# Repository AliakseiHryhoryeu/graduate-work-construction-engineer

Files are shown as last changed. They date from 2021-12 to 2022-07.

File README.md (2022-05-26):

# Graduate work. Construction engineer.

- Model building created in Revit 2020
- The calculation of the roof slab was carried out in Robot 2020
- A1 sheets were made in Autocad 2020
- An explanatory note was made in Microsoft Word 2019

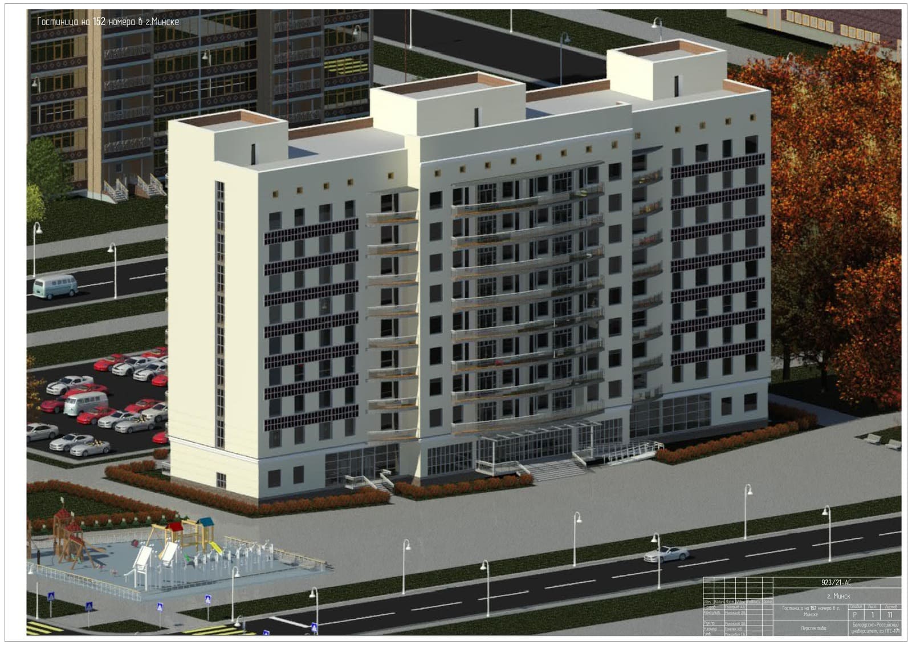
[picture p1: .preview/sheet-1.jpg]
sheet-1

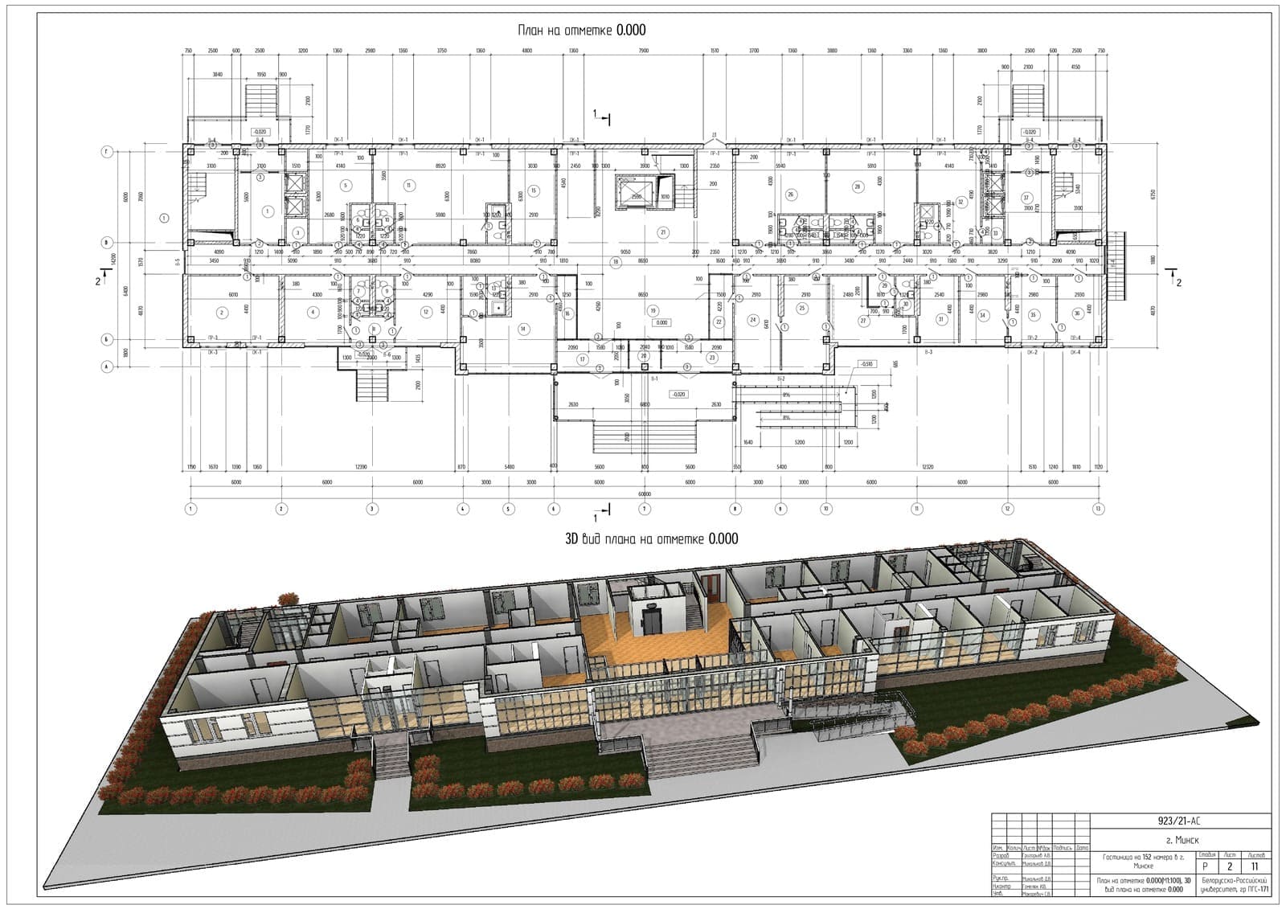
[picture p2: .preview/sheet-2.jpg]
sheet-2

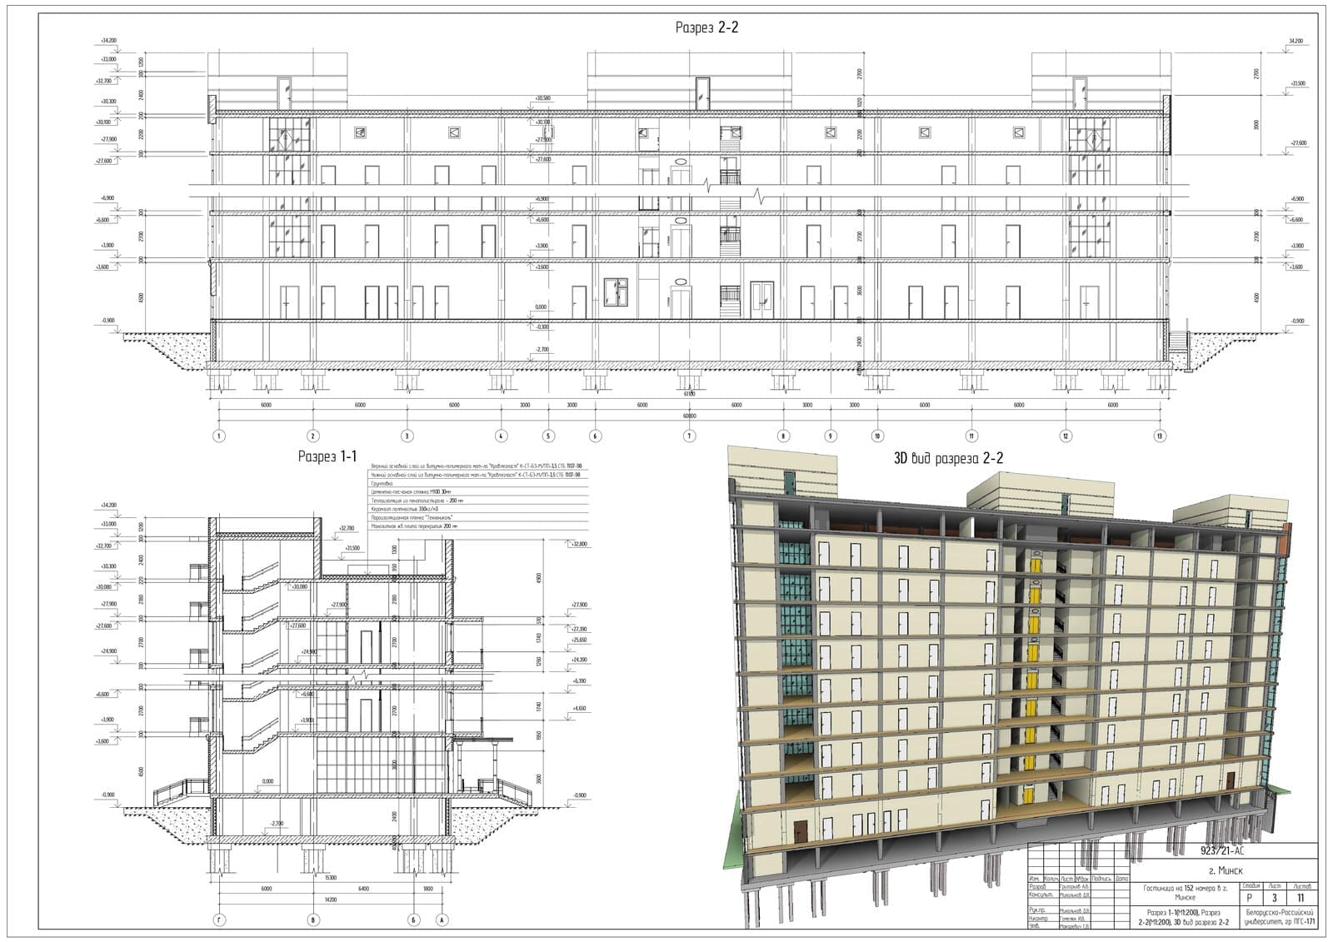
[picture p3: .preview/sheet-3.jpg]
sheet-3

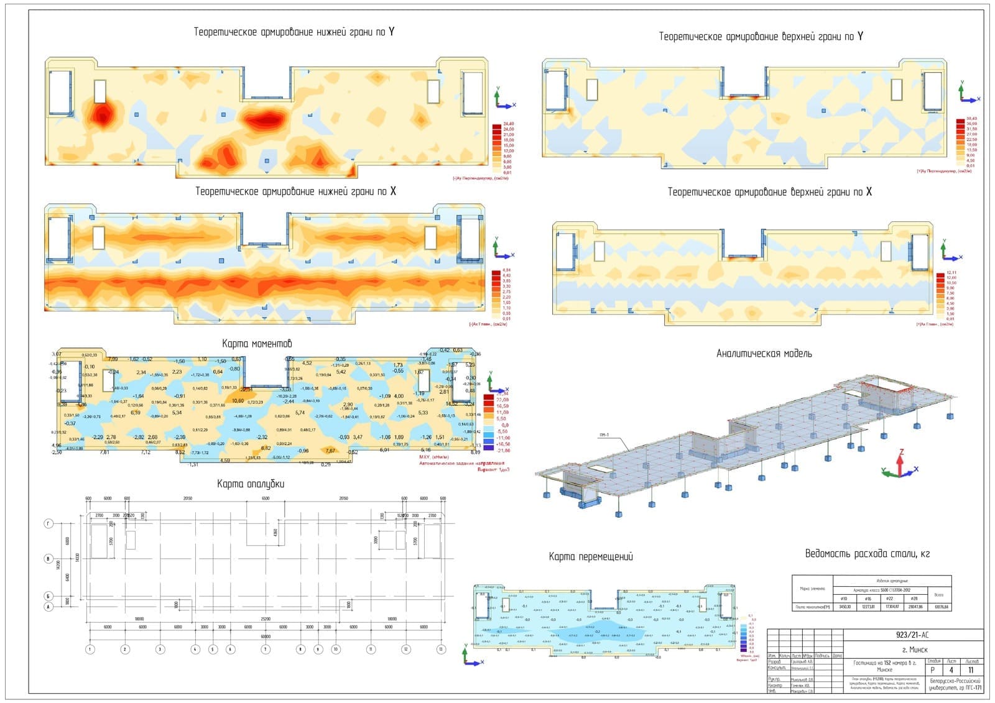
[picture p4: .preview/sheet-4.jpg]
sheet-4

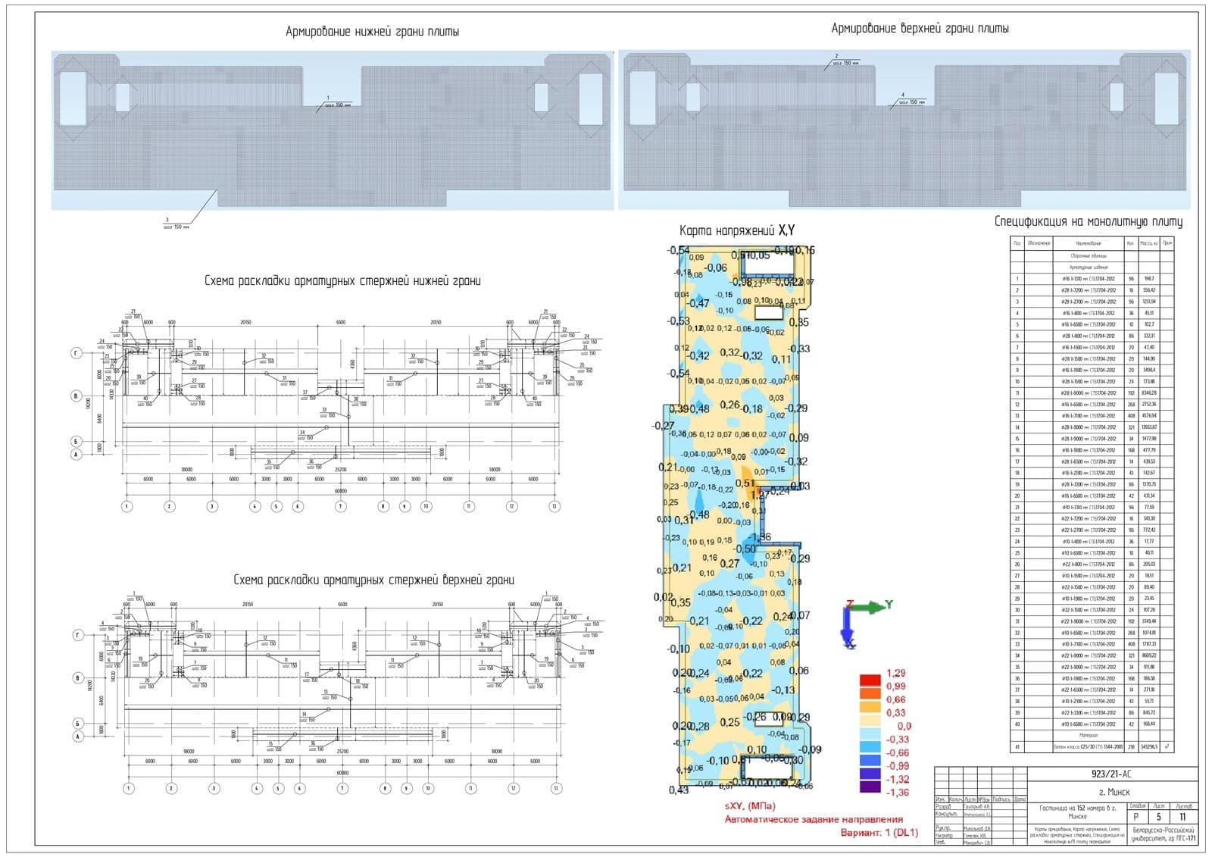
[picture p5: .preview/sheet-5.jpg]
sheet-5

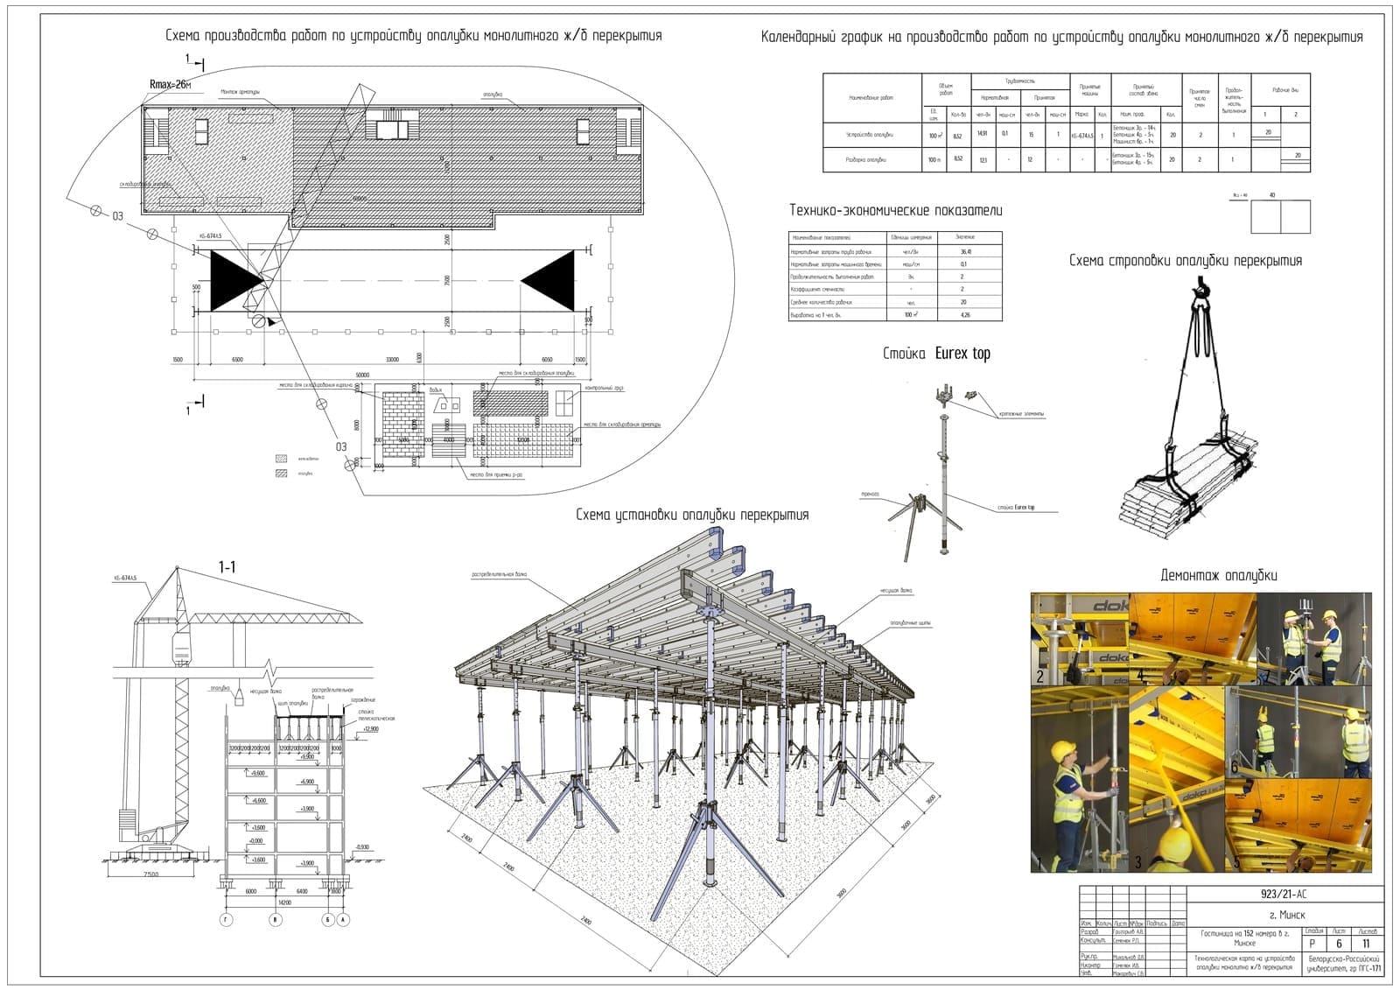
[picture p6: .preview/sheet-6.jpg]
sheet-6

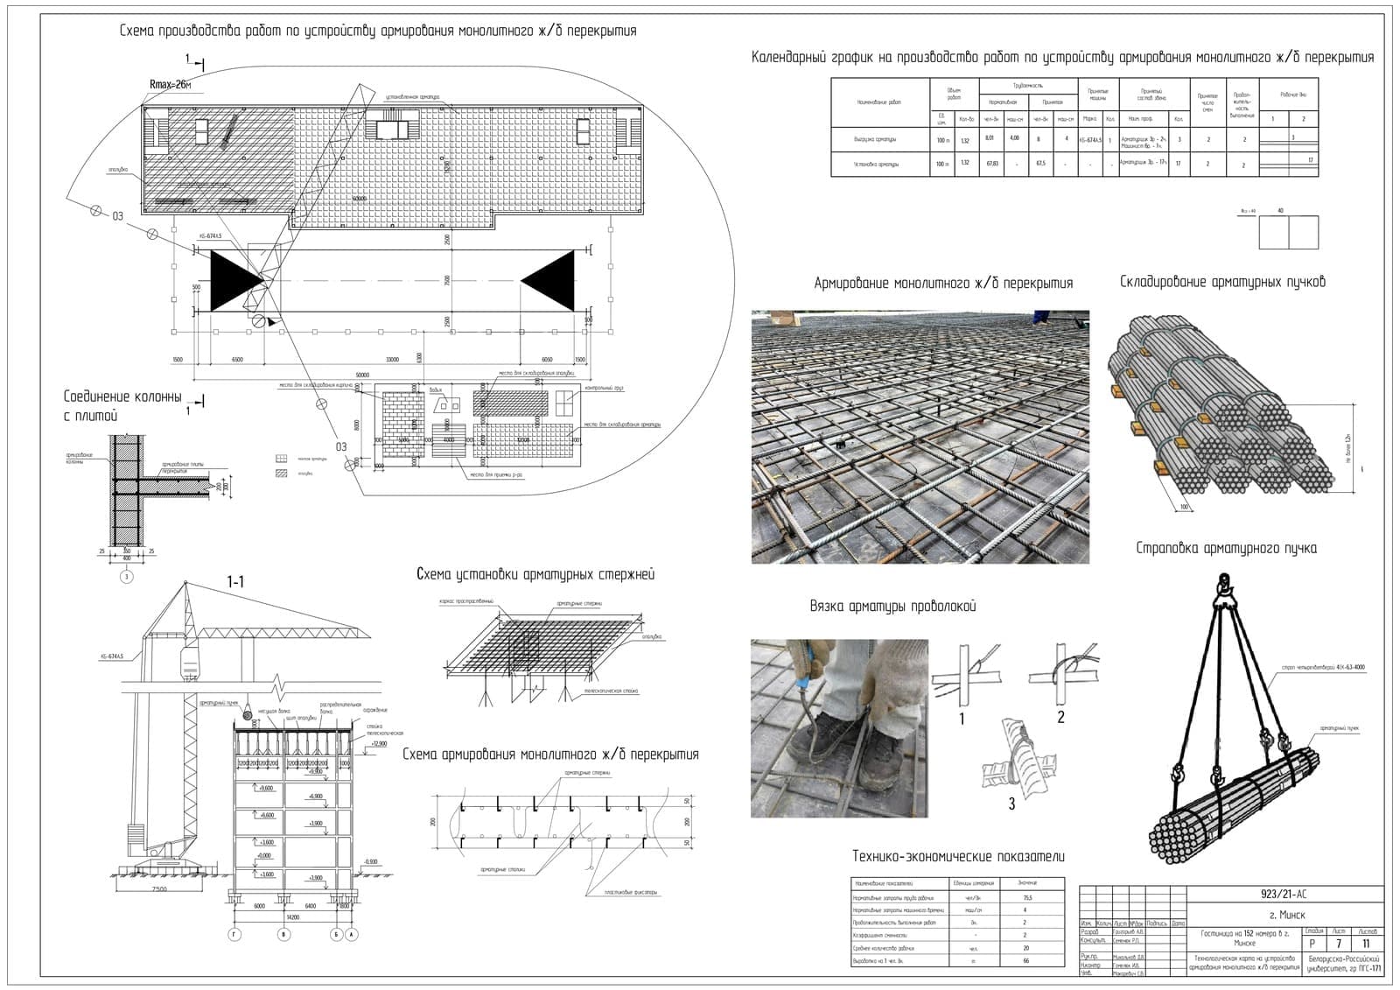
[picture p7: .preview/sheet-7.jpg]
sheet-7

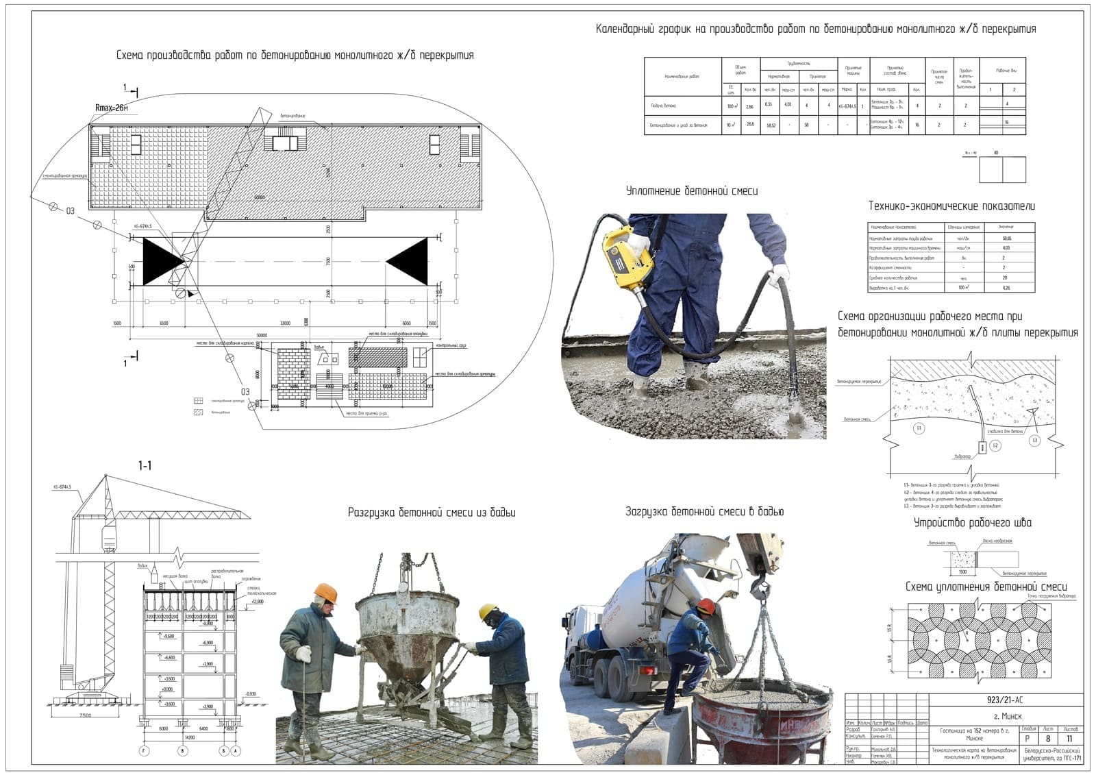
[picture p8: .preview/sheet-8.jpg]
sheet-8

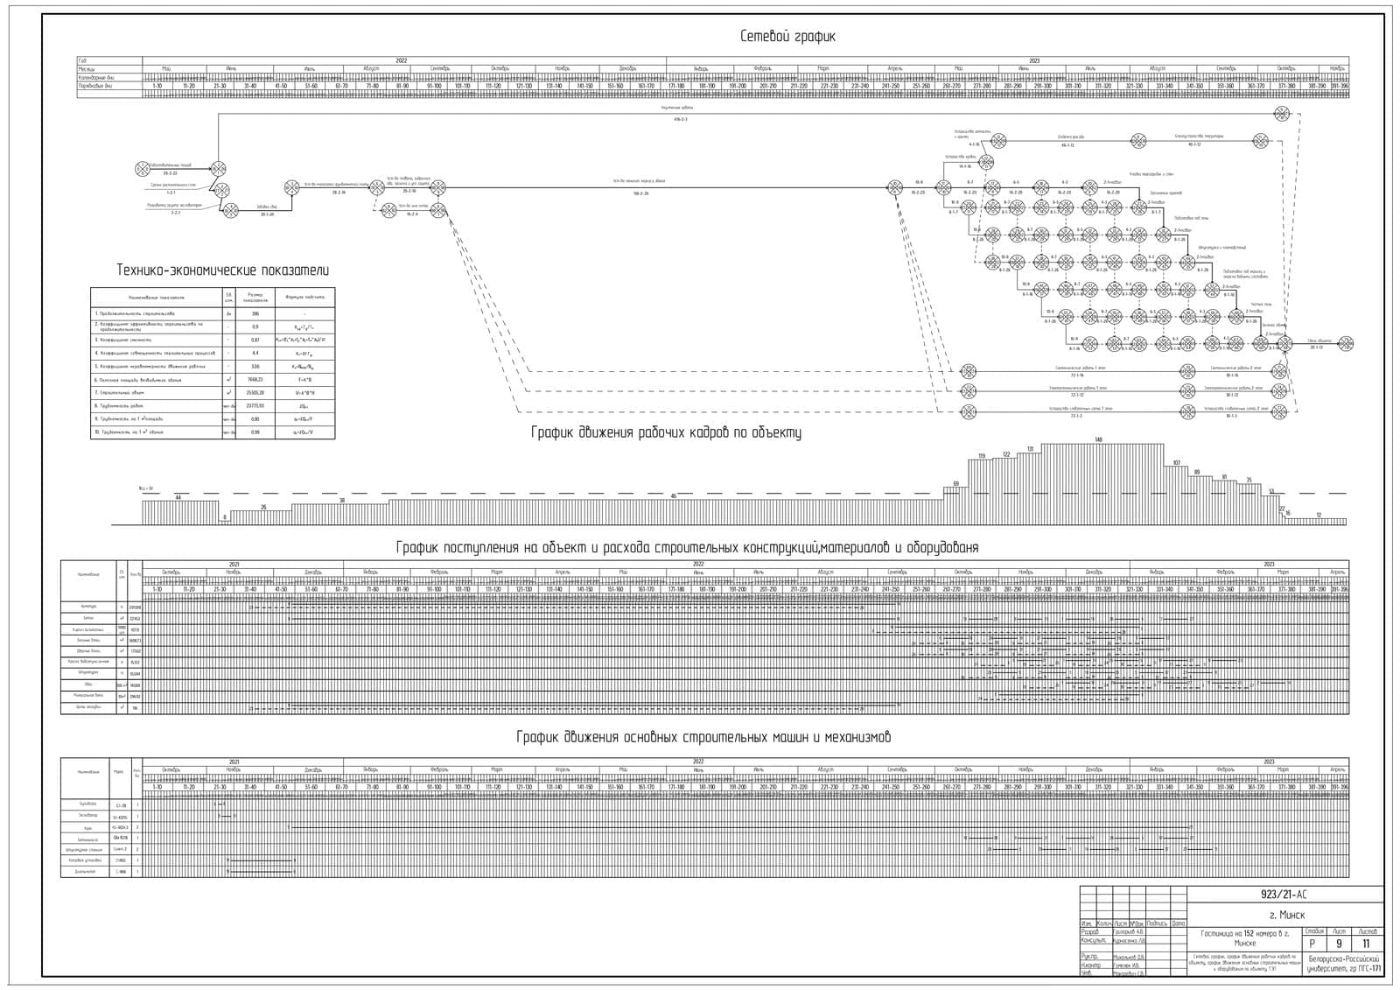
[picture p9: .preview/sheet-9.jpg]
sheet-9

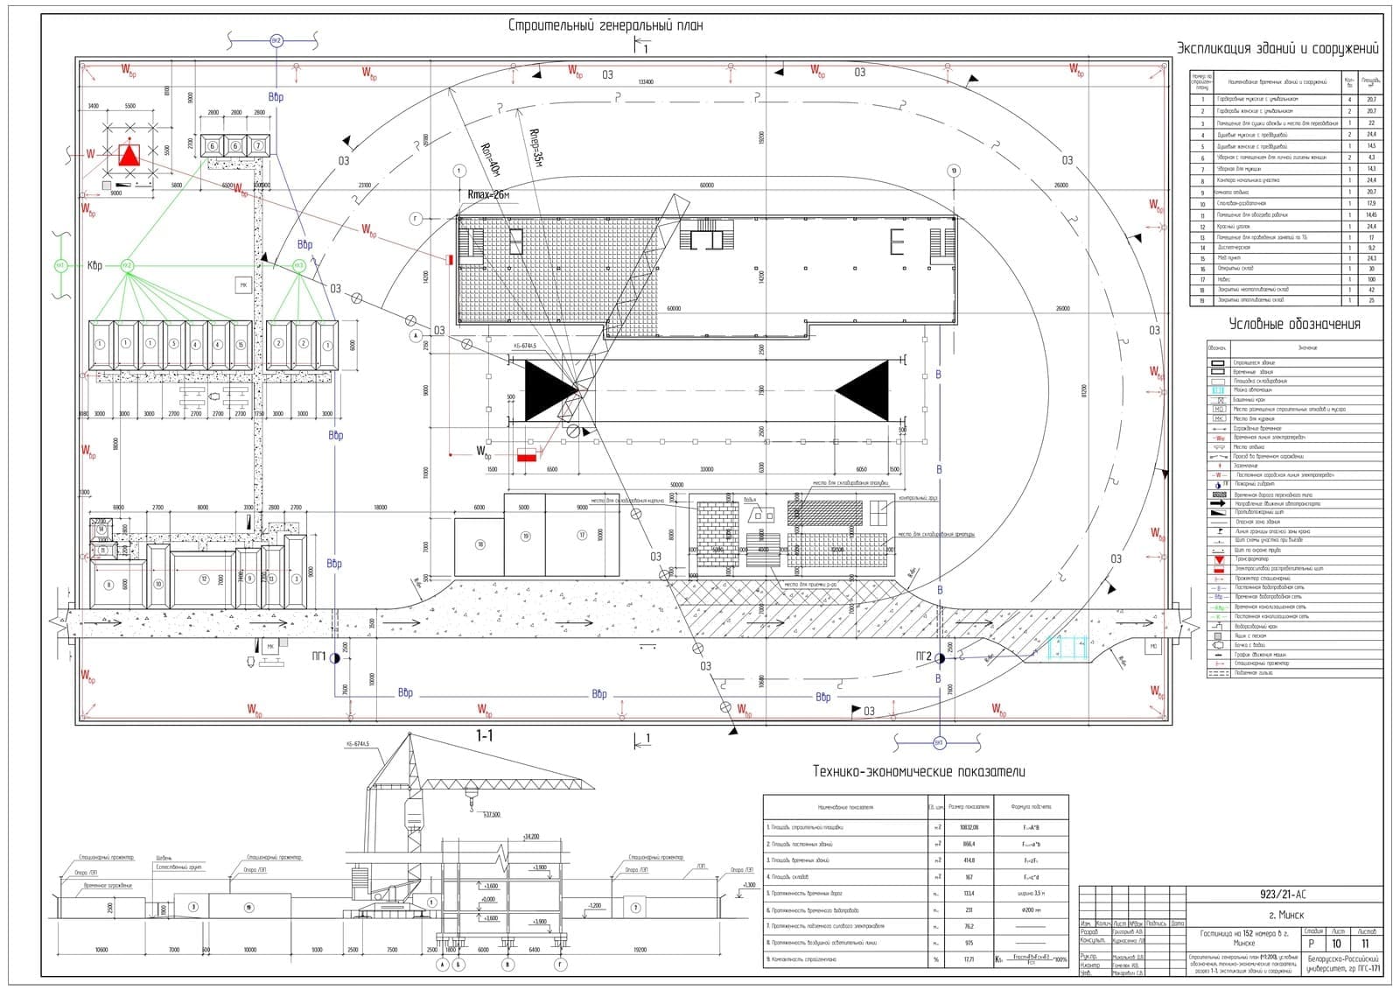
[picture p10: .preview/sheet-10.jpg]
sheet-10

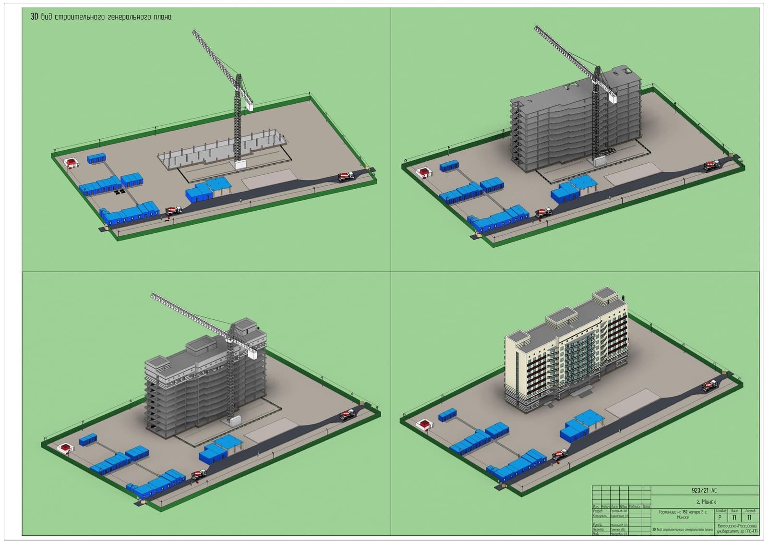
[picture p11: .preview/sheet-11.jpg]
sheet-11


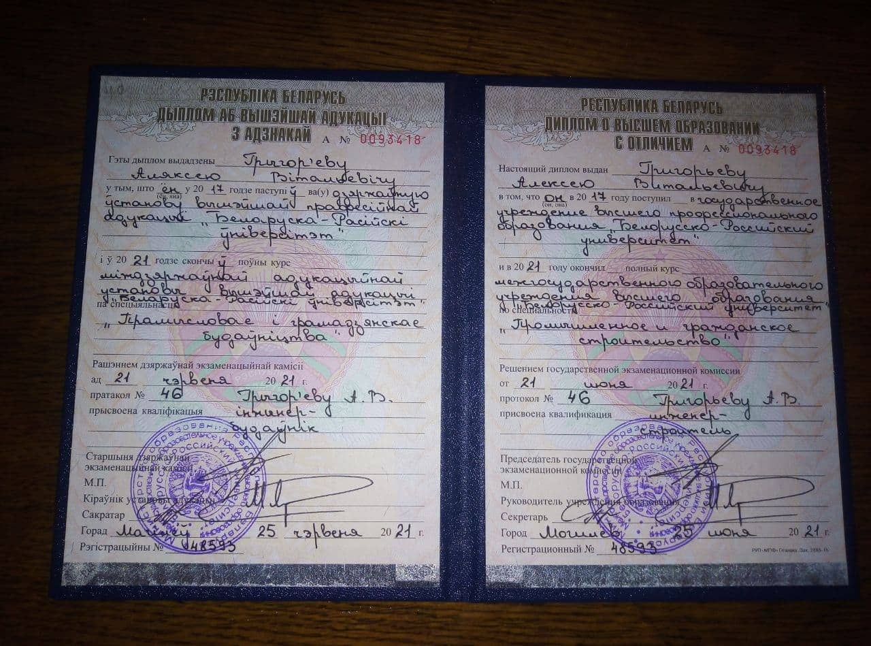
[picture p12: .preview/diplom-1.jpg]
diplom-1

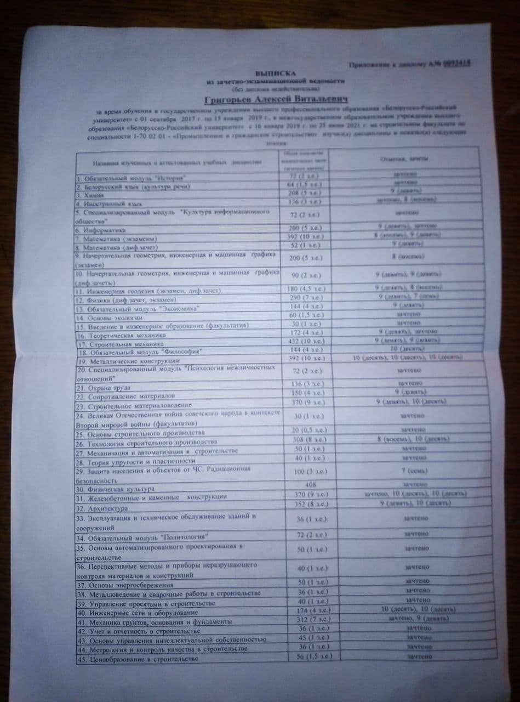
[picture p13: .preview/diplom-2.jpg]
diplom-2

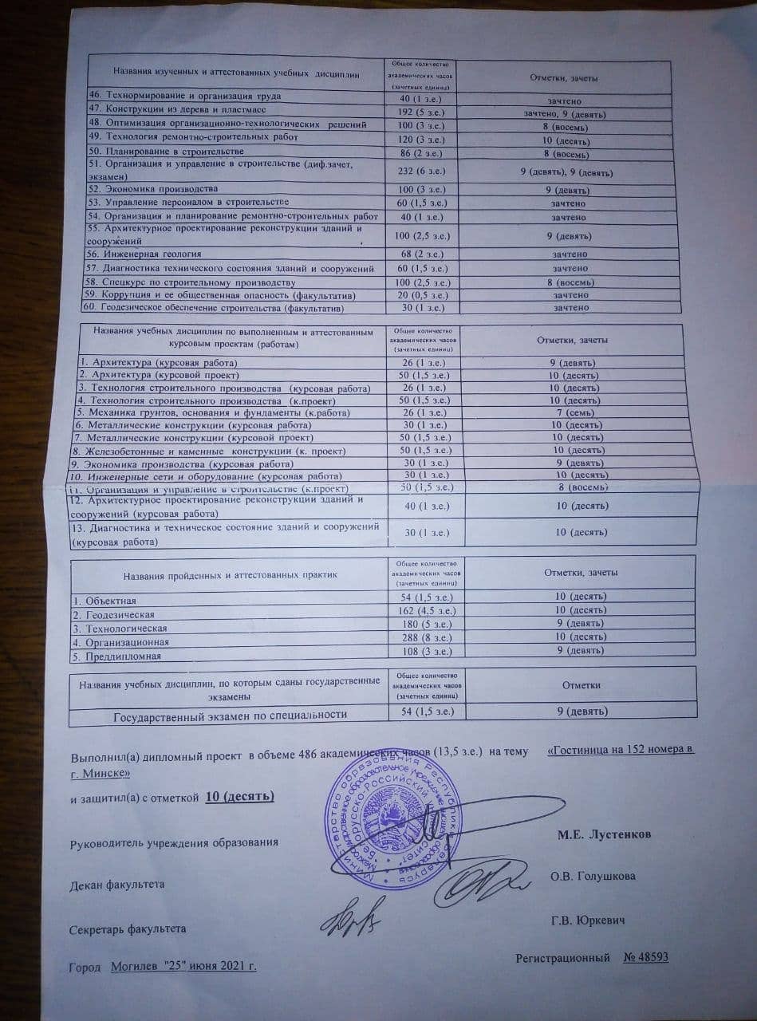
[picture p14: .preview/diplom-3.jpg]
diplom-3

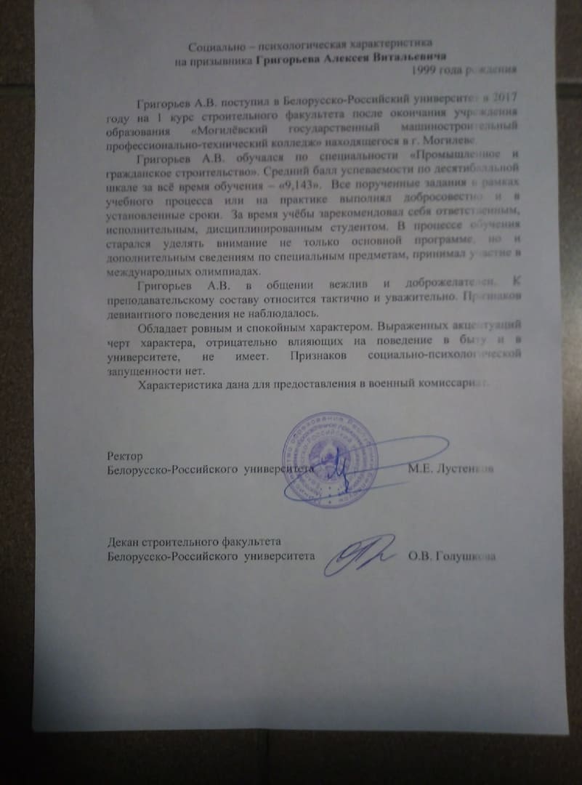
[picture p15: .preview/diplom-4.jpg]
diplom-4


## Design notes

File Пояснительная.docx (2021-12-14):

Анатацыя

Дыпломны праект распрацаваны на тэму «Гасцініца на 152 нумары ў г. Мінску».

Аўтар праекту – Грыгор’еў Аляксей Вітальевіч, студэнт будаўнічнага фукальтэту на кафедры «Прамысловае і грамадзянскае будаўніцтва» Беларуска-Расійскага універсітэта.

Кіраўнік дыпломнага праекту – Міхалькоў Дзмітрый Уладзіміравіч.

Год распрацоўкі – 2021.

Дыпломны праект складаецца з тлумачальнай запіскі на 148 старонак і 11 лістоў графічнай часткі. У запіску таксама ўключаны прыкладанні і 77 выкарыстаных крыніц літаратуры.

У архітэктурна-будаўнічнай частцы былі распрацаваныя аб'ёмна-планавальныя і канструктыўныя рашэнні, генеральны план, праведзены цеплатэхнічны разлік вонкавай сцяны і канструкцыі пакрыцця.

Пры выкананні разлікова-канструктыўнай часткі была разлічана і сканструявана маналітная жалезабетонная пліта пакрыцця.

У тэхналагічнай частцы распрацаваны тэхналагічныя карты прылада апалубкі маналітнага жалезабетоннага перакрыцця, прылада армавання маналітнага жалезабетоннага перакрыцця, бетанаванне маналітнай пліты перакрыцця.

У арганізацыйнай частцы быў распрацаваны праект арганізацыі будаўніцтва ў складзе будгенплана і сеткавага графіка.

У эканамічнай частцы былі праведзены фінансавыя разлікі ў цяперашнім узроўні коштаў: лакальны каштарыс на агульнабудаўнічыя працы, аб'ектны каштарыс, зводны каштарысны разлік.

Па ахова працы была распрацавана інструкцыя па ахове працы для бетоншчыка.

У раздзеле "Энерга- і рэсурсазберажэнне» былі распрацаваны мерапрыемствы: па эканоміі электраэнергіі і цеплавой энергіі.

Введение

Тема дипломного проекта: «Гостиница на 152 номера в г. Минске».

Проектируемое здание представляет собой десятиэтажное здание с высотой типового этажа 3 м. На плане здание в прямоугольной форме. Между этажами сообщение организовано при помощи лестниц и лифтов.
На этажах запроектированы все административные помещения.
Конструктивные особенности данного здания, а именно использование монолитных несущих конструкций способствуют созданию любой формы в плане. Данная особенность играет весомую роль при проектировании нетиповых зданий. Также использование монолитного каркаса способствует экономии железобетона вследствие индивидуально расчета конструкций под заданную нагрузку.
В технологические особенности здания стоит включить его сложную форму, которая будет оказывать существенное влияние на выбор способов монтажа конструкций и размещение строительной техники.

Строительство, являясь материалоемким, трудоемким, капиталоемким, энергоемким и наукоемким производством, содержит в себе решение многих локальных и глобальных проблем, от социальных до экологических.

У строительных организаций существует насущная потребность в крупных объемах строительно-монтажных работ с привлечением свободных трудовых ресурсов, особенно из числа безработных граждан.

В дипломном проекте решается комплекс взаимосвязанных задач по проектированию строительства административного здания и увязки технологических процессов всего периода строительства.

На этапе проектирования предусмотрено применение современных методов производства строительно-монтажных работ обеспечивающих, создания четкого ритма производства, повышения качества работ и сокращение сроков строительства.

1 Архитектурно-строительный раздел

1.1 Исходные данные

Площадка строительства располагается на ул. Грушевской в г. Минск, на свободной от застройки территории.

Климатический район строительства II-В по СНБ 2.04.02-2000[2]

В соответствии с СП 2.04.01.2020[1] расчетная температура наружного воздуха составляет минус 24°С (температура наиболее холодных суток обеспеченностью 0,92).

На основании СН 2.01.05[3] значение ветрового давления принято 21 кг/м2 (0,21 кПа), а нормативное значение веса снегового покрова составляет 145 кг/м2 (1,45 кПа) для 2а района территории страны. Преобладающие ветры западного направления со средней скоростью ветра до 4 м/сек.

Основанием фундаментов служат грунты со следующими расчетными характеристиками: глина полутвердая, среднеоднородный, средней прочности ρ= 1,89 г/см³, сn= 0,5кПа, φ=35º, Е=14,4МПа; суглинок прочный полутвердый, средней прочности ρ= 2,15 г/см³, сn= 45 кПа, φ=17º, Е=29 МПа; песок крупный, средней однородности, средней прочности, водонасыщенный, прочный ρ= 2,02 г/см³, сn= 31 кПа, φ=24º, Е=26,1МПа.

Грунтовые воды на площадке строительства не вскрыты. Во влажные периоды года возможно появление верховодки, а также вод спорадического распространения в прослоях песка в супесях пылеватых и моренных.

1.2 Генеральный план

Генплан разработан на основании ТКП 45-3.01-155-2009[24].

Компоновка генплана выполнена с учетом специфики рельефа данной местности, рационального использования отведенной территории, санитарных и противопожарных норм.

Генеральный план запроектирован в соответствии с проектом застройки.

При строительстве максимально по возможности сохраняются существующие деревья, кроме того, для снижения запыленности воздуха, защиты почвы от ветровой и водной эрозии, обеспечения нормативных санитарно-гигиенических условий на свободной от застройки и твердого покрытия территории, предусмотрено устройство газонов и цветников, посадка кустарника и деревьев лиственных и хвойных пород.

Пешеходные дорожки, площадки и тротуары выполнены из мелкоштучной бетонной плитки по СТБ 1071-2007[54].

За относительную отметку 0,000 принят уровень чистого пола первого этажа, что соответствует отм. 109,98 на генплане.

Площадка планируется уклонами 3⁰ - 5⁰ для быстрого и организованного сброса воды в водоотводные канавы и пониженные места.

Покрытие дорог устраивается из асфальтобетона толщиной 6 см на песчаном выравнивающем слое толщиной 20 см и щебеночном основании 15 см.

Проектом предусматривается снятие и временное хранение плодородного слоя почвы с учетом последующего использования для благоустройства территории проектируемого.

На земельном участке предусматривается устройство площадки для отдыха с установкой скамеек.

Для обеспечения благоприятных санитарно-гигиенических условий проектом предусмотрено устройство твердых беспыльных покрытий и озеленение территории газонами, хвойными и лист

венными деревьями.

Технико-экономические показатели генплана приводятся в таблице 1.1.

Таблица 1.1 – ТЭП генплана

Наименование показателя | Ед. изм. | Количество
1 | 2 | 3
Площадь участка | м² | 52000
Площадь застройки | м² | 2801,14
Площадь озеленения | м² | 24173,4
Площадь твердого покрытия | м² | 9463,9
К застр = S застр / S уч | | 0,05
К озел = S озел / S уч | | 0,11
К тв. покр.= S тв. покр. / S уч | | 0,18

Таблица 1.2 – Экспликация генплана

№ п/п | Наименование показателя
1 | 2
1 | Гостиница на 152 номера
2 | Магазин
3 | Жилое здание
4 | Жилое здание
5 | Офисный центр
6 | Жилое здание
7 | Жилое здание
8 | Школа
9 | Жилое здание
10 | Жилое здание
11 | Жилое здание

Расчёт чёрных отметок:

Нч. = Нмл.г.+h·(m/d) (1.1) где: Нч - черная отметка, м;

Нмл.г - отметка младшей горизонтали, м;

h - высота сечения рельефа;

m - расстояние от младшей горизонтали до необходимой точи;

d - расстояние по перпендикуляру между горизонталями.

Н1=110,00+0,5·(114,62/125,45=110,45м;

Н2=110,00+0,5· (85,9/134,9)=110,31м;

Н3=110,00+0,5· (0,45/128,6)=110,00м;

Н4=109,00+0,5· (3,59/4,14)=109,93м;

Н5=110,50+0,5·(1/50)=110,60м;

Н6=109,00+0,5·(4,4/73)=109,80м;

Н7=110,00+0,5·(0,32/95)=110,00м;

Н8=110,00+0,5·(1,62/95)=110,01м;

Расчёт красных отметок:

Hкр=Hкрmax-i·l (1.2)

где: Hкр- необходимая красная отметка, м;

Hкрmax - старшая красная отметка, м;

i - уклон спланированной поверхности, i=0.004;

l - длина стороны здания, м.

Принимаем Нчmax = Нкрасн. =110,45м, тогда:

Н1=110,45м;

Н2=110,45-0,004·50=110,25м;

Н3=110,25-0,003·90=109,98м;

Н4=109,98+(0,003·9+0,004·7)=110,03м;

Н5=110,03-0,003·27=109,95м;

Н6=109,95+0,004·30,5=110,07м;

Н7=110,03+0,004·30,5=110,15м;

Н8=110,45-0,003·90=110,18м;

1.3 Объёмно-планировочное решение

При разработке проектного решения учтены требования по организации общественных учреждений:

- создана рациональная, функционально обоснованная организация внутреннего пространства, учитывающая назначение помещений, поточность и характер технологических процессов;

- соблюдены санитарно-гигиенические требования;

- обеспечены оптимальные пространственные параметры (величина и форма помещений, размеры производственных коридоров, наличие и размеры проходов между различными видами оборудования и мебели);

- организована рациональная технологическая горизонтальная и вертикальная взаимосвязь между функциональными группами помещений;

- соблюден принцип поточности.

Объемно - планировочное решение по проектированию гостиничного комплекса определено:

- функциональным назначением блоков комплекса (состав помещений, их площадь, высота, взаимосвязь и группировка, технологические потоки, санитарно - гигиенические требования производства);

- градостроительными и природно-климатическими факторами (конфигурация и величина участка строительства, его ориентация по странам света и к господствующим ветрам, рельеф, климатический район строительства, характер окружающей застройки и природной среды, связь с транспортными магистралями, улицами, проездами);

- архитектурно - художественными задачами (художественный образ здания в соответствии с его месторасположением в условиях городской застройки, необходимость создания единой архитектурной композиции);

- экономическими требованиями (эффективное использование площади и объема зданий, сокращение площади коммуникационных, технических и прочих вспомогательных помещений).

В дипломном проекте рассматривается проектирование гостиницы.

Здание оснащено системами приточно-вытяжного вентилирования, холодного и горячего водоснабжения, центрального отопления, канализации, электроснабжения.

Таблица 1.3 – Экспликация помещений

Номер помещения | Наименование | Площадь, м²
1 | 2 | 3

На отметке 0,000
1 | Лифтовой холл | 38,06
2 | Касса по продаже авиа и жд билетов | 2628
3 | Электрощитки | 2,35
4 | Парикмахерская | 19,79
5 | Экскурсовод | 21,84
6 | Санитарный узел | 3,09
7 | Санитарный узел | 1,90
8 | Тамбур | 5,10
9 | Санитарный узел | 1,90
10 | Санитарный узел | 3,09
11 | Турагенство | 45,93
12 | Парикмахерская | 19,56
13 | Санитарный узел | 3,10
14 | Служебное помещение | 29,20
15 | Аптека | 20,13
16 | Регистратура | 5,54
17 | Тамбур | 9,46
18 | Коридор | 114,14
19 | Вестибюль | 37,80
20 | Охрана | 4,12
21 | Лифтовой зал | 63,06

Окончание таблицы 1.3

1 | | 2 | 3
22 | | Гардероб | 6,70
23 | Тамбур | | 9,46
24 | Кабинет главного инженера | | 18,27
25 | Секретарь | | 18,47
26 | Камера хранения | | 32,66
27 | Кабинет директора | | 17,59
28 | Бухгалтерия | | 28,67
29 | Прихожая | | 3,42
30 | Санитарный узел | | 3,10
31 | Химчистка | | 11,36
32 | Помещение главной горничной | | 21,40
33 | Хоз. кладовая | | 2,35
34 | Кладовая грязного белья | | 13,32
35 | Помещение кладовщика | | 13,32
36 | Кладовая грязного белья | | 12,74
37 | Лифтовой холл | | 35,79

На отметке +3.900
38 | Лифтовой холл | | 38,11
39 | Двухместный номер | | 25,76
40 | Двухместный номер | | 24,36
41 | Двухместный номер | | 24,93
42 | Двухместный номер | | 24,28
43 | Двухместный номер | | 24,17
44 | Двухместный номер | | 28,63
45 | Одноместный номер | | 17,91
46 | Одноместный номер | | 17,89
47 | Трехместный номер | | 28,49
48 | Одноместный номер | | 20,18
49 | Одноместный номер | | 20,18
50 | Коридор | | 120,41
51 | Трехместный номер | | 46,3
52 | Одноместный номер | | 14,69
53 | Одноместный номер | | 14,84
54 | Двухместный номер | | 33,91
55 | Двухместный номер | | 21,03
56 | Двухместный номер | | 21,33
57 | Двухместный номер | | 29,35
58 | Лифтовой холл | | 15,17
59 | Двухместный номер | | 22,66

1.4 Конструктивные решения

Десятиэтажное здание с каркасом из монолитного железобетона. Высота этажа первого этажа– 3,9 м, типовых этажей – 3.0 м размеры в Осях:

- по осям: 1-13 – 60 м;

- по осям: А-Г – 14.2 м.

Конструктивно представляет собой каркасное здание со штучным заполнением наружных стен из газосиликатных блоков 300 мм.

1.4.1 Фундаменты

Проектом предусмотрено устройство монолитной фундаментной плиты. Армирование фундаментов осуществляется сварными арматурными каркасами и вязаными сетками, а также отдельными стержнями без использования сварочных соединений на строительной площадке.

Низ подошвы фундамента залегает на отметке -3,200 м. После монтажа инженерных коммуникаций все отверстия в стенах тщательно заделываются бетоном С12/15. Поверхности бетонных элементов, соприкасающиеся с грунтом окрасить битумно-полимерным составом общей толщиной 4 мм. Гидроизоляция по всем наружным стенам выполняется укладкой двух слоев гидроизола, склеенных сплошным слоем нефтебитумной мастики по слою цементного раствора состава 1:2, толщиной 20 мм. Вертикальная гидроизоляция стен со стороны грунта выполняется из битумно-полимерных составов путем нанесения их на изолируемую поверхность толщиной не менее 4 мм.

1.4.2 Стены

Конструктивно здание каркасное со штучным заполнением наружных стен, с армированием этого заполнения через три ряда кладки.

Вертикальные несущие конструкции цоколя здания - стены, выполняются из монолитного железобетона. Рабочие швы бетонирования выполнять по низу перекрытий.

Конструкция наружных стены здания запроектирована из газосиликатных блоков 300мм по ГОСТ EN 14063-1-2015[69], утеплителя из плит минеральной ваты по СТБ 1995-2009[11], отделочный слой выполнен из декоративной штукатурки.

Борозды, ниши, отверстия выполняются в процессе возведения кладки. Отверстия длиной менее 600 мм перекрываются арматурой диаметром 12 S500 с перепуском за грань отверстия на 250 мм (по одному стержню на 100 мм толщины стены). Отверстия более 600 мм перекрываются перемычками. Отверстия в панелях перекрытия и стенах для пропуска сантехнических коммуникаций и стояков электропроводки должны быть герметизированы в пределах каждого этажа (заделать цементным раствором с очесами).

Витражи спроектированы по индивидуальным проектам согласно СТБ 1609-2006[8]. Двери приняты согласно СТБ 2433-2015[16].

Все металлические элементы и детали крепления защитить от коррозии путем нанесения лакокрасочного покрытия: грунт ГФ-021 (1 слой), эмаль ПФ-133 (3 слоя).

Таблица 1.4 - Спецификация перемычек

Позиция | Обозначение | Наименование | | Количество | Масса 1 ед., кг | Прим.
1 | 2 | 3 | | 4 | 5 | 6
1 | Б1.038.1-3.02 | ПБ180.30-18-3,5Я1 | | 8 | 95,2
2 | Б1.038.1-3.02 | ПБ200.30-18-3,5Я1 | | 128 | 111,9
3 | Б1.038.1-3.02 | ПБ220.30-18-3,5Я1 | | 1 | 120,2
4 | Б1.038.1-3.02 | ПБ240.30-18-3,5Я1 | 81 | | 149,3
5 | Б1.038.1-3.02 | ПБ140.10-18-3,5Я1 | 208 | | 69,3
6 | Б1.038.1-3.02 | ПБ170.10-18-3,5Я1 | 16 | | 78,1
7 | Б1.038.1-3.02 | ПБ120.10-18-3,5Я1 | 68 | | 65,4

Таблица 1.5 Ведомость перемычек

Марка позиции | Схема сечения | Марка позиции | Схема сечения
1 | 2 | 1 | 2

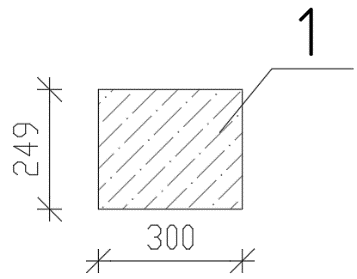
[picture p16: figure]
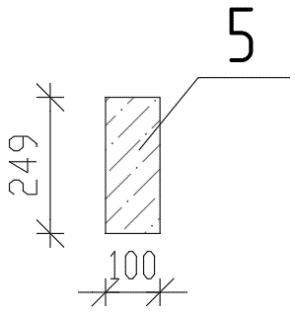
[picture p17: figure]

ПР-1 | | ПР-5

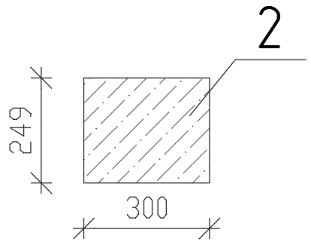
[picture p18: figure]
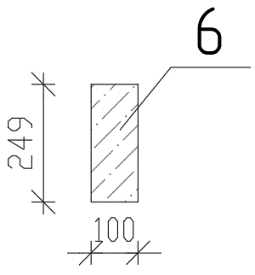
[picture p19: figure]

ПР-2 | | ПР-6

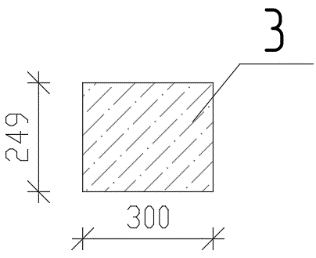
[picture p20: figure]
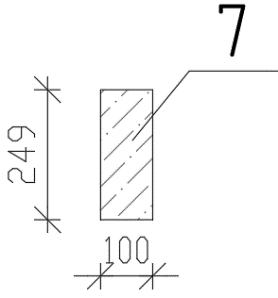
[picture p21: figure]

ПР-3 | | ПР-7

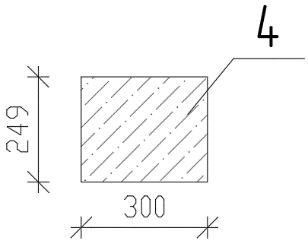
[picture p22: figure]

ПР-4

Таблица 1.6 - Спецификация заполнения проемов

Позиция | Обозначение | Наименование | Всего | Масса 1 ед., кг | Прим.
1 | 2 | 3 | 4 | 5 | 6

Витражи
В-1 | СТБ 1609-2006 | ОФ 36.116-АРСП1 | 1 | 78,1
В-2 | СТБ 1609-2006 | ОФ 36.54-АРСП1 | 3 | 62,9
В-3 | СТБ 1609-2006 | ОФ 36.120-АРСП1 | 1 | 72,6
В-4 | СТБ 1609-2006 | ОФ 36.25-АРСП1 | 4 | 58,4
В-5 | СТБ 1609-2006 | ОФ 36.16-АРСП1 | 1 | 41,5
В-6 | СТБ 1609-2006 | ОФ 36.90-АРСП1 | 1 | 68,7
В-7 | СТБ 1609-2006 | ОФ 27.19-АРСП1 | 9 | 37,4
В-8 | СТБ 1609-2006 | ОФ 27.54-АРСП1 | 9 | 64,8
В-9 | СТБ 1609-2006 | ОФ 27.60-АРСП1 | 9 | 69,1
В-10 | СТБ 1609-2006 | ОФ 27.55-АРСП1 | 9 | 65,4
В-11 | СТБ 1609-2006 | ОФ 27.16-АРСП1 | 9 | 36,5
В-12 | СТБ 1609-2006 | ОФ 27.26-АРСП1 | 18 | 45,9

Окна
ОК-1 | СТБ 939-2013 | ОДП2С1810х1360ОС2 | 8 | 23,1
ОК-2 | СТБ 939-2013 | ОДП2С1810х1510ОС2 | 128 | 36,2
ОК-3 | СТБ 939-2013 | ОДП2С1810х1670ОС2 | 1 | 26,1
ОК-4 | СТБ 939-2013 | ОДП2С1810х1810ОС2 | 72 | 31,1

Двери
Д1 | СТБ 2433-2015 | ДВ3 Д Г 21-9 | 208 | 18,5
Д2 | СТБ 2433-2015 | ДВ3 Д Г 21-12 | 16 | 19,7
Д3 | СТБ 2433-2015 | ДВ3 Д Г 21-16 | 12 | 21,5
Д4 | СТБ 2433-2015 | ДВ3 Д Г 21-7 | 68 | 16,2

1.4.3 Перекрытия

Перекрытия - сплошные монолитные, опертые на стены, перекрытия из бетона С30/37 толщиной 200 мм. Утепление торцевых участков перекрытия производится - пенополистирольными вкладышами. Армирование перекрытий осуществляется отдельными стержнями без использования сварочных соединений на строительной площадке.

Армирование в местах отверстий. Отверстия значительных размеров в железобетонных плитах окаймляются дополнительной арматурой сечением не менее сечения рабочей арматуры (того же направления), которая требуется по расчету плиты как сплошной.

Отверстия (проемы), если это требуется по расчету, обрамляют ребрами, размеры и армирование которых зависят от размеров отверстия, его формы, назначения и расположения в плане относительно балок перекрытия.

Дополнительная арматура, окаймляющая отверстия, должна быть заведена за края отверстия на длину не менее длины нахлестки.

Отпускная прочность бетона и железобетонных конструкций 70% в летнее время

Экспликация полов приведена в таблице 1.7.

Таблица 1.7 – Экспликация полов

Наименование или номер помещения | Тип пола | Схема пола или тип пола | Данные элементов пола (толщина основания и др., мм) | Площадь, м²
1 | 2 | 3 | 4 | 5

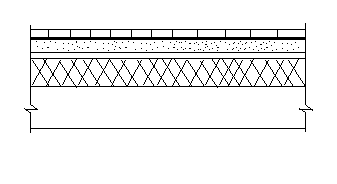
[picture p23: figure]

Пол подвала | Плиточный керамический | | 1.Плитка половая керамическая–8мм; 2.Клеющий состав 3.Цементно-песчаная стяжка-40мм 4.Гидроизоляция гидроизол-3мм 5.Пароизоляция 6.Утеплитель пенополистирол 240мм 7.Фундаментная плита 500мм
Санитарные узлы | Плиточный керамический | | 1.Плитка половая керамическая – 8 мм; 2.Прослойка из цемент. р-ра – 15 мм; 3.Стяжка из цементного р-ра – 20 мм; 4.Гидроизоляция – гидроизол – 3 мм; 5.Стяжка из цементного р-ра – 20 мм; 6.Плита перекрытия – 200 мм

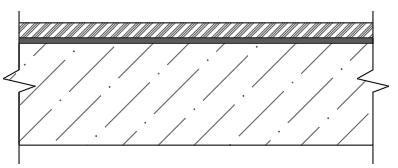
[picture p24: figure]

Все помещения кроме помещений номеров, санитарных узлов или подвала | Паркетный | | 1.Покрытие из паркетных досок – 27мм 2.Клей для паркета или мастика – 1мм 3.Плита перекрытия – 200мм

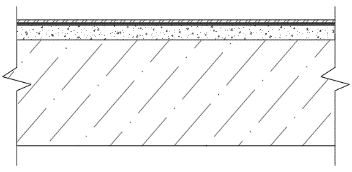
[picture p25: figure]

Номеров | Ламинатный | | 1. Ламинат – 8мм 2. Подложка – 2мм 3. Полиэтиленовая пленка – 1 слой 4. Стяжка из цементно-песчаного раствора – 20мм 5. Плита перекрытия – 200мм

1.4.4 Кровля

Кровля запроектирована плоской из рулонных материалов.

Кровля запроектирована рулонная с учетом требований строительных норм изложенных в СН 5.08.01-2019[10]

Водосток – организованный. В местах примыкания водоизоляционного ковра к парапету устраивается переходный бортик под углом 45. высотой не менее 100мм из цементно-песчаного раствора марки 50.

В местах примыкания к парапетам и в местах устройства водоприемных воронок основной водоизоляционный ковер усиливается дополнительными слоями рулонного кровельного материала.

1.4.5 Перегородки

Перегородки выполняются из газосиликатных блоков толщиной 100мм на растворе марки М50, с отделкой штукатурным составом из известкового раствора, с последующей отделкой декоративной штукатуркой или оклейкой обоями. В санузлах, моечных и других санитарных помещениях перегородки выполняются из газосиликатных блоков на растворе марки 50 толщиной 100мм, с последующей отделкой керамической глазурованной плиткой.

1.4.6 Наружная и внутренняя отделка

Фасад здания по всей высоте оштукатуривается и окрашивается акриловыми красками для наружных работ.

Оконные и дверные откосы оштукатуриваются и окрашиваются по цвету фасада.

Внутренние помещения отделываются в зависимости от видов помещений и требований санитарного контроля. Помещения с повышенными требованиями санитарного контроля отделываются плитками и окрашиваются водостойкими красками. Остальные помещения оштукатуриваются известковыми растворами и отделываются декоративными составами или оклеиваются обоями. Потолки подвесные из гипсокартона.

1.4.7 Инженерное оборудование

В проектируемом здании предусмотрено хозяйственно-питьевое водоснабжение от городской сети.

Канализация – хозяйственно-бытовая с выпуском в городскую сеть.

Отопление водное центральное, система однотрубная с чугунными нагревательными приборами типа МС-140. Теплоноситель – вода, с температурой 70-90 ⁰С.

Вентиляция осуществляется при помощи вентблоков.

Горячее водоснабжение осуществляется от внешней сети.

Слаботочные устройства – телефон, радио, интернет.

Электроосвещение – от внешней сети. Напряжение 380/220 В. Освещение лампами накаливания.

Санитарно-техническое оборудование – унитазы, умывальники, ванны, душевые кабины.

1.4.8 Теплотехнический расчет кровли

Сопротивление теплопередаче Rт, многослойных ограждений с последовательно расположенными слоями, определяем по формуле:

(1.3)

где - коэффициент теплоотдачи внутренней поверхности ограждающей конструкции по таблице 6.4 СП 2.04.01-2020;

- коэффициент теплоотдачи наружной поверхности ограждающей конструкции по таблице А.1 СП 2.04.01-2020;

- термические сопротивления отдельных слоев конструкции, определяемые по формуле:

(1.4)

где - толщина слоя;

- коэффициент теплопроводности теплоизоляционного слоя ограждающей конструкции в условиях эксплуатации.

Таблица 1.8 – Физические характеристики слоев покрытия

Поз | Наименование слоев | Толщина, ,м | Плотность кг/м3 | Коэффициент теплопроводности , Вт/м·°С | Коэффициент теплоусвоения , Вт/м2·°С
1 | 2 | 3 | 4 | 5 | 6
1 | Монолитная плита перекрытия | 0,3 | 2500 | 1,92 | 17,98
2 | Пароизоляционная плетнка ”Технониколь” | 0,001 | 600 | 0,17 | 3,53
3 | Керамзит | 0,1 | 200 | 0,11 | 1,22
4 | Теплоизоляция из пенополистирола | х | 125 | 0,050 | 0,63
5 | Цементно-песчаная стяжка М100 | 0,03 | 2400 | 1,74 | 16,77
6 | Два слоя битумно-полимерного материала ”Кровляэласт” К-СТ-БЭ-М/ПП-3,5 СТБ 1107-98 | 0,003 | 1200 | 0,22 | 5,96

Определяем термические сопротивления для каждого слоя конструкции по формуле (1.2):

R_1 =(0,2)/(1,92)=0,104 ((м^2 ∙°C)/(Вт))

R_2 =(0,001)/(0,17)=0,006 ((м^2 ∙°C)/(Вт))

R_3 =(0,01)/(0,11)=0,091 ((м^2 ∙°C)/(Вт))

R_5 =(0,03)/(1,74)=0,017 ((м^2 ∙°C)/(Вт))

R_6 =(0,003)/(0,22)=0,013 ((м^2 ∙°C)/(Вт))

Определим необходимое термическое сопротивление R.3тр принятого утеплителя. Нормативное сопротивление теплопередаче для совмещенных покрытий Rт.норм= 6,0 .

R_(1тр) =6,0-1/(8,7)-1/23-0,104-0,006-0,091-0,017-0,013==5,61 ((м^2 ∙°C)/(Вт))

Определяем толщину утеплителя по найденному значению :

x=R_(1тр) ∙λ=5,61∙0,050=0,28 м

Принимаем толщину утеплителя х=300мм.

Определяем требуемое сопротивление теплопередаче по формуле:

(1.5)

где – коэффициент учитывающий положение наружной поверхности ограждающей конструкции по отношению к наружному воздуху;

– расчетная температура, оС, внутреннего воздуха;

– расчетная температура, оС, наружного воздуха;

- нормативный перепад между температурой внутреннего воздуха и температурой внутренней поверхности.

Определяем требуемое сопротивление теплопередаче по формуле (1.5):

Находим сопротивление теплопередаче ограждающей конструкции, подставляя необходимые данные в формулу:

R_(1тр) =1/(8,7)+0,104+0,006+(0,3)/(0,05)+0,091+0,017+0,013+1/23=6,39=((м^2 ∙°C)/(Вт))

Сопротивление теплопередаче ограждающей конструкции Rт следует принимать не менее требуемого сопротивления теплопередаче Rт.тр, и не менее нормативного сопротивления теплопередаче Rт.норм.

Итак, Rт.тр = 0,80 < Rт = 6,39 > Rт.норм= 6,0 - условие выполняется.

Следовательно, толщина утеплителя покрытия проектируемого здания принята верно и составляет х=300мм.

1.4.9 Теплотехнический расчет наружной стены

Таблица 1.9 – Физические характеристики слоев наружной стены

Поз | Наименование слоев | Толщина, ,м | Плотность кг/м3 | Коэффициент теплопроводности , Вт/м·°С | Коэффициент теплоусвоения , Вт/м2·°С
1 | 2 | 3 | 4 | 5 | 6
1 | Газосиликатные блоки | 0,30 | 600 | 0,23 | 4,22
2 | Плита теплоизоляционная минераловатная ТЕХНОВЕНТ ЭКСТРА | х | 100 | 0,045 | 0,53
3 | Защитный слой декоративной штукатурки | 0,015 | 1600 | 0,52 | 7,0

Определяем термические сопротивления для конструкции:

R_1 =(0,3)/(0,23)=1,3 ((м^2 ∙°C)/(Вт))

R_3 =(0,015)/(0,52)=0,02((м^2 ∙°C)/(Вт))

Определим необходимое термическое сопротивление R.2тр принятого утеплителя. Нормативное сопротивление теплопередаче для совмещенных покрытий Rт.норм= 2,2 .

R_(1тр) =2,2-1/(8,7)-1/23-1,3-0,02=0,72 ((м^2 ∙°C)/(Вт))

Определяем толщину утеплителя по найденному значению :

x=R_(1тр) ∙λ=0,72∙0,045=0,0324 м=32,4мм

Принимаем толщину утеплителя в 35мм.

Определяем требуемое сопротивление теплопередаче по формуле:

(1.6)

где – коэффициент учитывающий положение наружной поверхности ограждающей конструкции по отношению к наружному воздуху;

– расчетная температура, оС, внутреннего воздуха;

– расчетная температура, оС, наружного воздуха;

- нормативный перепад между температурой внутреннего воздуха и температурой внутренней поверхности.

Определяем требуемое сопротивление теплопередаче по формуле (1.6):

Находим сопротивление теплопередаче ограждающей конструкции, подставляя необходимые данные в формулу:

R_m =1/(8,7)+1,3+0,02+(0,035)/(0,045)+1/23=2,256((м^2 ∙°C)/(Вт))

Сопротивление теплопередаче ограждающей конструкции Rт следует принимать не менее требуемого сопротивления теплопередаче Rт.тр, и не менее нормативного сопротивления теплопередаче Rт.норм.

Итак, Rт.тр = 0,80 < Rт = 2,256 > Rт.норм= 2,2 - условие выполняется.

Следовательно, толщина утеплителя покрытия проектируемого здания принята верно и составляет х=35мм.

2 Расчетно – конструктивный раздел

2.1 Расчет и конструирование перекрытия кровли в монолитном

железобетоне

Дипломный проект выполнен в монолитном железобетонном исполнении и включает в себя расчет и конструирование программным методом монолитного перекрытия. Расчет выполняется с применением программ Autodesk Robot Structural Analysis Professional 2021 путем интеграции 3D модели проекта из Autodesk Revit 2021. Результаты расчета и армирования экспортируются в изначальную модель для формирования необходимых чертежей.

Таблица 2.1 – Исходные данные

Тип здания | Гражданское
1 | 2
Размер здания в плане А х Б | 14,2х60,0 м
Количество этажей n1 | 10
Высота этажа Н1 | 3 м
Район строительства | г.Минск
Снеговая нагрузка S0 | 1,87 кПа

Таблица 2.2 – Характеристики материалов монолитного варианта

Конструкция | Класс бетона | Класс рабочей арматуры
Плита | С25/30 | S500

2.2 Подсчет нагрузок на плиту

Таблица 2.3 Нагрузки на плиту покрытия

Вид нагрузки | Нормативная нагрузка, кПа | | Расчетная нагрузка, кПа
1 | 2 | 3 | 4
Постоянная g:
ж/б плита (t=0,3м, ρ=25кН/м³) 0,3∙25=7,5 кПа | 7,5 | 1,35 | 10,125
Пароизоляционная пленка „Технониколь” (t=0,003 м, ρ=12 кН/м3) 0,003∙12=0,036 кПа | 0,036 | 1,35 | 0,0486
Керамзит(t=0,1 м, ρ=2 кН/м3) 0,1∙2=0,2 кПа | 0,2 | 1,35 | 0.27
Теплоизоляция из пенополистирола (t=0,2м, ρ=1,25 кН/м³) 0,20∙0,5=0,125 кПа | 0,1 | 1,35 | 0,135
Цементно-песчаная стряжка М100(t=0,03 м, ρ=24 кН/м³) 0,03∙24=0,72 кПа | 0,72 | 1,35 | 0,972

Окончание таблицы 2.3

1 | 2 | 3 | 4
Два слоя битумно-полимерного материала ”Кровляэласт” К-СТ-БЭ-М/ПП-3,5 СТБ 1107-98 (t=0,003 м, ρ=12,0 кН/м³) 0,003∙12=0,36 кПа | 0,036 | 1,35 | 0,049
Итого постоянная: | gk=8.617 | | gd=11.632
Переменная q: снег | 1,872 | 1,5 | 2,823

Расчет программным комплексом Autodesk Robot Structural Analysis 2021 представлен в приложении А.

3 Технологический раздел

3.1 Патентный поиск

3.1.1 Рулетка измерительная

Патент № 198374

Россия(RU)

G01B 3/10

Дата начала срока действия патента: 03.04.2020

Полезная модель относится к области измерительного инструмента и предназначена для линейных измерений объектов, а также расстояний между объектами.

Измерительная рулетка содержит корпус, измерительную ленту, фиксатор измерительной ленты, держатель с пишущим устройством, держатель вытяжного конца выпускаемой измерительной ленты, при этом держатель вытяжного конца выпускаемой измерительной ленты представляет собой соединительную ось, скрепляющую круглую по форме кромку, с креплением на вытяжном конце выпускаемой измерительной ленты, допускающая вращение на триста шестьдесят градусов по отношению друг к другу. Технический результат - повышение удобства пользования.

3.1.2 Подмости передвижные

Патент № 198374

Россия(RU)

E04G 1/24

Дата начала срока действия патента: 04.05.2019

Изобретение относится к передвижным подмостям и предназначено для проведения строительных и монтажных работ на небольшой высоте.

Техническим результатом является снижение времени на перемещение подмостей при проведении работ, обеспечение возможности передвижения подмостей без необходимости рабочему спускаться с рабочей площадки. Технический результат достигается тем, что подмости передвижные содержат закрепленную на раме рабочую площадку, при этом рама снабжена стойками, на которых закреплены опорные колеса, по крайней мере одно из которых снабжено тормозом, при этом тормоз содержит подпружиненный металлический стержень, размещенный вдоль стойки с возможностью упирания в поверхность колеса, при этом средство управления тормозом размещено выше рабочей площадки.

3.2 Выбор монтажных механизмов для возведения здания

Подбор монтажного крана осуществляем по основным техническим параметрам, исходя из следующих характеристик:

1. Грузоподъемность – Q.

2. Вылет стрелы – Lстр.

3. Высота подъема – Нк.

1. Грузоподъемность крана определяется по формуле (3.1):

(3.1)

где, Qэ – наибольшая масса монтируемого элемента, т;

Qс – масса строповочных устройств, т, Qс = 0,0292 т.

Применяем строп четырехветвевой 4СК-6,3 длиной 4 м, грузоподъемностью 6,3 т, весом 22 кг.

Для бункера с бетонной смесью грузоподъемность определяется по формуле (3.2):

(3.2)

где Vбет. – номинальная вместимость бункера, м³;

– объемная масса бетона, равная 2420 кг/м³;

Qб – собственная масса бункера, кг.

Рисунок 3.3 – Выбор монтажного крана

Вертикальная неповоротная бадья для бетона серии БН, также известна как "рюмка" или "колокольчик". Бадья изготавливается из углеродистой стали, имеет воронку для более удобной загрузки раствора и специальный металлический лоток для его выгрузки. В верхней части бадьи имеются два пояса жесткости, выполненные из швеллера. В нижней части бадьи для бетона установлен двухчелюстной затвор, выполненный в виде рычага, предназначенный для выгрузки бетона, в т. ч. порционно. При открытии специального клапана, бетон, под действием собственной массы, поступает в лоток.

Таблица 3.1 – Технические характеристики бадьи БН-2.0

№ п/п | Наименование | Значение
1 | 2 | 3
1 | Емкость бункера, м³ | 2,0
2 | Грузоподьемность, кг | 5000
3 | Масса, кг | 340

Габаритные размеры, мм
5 | Диаметр, D | 1420
6 | Высота, H | 2300

Определяем массу бункера с бетонной смесью по формуле (3.2):

Qэ = 2,0∙2,42+0,34 = 5,18 т.

Грузоподъемность крана определяется по формуле (3.1):

Q = 5,18+0,0292 = 5,21 т.

2. Максимальная высота подъема грузового крюка башенного крана определяется по формуле:

, (3.3)

где Hмг – расстояние от уровня стоянки крана до монтажного горизонта, Hмг = 34,200 м;

a – расстояние между нижней плоскостью монтируемого элемента и уровнем опоры перед установкой его в проектное положение, a = 0,5 м;

hэ – высота элемента в монтируемом положении, м, hэ = 2,3 м;

hгу – высота грузозахватного устройства, м, hгу = 4,0 м.

Определяем максимальную высоту по формуле (3.3):

Hк = 34,20+0,5+2,3+4,0 = 41,0 м.

3. Вылет стрелы определяется по формуле (3.4):

Lcтр = С+, (3.4)

где С – расстояние от оси крана до крайнего монтируемого элемента, м, С=26м;

∆Lстр – запас вылета стрелы, ∆Lстр = 2 м,

Lстр = 26 + 2 = 28 м.

Необходимые параметры крана:

– грузоподъемность Q = 5,21 т;

– высота подъема грузового крюка Нк = 41,0 м;

– вылет стрелы Lстр = 28 м.

На основании произведенных расчетов принимаем башенный кран КБ-674А.5

Таблица 3.2 – Технические характеристики крана КБ-674А.5

Параметры | КБ-674А.5
1 | 2
Максим.грузовой момент, тс. м | 400
Максим.грузоподъёмность, т. | 12,5
Грузоподъёмность при максим.вылете, т | 7,3
Вылет при горизонтальной стреле, м
Максимальный | 32
Минимальный | 3,5
При максимальной грузоподъёмности | 26
Максимальная высота подъёма c гор стрелой, м | 37,5
Мощность потребления электроэнергии, КВт | 147

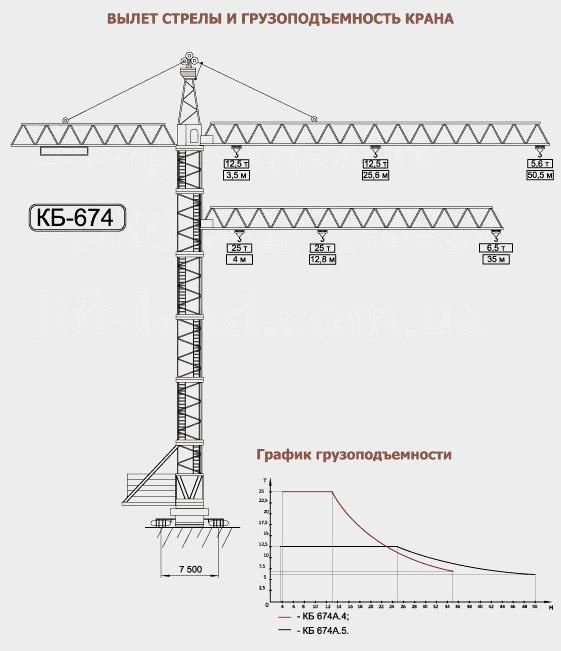
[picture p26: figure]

Рисунок 3.5 – Грузовая характеристика башенного крана

4. Определение привязок крана

Поперечная привязка башенного крана определяется по формуле (3.5):

С = Rпов + lбез, (3.5)

где Rпов = 5,5 м – радиус поворота задней части крана;

lбез = 2 м – безопасное расстояние от наиболее выступающей части здания до задней части крана.

С = 5,5+2=7,5м.

Длина подкрановых путей рассчитывается по формуле (3.6):

(3.6)

где Lп.п. - длина подкрановых путей, м;

lкр – расстояние между крайними стоянками крана, определяемое по чертежу, м;

Hкр – база крана, м;

lторм – величина тормозного пути крана, принимаемая не менее 1,5 м;

lтуп – расстояние от конца рельса до тупиков, равное 0,5 м.

Lп.л=31+8+2∙0,5+2*1,5=48м

Определяемая длина подкрановых путей корректируется в сторону увеличения с учетом кратности длине полузвена, т. е. 6,25 м. Минимально допустимая длина подкрановых путей составляет два звена (25 м). Таким образом, принятая длина путей должна удовлетворять следующему условию (3.7):

(3.7)

где 6,25 - длина одного полузвена подкрановых путей, м;

nзв - количество полузвеньев.

Lп.л.=6,25∙8=50 ≥ 25м

Расстояние от ограждения подкранового пути до оси ближнего к нему рельса определяют по формуле (1.7):

(3.8)

Где bk – ширина колеи крана, м;

Lбез – безопасное расстояние, принимается , м.

lп.л.=(5,5-0,5∙7,5)+0,7=2,45м

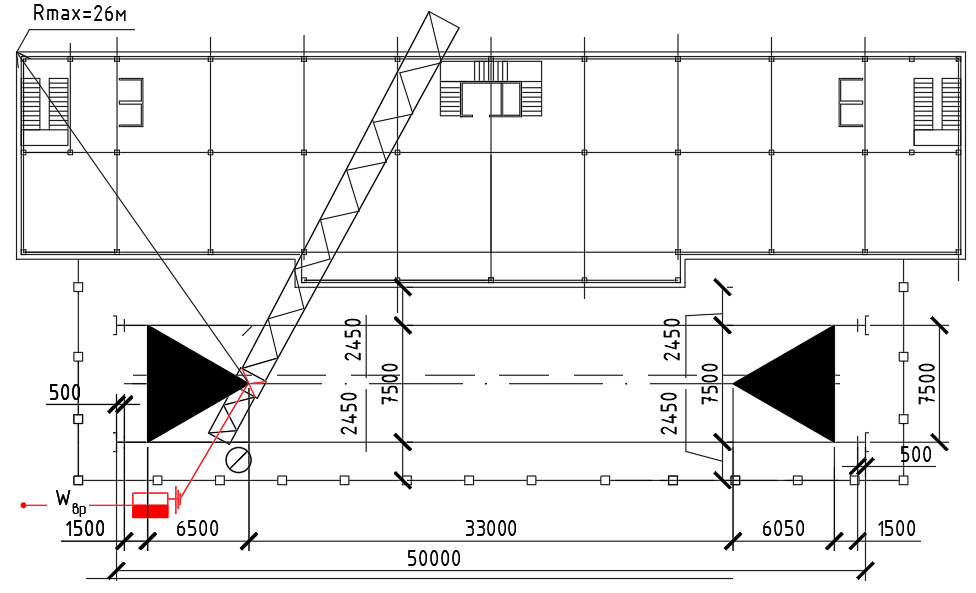
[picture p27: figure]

Определение зон влияния башенного крана.

При работе крана на строительстве здания можно выделить следующие опасные зоны:

Опасная зона вблизи строящегося здания (монтажная зона) – 6 м.

Рабочая зона крана – Rmax = 26 м – максимальный рабочий вылет стрелы крана.

Зона перемещения груза – Rпер = Rmax + 0,5Lmax = 26+9,75/2 = 40 м.

Опасная зона крана – Rоп = Rпер + lбез = 40+10=40 м.

Опасные зоны дорог, участки подъездов и подходов в пределах указанных зон, где могут находиться люди, не участвующие в совместной с краном работе, осуществляется движение транспортных средств или работа других механизмов, эти зоны на стройгенплане заштриховываются.

3.3 Технико-экономическое сравнение вариантов средств механизации (монтажных кранов)

При сравнении вариантов использования кранов разного типа необходимо обеспечить их сопоставимость, равную степень готовности к использованию в одних и тех же условиях, и режимах эксплуатации. Сравним два крана для производства строительно-монтажных работ: башенные краны КБ-674А.5 и КБ-503А.3.

Сравниваемые краны приведены в таблице 3.3.

Определим технико-экономические показатели использования сравниваемых кранов на примере монтажа стен из газосиликатных блоков и сведём их в таблицу 3.4.

Таблица 3.3 – Сравниваемые краны

Марка крана | Грузоподъемность Qк, т | Вылет стрелы max – min, м | Высота подъема крюка Нк, м, при максимальной грузоподъемности | Время работы крана в году Тгод, ч | Инвентарная расчетная стоимость Си. р., руб | Себестоимость машино-смены Смаш-смен, руб.
1 | 2 | 3 | 4 | 5 | 6 | 7
КБ-674 | 2,5…12,5 | 26…4,5 | 32,2 | 3075 | 150000 | 760
КБ-503А.3 | 5..15 | 65…3.2 | 36,3 | 3075 | 140000 | 1080

Таблица 3.4 – Сравнение вариантов кранов

Наименование показателя | Расчетная формула, обоснование пок-ля | Применяемый кран
| | КБ-674А.5 | КБ-503А.3
1 | 2 | 4
Заработная плата рабочих, р. | – | 1767 | 1767
Затраты на эксплуатацию строительных машин и механизмов, р. | – | 1308 | 1509
в т. ч. заработная плата рабочих, р. | – | 399 | 405
Материалы, р. | – | 2556 | 2556
Транспортные затраты, р. | – | 270 | 270
ОХР и ОПР, р. | – | 1236 | 1241
Итого себестоимость СМР, р. | – | 5901 | 6102
Плановая прибыль, р. | – | 1376 | 1387
Итого сметная стоимость СМР | – | 8513 | 8730
Трудоемкость, чел.-час. | – | 113,2 | 113,2
Выработка на 1 человеко-день. р. | | 601,63 | 620,31
Материалоотдача, р./р. | | 3,33 | 3,42
Материалоемкость, р./р. | | 0,30 | 0,29
Капитальные вложения в производственную базу, р. | | 45,45 | 52,53
Фондоотдача, р./р. | | 187,30 | 150,1
Фондоемкость, р./р. | | 0,005 | 0,006
Сметный уровень рентабельности, % | | 16,16 | 16,01

В результате применения первого варианта (КБ-674А.5) можно будет прогнозировать следующее: сметный уровень рентабельности выше и фондоотдача выше, общая сметная стоимость и фондоемкость меньше.

В результате экономического сравнения двух вариантов принимаем первый вариант (КБ-674А.5) как менее затратный и более рентабельный.

3.4 Технологическая карта на устройство опалубки монолитного ж/б перекрытия

3.4.1 Область применения.

Технологическая карта разработана на устройство опалубки монолитного ж/б перекрытия.

В состав карты входят следующие работы:

1. - опалубочные работы;

2. - распалубка конструкции плиты.

Работы производятся в весенне-летний период года в две смены.

3.4.2 Нормативные ссылки

При разработке данной технологической карты были использованы следующие нормативно-технические документы:

1. СН 1.03.01 «Возведение строительных конструкций зданий и сооружений» [41];

2. СТБ 1035-96 «Смеси бетонные. Технические условия» [42];

3. СТБ 1110-98 «Опалубка для возведения монолитных бетонных и железобетонных конструкций. Общие технические условия» [43];

4. СТБ 1544-2005 «Бетоны конструкционные тяжёлые. Технические условия» [44];

5. СП 5.03.01 «Бетонные и железобетонные конструкции» [45];

6. ТКП 45-2.04-153-2009 «Естественное и искусственное освещение. Строительные нормы проектирования» [46];

7. Правила по охране труда при выполнении строительных работ [27];

8. ГОСТ 5781-82 «Сталь горячекатаная для армирования железобетонных конструкций. Технические условия» [47];

9. ГОСТ 12.1.046-2014 «Система стандартов безопасности труда. Строительство. Нормы освещения строительных площадок» [48];

10. ГОСТ 12.4.059-89 «Система стандартов безопасности труда. Строительство. Ограждения предохранительные инвентарные. Общие технические условия» [49];

11. ГОСТ 12.4.089-86 «Система стандартов безопасности труда. Строительство. Пояса предохранительные. Общие технические условия» [50];

12. СТБ 1307-2012 «Смеси растворные и растворы строительные. Технические условия» [51];

13. СТБ 1704-2012 «Арматура ненапрягаемая для железобетонных конструкций. Технические условия» [12].

3.4.3 Характеристика применяемых материалов и изделий

Доставленные на строительную площадку материальные элементы складируют на приобъектных складах. Материалы и изделия, подлежащие обязательной сертификации, должны иметь сертификат соответствия.

Применяемые материалы и изделия при устройстве монолитной плиты:

1.Телескопические стойки «МОДОСТР».

2. Опалубка для плит «МОДОСТР».

Технические показатели опалубки представлены в таблице 3.5.

Таблица 3.5 – Технические показатели опалубки «МОДОСТР» по СТБ 1110-98

Наименование показателя | Значение показателя
1 | 2
Толщина монолитной плиты | max 400
Шаг варьирования толщины, мм | 50
Ширина щитов, мм | 750
Допустимое давление бетонной смеси на собранную опалубку, кПа | 80
Допустимая нагрузка на рабочую площадку, кПа | 1,5
Относительный прогиб опалубки при максимально допустимом давлении бетонной смеси | 1/400 пролёта

3.4.4 Организация и технология производства работ

Работы по монтажу опалубки начинаются с разметки основания под щиты опалубки. Для этого при помощи теодолита производится выноска геодезических осей. При помощи рулетки и краски, согласно опалубочному чертежу, наносятся риски краев опалубочных.

Далее осуществляется транспортировка элементов опалубки с помощью крана.

На заключительном этапе опалубочных работ с монтажной площадки выполняется установка подмостей для нахождения людей на верху опалубки. Затем производится выверка опалубки с помощью геодезического оборудования и вынос и закрепление высотных отметок, для фиксации высоты верхней грани бетонируемой стены при укладке бетона. Для этого производится нивелировка опалубки на поверхности с помощью мела или маркера выполняются метки и далее рекомендуется производить закрепление отметок с помощью не до конца забитых в палубу гвоздей.

Решение о распалубке конструкции принимается производителем работ на основании заключения строительной лаборатории о прочности бетона конструкции. В летнее время распалубку производят при прочности не менее 1,5 МПа, в зимнее при прочности не менее 40% от проектной. Заключение дается по результатам испытания контрольных образцов кубов, хранящихся в естественных и нормальных условиях, а также результатам испытания прочности бетона методами неразрушающего контроля, например, прибором ИПС-Мг-4, или молотком Кошкарова.

В случае прогрева бетона плиты до начала демонтажных работ в обязательном порядке производится отключение трансформатора, демонтаж питающих кабелей. Эти работы осуществляются силами электротехнического персонала, имеющего соответствующую квалификационную группу по электробезопасности. До демонтажа несущих элементов опалубки производится снятие пологов и их очистки, после чего их сворачивают и складируют на поддоны для дальнейшего транспортирования на новую захватку.

На следующем этапе производят демонтаж подмостей для нахождения людей на верху опалубки. Они складируются и транспортируются к месту следующего бетонирования плит.

На следующем этапе необходимо демонтировать анкера для крепления укрупнённых элементов и сами элементы.

Таблица 3.6 – Операционная карта на устройство монолитной колонны

Наименование операции | Средства технического обеспечения (технологическая оснастка, инструмент, инвентарь, приспособления) машины, механизмы, оборудование. | Исполнители | Описание операции
1 | 2 | 3 | 4
3.Выгрузка опалубки | Строп, кран | машинист 6 разряда бетонщик 3 разряда | Машинист 6 разряда поднимает груз краном, перемещает и устанавливает на место с помощью рабочих, которые отцепляют груз и корректируют его положение
4.Установка опалубки | Молоток, гаечный ключ, отвес | бетонщик 4 разряда 3 разряда | Бетонщики 4 и 3 разрядов производят разметку мест установки опалубки с нанесением рисок. Опалубку устанавливают сверху после установки арматурного каркаса
7.Разборка опалубки | Гаечный ключ, молоток | бетонщик 4 разряда 3 разряда | Сначала бетонщики 4 и 3 разрядов снимают крепления опалубки, затем отделяют щиты от бетонных поверхностей, снимают опорные балки, очищают щиты от бетона, смазывают

3.4.5 Потребность в материально-технических ресурсах

Ведомость потребности в материалах и изделиях представлена в таблице 3.7.

Таблица 3.7 – Ведомость потребности в материалах и изделиях

Наименование материала, изделия | Наименование и обозначение ТНПА | Единица измерения | Количество
1 | 2 | 3 | 4
Опалубка | СТБ 1110-98 | шт. | 48

Перечень машин, механизмов, оборудования, технологической оснастки, инструмента, инвентаря и приспособлений представлен в таблице 3.8.

Таблица 3.8 – Перечень машин, механизмов, оборудования, технологической оснастки, инструмента, инвентаря и приспособлений

Наименование | Тип, марка, завод-изготовитель | Назначение | Основные технические характеристики | Количество на звено (бригаду), шт.
1 | 2 | 3 | 4 | 5
Кран башенный | КБ-674А.5 | Монтаж конструкций и перемещение груза | Г/п – 7,3-12 т | 1
Строп четырёхветвевой | 4СК-6,3-4000 ГОСТ 25573 | Строповка материалов | Г/п – 6,3 т; Длина – 4 м | 2
Строп двухветвевой | 2СК-2,5-4000 ГОСТ 25573 | Строповка материалов | Г/п – 2,5 т; Длина – 4 м | 1
Строп универсальный | УСК-2,0-4000 ГОСТ 25573 | Строповка материалов | Г/п – 2,0 т; Длина – 4 м | 1
Гибкий строп | СТП-2,0-4000 | Строповка материалов и грузов | Г/п – 2,0 т; Длина – 4 м | 1
Ключ гаечный | ГОСТ 2839 | Для производства опалубочных работ | Масса – 0,1 кг | 2
Молоток | ГОСТ 2310 | Для производства | Масса – 0,4 кг | 2
Уровень УС5-2-11 | ГОСТ 9416 | Для контроля качества работ | Длина – 300 мм | 2
Рулетка РЖ-2 | ГОСТ 7502 | Для контроля качества работ | Масса – 0,35 кг | 2
Каска пластмассовая | ГОСТ 12.4.087 | Техника безопасности | Первой категории качества | 20
Штангенциркуль | ГОСТ 166 | Для контроля качества работ | – | 2
Линейка измерительная металлическая | ГОСТ 427 | Для контроля качества работ | – | 2
Теодолит | ГОСТ 10529 | Для контроля качества работ | – | 2
Отвес строительный ОТ-100 | СТБ 1111-98 | Для контроля качества работ | – | 2

3.4.6 Контроль качества и приемка работ

Карта контроля технологических процессов представлена в таблице 3.9.

Таблица 3.9 – Карта контроля технологических процессов

Объект контроля (тех. процесс) | Контролируемый параметр | | | | | | Место контроля | | Периоди-чность контроля | | Исполни-тель | | Метод контроля, обозначение ТНПА | | Тип, марка, средства измерений и испытаний | | Оформление результатов контроля
| Наименование | | Номинальное значение | | Предельное отклонение
1 | 2 | | 3 | | 4 | | 5 | | 6 | | 7 | | 8 | | 9 | | 10

Входной контроль
Приемка изделий и материалов | Наличие документа о качестве | | По ТНПА на изготовление | | Не допускается | | Приобъектный склад Каждая партия | | Сплошной | | Прораб | | Визуальный | | - | | Журнал входного контроля
| Наличие маркировки на упаковочных единицах или изделиях | | По ТНПА на изготовление | | Не допускается | | Приобъектный склад Каждая партия | | Сплошной | | Прораб | | Визуальный | | - | | Журнал входного контроля
| Целостность упаковок изделий и материалов | | Целая упаковка без повреждений | | Не допускается | | То же | | То же | | То же | | То же | | - | | То же

Операционный контроль
Устройство опалубки монолитной ж/б плиты | | Отклонение толщины защитного слоя бетона | | 30 мм | | +15; –5 мм | | Строительная площадка | Выборочный | Мастер | | Измерительный, СТБ1958 | | линейка по ГОСТ 427 | | Журнал работ
| | Перепады лицевых поверхностей палубы, в том числе стыковых | | | | 2 мм | | Строительная площадка | Сплошной | Мастер | | измерительный, СТБ1958 | | штангенциркуль по ГОСТ 166 | | Журнал работ
| | Зазор в стыковых соединениях | | | | 2 мм | | Строительная площадка | Сплошной | Мастер | | измерительный, СТБ1958 | | набор щупов № 1 и № 2. | | Журнал работ

Окончание таблицы 3.9

1 | 2 | | 3 | | | 4 | 5 | 6 | | 7 | | 8 | | 9 | | 10
| Отклонение внутреннего размера поперечного сечения блока, секции опалубки | | | | | +5 мм; –3мм | Строительная площадка | Сплошной | | Мастер | | Измерительный, СТБ1958 | | линейка по ГОСТ 427 рулетки по ГОСТ 7502 | | Журнал работ
Разборка опалубки | | Минимальная прочность бетона незагруженных монолитных конструкций при распалубке | | | 0,2–0,3 МПа | | Строительная площадка | Сплошной | Мастер | | Измерительный, СТБ1958 | | испытанием образцов-кубов на сжатие по ГОСТ 10180 | | Журнал работ
| | Минимальная прочность бетона при распалубке загруженных конструкций, в том числе от вышележащего бетона | | | | | Строительная площадка | Сплошной | Мастер | | Измерительный, СТБ1958 | | испытанием образцов-кубов на сжатие по ГОСТ 10180 | | Журнал работ

Приемочный контроль
Устройство опалубки монолитной ж/б плиты | Перепады лицевых поверхностей палубы, в том числе стыковых | | | | | 2 мм | Строительная площадка | Сплошной | | | | измерительный, СТБ1958 | | штангенциркуль по ГОСТ 166 | | Журнал работ
| Зазор в стыковых соединениях | | | | | 2 мм | Строительная площадка | Сплошной | | Мастер | | измерительный, СТБ1958 | | набор щупов № 1 и № 2. | | Журнал работ
| Отклонение внутреннего размера поперечного сечения блока, секции опалубки | | | | | +5 мм; –3мм | Строительная площадка | Сплошной | | Мастер | | Измерительный, СТБ1958 | | линейка по ГОСТ 427 рулетки по ГОСТ 7502 | | Журнал работ

3.4.7 Техника безопасности, охрана труда и окружающей среды

К строительно-монтажным работам допускаются лица не моложе 18 лет, имеющие соответствующую квалификацию, прошедшие медицинский осмотр, прошедшие первичный инструктаж на рабочем месте по технике безопасности, стажировку и допущенные к выполнению работ в качестве сварщика, плотника, арматурщика и бетонщика.

Все рабочие должны быть обучены безопасным методам производства работ, а стропальщики и сварщики должны иметь удостоверение.

Размещение на опалубке оборудования и материалов, не предусмотренных технологической картой, а также пребывание людей, непосредственно не участвующих в производстве работ на настиле опалубки, не допускается.

Разборка опалубки должна производиться (после достижения бетоном заданной прочности) с разрешения производителя работ, на основании заключения о прочности бетона выданного специалистами строительной лаборатории.

При разборке опалубки необходимо принимать меры против случайного падения элементов опалубки, обрушения поддерживающих лесов и подкосов.

При температуре воздуха на рабочих местах ниже 10 °С работающие на открытом воздухе или в неотапливаемых помещениях должны быть обеспечены помещениями для обогрева.

При работе с огнем рабочее место должно быть очищено от горючих и легковоспламеняющихся материалов, обеспечено огнетушителем, ящиком с песком и баком с водой.

После окончания работ необходимо проверить рабочее место, а также нижележащие площадки и этажи с целью ликвидации скрытых очагов возгорания, могущих привести к возникновению пожара.

Не разрешается накапливать на площадках горючие вещества (жирные масляные тряпки, опилки или стружки и отходы пластмасс), их следует хранить в закрытых металлических контейнерах в безопасном месте.

Противопожарное оборудование должно содержаться в исправном, работоспособном состоянии. Проходы к противопожарному оборудованию должны быть всегда свободны и обозначены соответствующими знаками.

Рабочие места, опасные во взрыво или пожарном отношении, должны быть укомплектованы первичными средствами пожаротушения.

3.4.8 Калькуляция и нормирование затрат труда

Калькуляция затрат труда представлена в таблице 3.10

Таблица 3.10 – Калькуляция затрат труда.

Обоснование | Наименование работ | Единица измерения | Объем | Норма времени на единицу, чел- час (маш-час) | Состав звена | | | Затраты труда на объем, чел-час (маш-час)
| | | | | Профессия | Разряд | Кол-во
1 | 2 | 3 | 4 | 5 | 6 | 7 | 8 | 9
НЗТ 1-174 табл. 12 №1 | Выгрузка опалубки | 100 т | 0,122 | 12,8 | бетонщик | 3 | 2 | 1.56
| | | | 6,4 | машинист | 6 | 1 | 0.78

Окончание таблицы 3.10

1 | 2 | 3 | 4 | 5 | 6 | 7 | 8 | | 9
НЗТ 4-422 табл. 79 №4.1 | Установка опалубки | 100 м² | 8,52 | 14 | бетонщик | 4 3 | 12 5 | | 102.24
НЗТ 4-424 табл. 79 №4.1 | Разборка опалубки | 100 м² | 8.52 | 11.4 | бетонщик | 4 3 | 15 5 | 76.68
Итого

3.4.9 Технико-экономические показатели

Технико-экономические показатели устройства монолитных колонн представлены в таблице 3.11.

Таблица 3.11 – Технико-экономические показатели устройства монолитных колонн

Наименование показателей | Единицы измерения | Значение
1 | 2 | 3
Нормативные затраты рабочего времени | чел./дн. | 12
Нормативные затраты машинного времени | маш./см. | 3
Продолжительность выполнения работ | дн. | 2
Коэффициент сменности | - | 2
Среднее количество рабочих | чел. | 20
Выработка на 1 чел. дн. | т | 66

3.5 Технологическая карта на устройство армирования монолитной ж/б плиты перекрытия

3.5.1 Область применения.

Технологическая карта разработана на устройство армирования монолитной ж/б плиты перекрытия 4-го этажа.

В состав карты входят следующие работы:

1. – подача арматуры;

2. – установка арматуры;

Работы производятся в весенне-летний период года в две смены.

3.5.2 Нормативные ссылки

При разработке данной технологической карты были использованы следующие нормативно-технические документы:

1. СН 1.03.01 «Возведение строительных конструкций зданий и сооружений» [41];

2. СТБ 1035-96 «Смеси бетонные. Технические условия» [42];

3. СТБ 1110-98 «Опалубка для возведения монолитных бетонных и железобетонных конструкций. Общие технические условия» [43];

4. СТБ 1544-2005 «Бетоны конструкционные тяжёлые. Технические условия» [44];

5. СП 5.03.01 «Бетонные и железобетонные конструкции» [45];

6. ТКП 45-2.04-153-2009 «Естественное и искусственное освещение. Строительные нормы проектирования» [46];

7. Правила по охране труда при выполнении строительных работ [27];

8. ГОСТ 5781-82 «Сталь горячекатаная для армирования железобетонных конструкций. Технические условия» [47];

9. ГОСТ 12.1.046-2014 «Система стандартов безопасности труда. Строительство. Нормы освещения строительных площадок» [48];

10. ГОСТ 12.4.059-89 «Система стандартов безопасности труда. Строительство. Ограждения предохранительные инвентарные. Общие технические условия» [49];

11. ГОСТ 12.4.089-86 «Система стандартов безопасности труда. Строительство. Пояса предохранительные. Общие технические условия» [50];

12. СТБ 1307-2012 «Смеси растворные и растворы строительные. Технические условия» [51];

13. СТБ 1704-2012 «Арматура ненапрягаемая для железобетонных конструкций. Технические условия» [12].

14. ГОСТ 3282-74 «Проволока стальная низкоуглеродистая общего назначения. Технические условия»

15. ГОСТ 7566-2018 «Металлопродукция. Правила приемки, маркировка, упаковка, транспортирование и хранение» [67].

3.5.3 Характеристика применяемых материалов и изделий

Доставленные на строительную площадку материальные элементы складируют на приобъектных складах. Материалы и изделия, подлежащие обязательной сертификации, должны иметь сертификат соответствия.

Применяемые материалы и изделия при армировании ж/б монолитной плиты:

1. Арматура;

2. Проволока для вязки арматуры по ГОСТ 3282-74

Технические показатели арматуры представлены в таблице 3.12.

Таблица 3.12 – Технические показатели арматуры по СТБ 1704-2012

Наименование показателя | Значение показателя для арматуры класса
| S240 | S500
Профиль | Гладкий | Периодический
Отношение временного сопротивления к физическому или условному пределу текучести, не менее | 1,3 | 1,08
Полное относительное удлинение при максимальной нагрузке, %, не менее | – | 5,0
Относительное удлинение, %, не менее | 25 | 14
Физический или условный предел текучести, МПа, не менее | 240 | 500

3.5.4 Организация и технология производства работ

Транспортирование и хранение арматурной стали следует осуществлять в соответствии с требованиями ГОСТ 7566-94.Поступающие на строительную площадку арматурная сталь, закладные детали и анкера при приемке должны подвергаться внешнему осмотру и замерам, а также контрольным испытаниям в случаях, оговоренных в проекте или специальных указаниях по применению отдельных видов арматурной стали, а также в случаях сомнений и правильности характеристик арматурной сетки, закладных деталей и анкеров, отсутствия необходимых данных в сертификатах или паспортах заводов-изготовителей, применения арматуры в качестве напрягаемой.

Доставка арматуры до места укладки осуществляется с помощью башенного крана КБ-674А.5

Процесс укладки арматуры состоит из рабочих операций, связанных с подачей ее до места укладки, ее укладкой и связывание арматуры между собой с помощью проволоки.

Перед началом работ необходимо:

- подготовить к работе оснастку и инструмент;

- очистить арматуру от ржавчины на строительной площадке;

- убедиться в наборе достаточной прочности перекрытия нижележащего этажа;

- закрыть все проемы в перекрытии щитами и закрепить их от смещения.

Перед каждой операцией по подъему и перемещению каркасов стропальщик должен убедится, что:

- на подаваемой арматуре нет незакрепленных стержней, инструментов;

- нет людей возле поднимаемых грузов в опасной зоне перемещения груза.

Подъем и перемещение арматурных стержней осуществляется в следующей технологической последовательности:

- по команде ст. стропальщика машинист крана подает стропа к месту складирования арматуры;

- стропальщики подходят, проводят строповку арматуры и отходят на безопасное расстояние;

- по команде ст. стропальщика машинист крана поднимает арматуру на 20-30 для проверки надежности строповки;

- убедившись в правильности и надежности строповки, ст.стропальщик дает команду крановщику на дальнейший подъем (на высоту не менее 0,5м выше встречающихся на пути предметов) и перемещение арматуры к месту установки , визуально следя за его передвижением, находясь за пределами опасной зоны;

- после перемещения арматуры к месту складирования на технологической площадке, ст.стропальщик дает команду крановщику опустить груз на место складирования арматурных стержней на технологической площадке.

- стропальщики проводят отстроповку арматуры и машинист крана убирает стропа.

Защитный слой арматуры обеспечивается с помощью упругих пластмассовых фиксаторов.

Таблица 3.13 – Операционная карта на устройство монолитной колонны

Наименование операции | Средства технического обеспечения (технологическая оснастка, инструмент, инвентарь, приспособления) машины, механизмы, оборудование. | Исполнители | Описание операции
1 | 2 | 3 | 4
1.Выгрузка арматуры | Строп, кран | машинист 6 разряда арматурщик 3 разряда | Машинист 6 разряда поднимает груз краном, перемещает и устанавливает на место с помощью рабочих, которые отцепляют груз и корректируют его положение
2.Установка арматуры | Устройство для резки и гибки арматуры, крюк для вязки арматуры | арматурщик 3 разряда | Арматурщики 3 разрядов подносят и укладывают пластмассовые фиксаторы, вяжут стержни

3.5.5 Потребность в материально-технических ресурсах

Ведомость потребности в материалах и изделиях представлена в таблице 3.14.

Таблица 3.14 – Ведомость потребности в материалах и изделиях

Наименование материала, изделия | Наименование и обозначение ТНПА | Единица измерения | Количество
1 | 2 | 3 | 4
Арматура | СТБ 1704-2012 | т | 132

Перечень машин, механизмов, оборудования, технологической оснастки, инструмента, инвентаря и приспособлений представлен в таблице 3.15.

Таблица 3.15 – Перечень машин, механизмов, оборудования, технологической оснастки, инструмента, инвентаря и приспособлений

Наименование | Тип, марка, завод-изготовитель | Назначение | Основные технические характеристики | Количество на звено (бригаду), шт.
1 | 2 | 3 | 4 | 5
Кран башенный | КБ-674А.5 | Монтаж конструкций и перемещение груза | Г/п – 7,3-12,0 т | 1

Окончание таблицы 3.15

1 | 2 | 3 | 4 | 5
Строп четырёхветвевой | 4СК-6,3-4000 ГОСТ 25573 | Строповка материалов | Г/п – 6,3 т; Длина – 4 м | 2
Строп двухветвевой | 2СК-2,5-4000 ГОСТ 25573 | Строповка материалов | Г/п – 2,5 т; Длина – 4 м | 1
Строп универсальный | УСК-2,0-4000 ГОСТ 25573 | Строповка материалов | Г/п – 2,0 т; Длина – 4 м | 1
Гибкий строп | СТП-2,0-4000 | Строповка материалов и грузов | Г/п – 2,0 т; Длина – 4 м | 1
Ключ гаечный | ГОСТ 2839 | Для производства опалубочных работ | Масса – 0,1 кг | 2
Молоток | ГОСТ 2310 | Для производства | Масса – 0,4 кг | 2
Уровень УС5-2-11 | ГОСТ 9416 | Для контроля качества работ | Длина – 300 мм | 2
Рулетка РЖ-2 | ГОСТ 7502 | Для контроля качества работ | Масса – 0,35 кг | 2
Каска пластмассовая | ГОСТ 12.4.087 | Техника безопасности | Первой категории качества | 6
Крюк для вязки арматуры | ТУ 67-399-82 | Для производства арматурных работ | – | 1
Устройство для резки и гибки арматуры | АРГ-1 | Для резки и гибки арматуры | Масса – 8 кг | 1
Штангенциркуль | ГОСТ 166 | Для контроля качества работ | – | 2
Линейка измерительная металлическая | ГОСТ 427 | Для контроля качества работ | – | 2

3.5.6 Контроль качества и приемка работ

Карта контроля технологических процессов представлена в таблице 3.16.

Таблица 3.16 – Карта контроля технологических процессов

Объект контроля (тех. процесс) | Контролируемый параметр | | | Место контроля | Периоди-чность контроля | Исполни-тель | Метод контроля, обозначение ТНПА | Тип, марка, средства измерений и испытаний | Оформление результатов контроля
| Наименование | Номинальное значение | Предельное отклонение
1 | 2 | 3 | 4 | 5 | 6 | 7 | 8 | 9 | 10

Входной контроль
Приемка изделий и материалов | Наличие документа о качестве | По ТНПА на изготовление | Не допускается | Приобъектный склад Каждая партия | Сплошной | Прораб | Визуальный | - | Журнал входного контроля

Окончание таблицы 3.16

1 | 2 | 3 | | | 4 | | 5 | | | | | 6 | | | 7 | | | 8 | | | 9 | | | 10
Приемка изделий и материалов | Наличие маркировки на упаковочных единицах или изделиях | По ТНПА на изготовление | | | Не допускается | | Приобъектный склад Каждая партия | | | | | Сплошной | | | Прораб | | | Визуальный | | | - | | | Журнал входного контроля
| Целостность упаковок изделий и материалов | Целая упаковка без повреждений | | | Не допускается | | То же | | | | | То же | | | То же | | | То же | | | - | | | То же

Операционный контроль
Установка арматурных стержней | Отклонение расстояний между отдельно установленными стержнями | | По расчету | | | ±10 мм | | Строительная площадка | | | Выборочный | | | Мастер | | | Измерительный, СТБ1958 | | | линейка по ГОСТ 427 рулетки по ГОСТ 7502 | | | Журнал работ

Приемочный контроль
Соответствие укладки арматурных стержней проекту | Предел отклонения арматурных стержней от проекта | | | | | ±10 мм | | | Строительная площадка | Сплошной | | | Мастер | | | Измерительный, СТБ 1958 | | | линейка по ГОСТ 427 рулетки по ГОСТ 7502 | | | Журнал работ

3.5.7 Техника безопасности, охрана труда и окружающей среды

К строительно-монтажным работам допускаются лица не моложе 18 лет, имеющие соответствующую квалификацию, прошедшие медицинский осмотр, прошедшие первичный инструктаж на рабочем месте по технике безопасности, стажировку и допущенные к выполнению работ в качестве сварщика, плотника, арматурщика и бетонщика.

Все рабочие должны быть обучены безопасным методам производства работ, а стропальщики должны иметь удостоверение.

Размещение на опалубке оборудования и материалов, не предусмотренных технологической картой, а также пребывание людей, непосредственно не участвующих в производстве работ на настиле опалубки, не допускается.

Заготовка и обработка арматуры должны выполняться в специально предназначенных для этого и соответственно оборудованных местах.

При выполнении работ по заготовке арматуры необходимо:

– ограждать места, предназначенные для разматывания бухт (мотков) и выправления арматуры;

– при резке станками стержней арматуры на отрезки длиной менее 0,3 м применять приспособления, предупреждающие их разлет;

– ограждать рабочее место при обработке стержней арматуры, выступающих за габариты верстака, а у двусторонних верстаков, кроме этого, разделять верстак посередине продольной металлической предохранительной сеткой высотой не менее 1 м;

– складывать заготовленную арматуру в специально отведенные для этого места;

– закрывать щитами торцевые части стержней арматуры в местах общих проходов, имеющих ширину менее 1 м.

Элементы каркасов арматуры необходимо пакетировать с учетом условий их подъема, складирования и транспортирования к месту монтажа.

При температуре воздуха на рабочих местах ниже 10 °С работающие на открытом воздухе или в неотапливаемых помещениях должны быть обеспечены помещениями для обогрева.

В зоне прогрева необходимо применять изолированные гибкие кабели или провода в защитном шланге. Не допускается прокладывать провода непосредственно по грунту или по слою опилок, а также провода с нарушениями.

Зона прогрева бетона должна находиться под круглосуточным наблюдением электромонтеров, выполняющих монтаж электросети.

После каждого перемещения электрооборудования, применяемого при прогреве бетона, на новое место следует визуально проверять состояние изоляции проводов, средств защиты ограждений и заземления.

Устройство и техническое обслуживание временных и постоянных электрических сетей на производственной территории следует осуществлять силами электротехнического персонала, имеющего соответствующую квалификационную группу по электробезопасности.

Токоведущие части электроустановок должны быть изолированы, ограждены или размещены в местах, недоступных для случайного прикосновения к ним.

Не допускается использовать не принятые в эксплуатацию в установленном порядке электрические сети, распределительные устройства, щиты, панели и их отдельные ответвления и присоединять их в качестве временных электрических сетей и установок, а также производить электромонтажные работы на смонтированной и переданной под наладку электроустановке без разрешения наладочной организации.

При работе с огнем рабочее место должно быть очищено от горючих и легковоспламеняющихся материалов, обеспечено огнетушителем, ящиком с песком и баком с водой.

После окончания работ необходимо проверить рабочее место, а также нижележащие площадки и этажи с целью ликвидации скрытых очагов возгорания, могущих привести к возникновению пожара.

Не разрешается накапливать на площадках горючие вещества (жирные масляные тряпки, опилки или стружки и отходы пластмасс), их следует хранить в закрытых металлических контейнерах в безопасном месте.

Противопожарное оборудование должно содержаться в исправном, работоспособном состоянии. Проходы к противопожарному оборудованию должны быть всегда свободны и обозначены соответствующими знаками.

Рабочие места, опасные во взрыво- или пожарном отношении, должны быть укомплектованы первичными средствами пожаротушения.

3.5.8 Калькуляция и нормирование затрат труда

Калькуляция затрат труда представлена в таблице 3.17

Таблица 3.17 – Калькуляция затрат труда.

Обоснование | Наименование работ | Единица измерения | Объем | Норма времени на единицу, чел- час (маш-час) | Состав звена | | | Затраты труда на объем, чел-час (маш-час)
| | | | | Профессия | Разряд | Кол-во
1 | 2 | 3 | 4 | 5 | 6 | 7 | 8 | 9
НЗТ 1-162 табл. 12 №1 | Выгрузка арматуры | 100 т | 1,32 | 48,5 | арматурщик | 3 | 2 | 64,08
| | | | 24,8 | машинист | 6 | 1 | 32,74
НЗТ №4.1 4-514 табл. 110 | Установка арматуры | 100 т | 1,32 | 411,1 | арматуршик | 3 | 17 | 542,65
Итого

3.5.9 Технико-экономические показатели

Технико-экономические показатели устройства монолитных колонн представлены в таблице 3.18.

Таблица 3.18 – Технико-экономические показатели устройства монолитных колонн

Наименование показателей | Единицы измерения | Значение
1 | 2 | 3
Нормативные затраты рабочего времени | чел./дн. | 75,5
Нормативные затраты машинного времени | маш./см. | 4

Окончание таблицы 3.18

1 | 2 | 3
Продолжительность выполнения работ | дн. | 2
Коэффициент сменности | - | 2
Среднее количество рабочих | чел. | 20
Выработка на 1 чел. дн. | т | 66

3.6 Технологическая карта на бетонирование монолитной плиты покрытия

3.6.1 Область применения

Технологическая карта разработана на бетонирование монолитной ж/б плиты покрытия 4-го этажа.

В состав карты входят следующие работы:

1. – подача бетона;

2. – бетонирование и уход за бетоном;

Работы производятся в весенне-летний период года в две смены.

3.6.2 Нормативные ссылки

При разработке данной технологической карты были использованы следующие нормативно-технические документы:

1. СН 1.03.01 «Возведение строительных конструкций зданий и сооружений» [41];

2. СТБ 1035-96 «Смеси бетонные. Технические условия» [42];

3. СТБ 1110-98 «Опалубка для возведения монолитных бетонных и железобетонных конструкций. Общие технические условия» [43];

4. СТБ 1544-2005 «Бетоны конструкционные тяжёлые. Технические условия» [44];

5. СП 5.03.01 «Бетонные и железобетонные конструкции» [45];

6. ТКП 45-2.04-153-2009 «Естественное и искусственное освещение. Строительные нормы проектирования» [46];

7. Правила по охране труда при выполнении строительных работ [27];

8. ГОСТ 5781-82 «Сталь горячекатаная для армирования железобетонных конструкций. Технические условия» [47];

9. ГОСТ 12.1.046-2014 «Система стандартов безопасности труда. Строительство. Нормы освещения строительных площадок» [48];

10. ГОСТ 12.4.059-89 «Система стандартов безопасности труда. Строительство. Ограждения предохранительные инвентарные. Общие технические условия» [49];

11. ГОСТ 12.4.089-86 «Система стандартов безопасности труда. Строительство. Пояса предохранительные. Общие технические условия» [50];

12. СТБ 1307-2012 «Смеси растворные и растворы строительные. Технические условия» [51];

13. СТБ 1704-2012 «Арматура ненапрягаемая для железобетонных конструкций. Технические условия» [12].

3.6.3 Характеристика применяемых материалов и изделий

Доставленные на строительную площадку материальные элементы складируют на приобъектных складах. Материалы и изделия, подлежащие обязательной сертификации, должны иметь сертификат соответствия.

Применяемые материалы и изделия при устройстве монолитной плиты:

1. Бетонная смесь;

Бетонная смесь доставляется на объект автобетоносмесителем. Она выгружается в бункеры и подаётся на рабочее место краном.

Технические показатели бетонной смеси представлены в таблице 3.19.

Таблица 3.19 – Технические показатели бетонной смеси

Наименование показателя | Значение показателя
1 | 2
Класс бетона | С20/25
Расчётное сопротивление осевому сжатию для предельных состояний первой группы, МПА | 17
Марка по морозостойкости (число циклов) | F150
Марка по водонепроницаемости (давление в атмосферах) | W4
Марка по средней плотности (объёмная масса бетона в кг/м³) | D2420
Марка по удобоукладываемости | П3

3.6.4 Организация и технология производства работ

Укладка бетонной смеси в перекрытия выполняется из бункера, который подается башенным краном и ведется по захваткам в определенном порядке. Захватки определяются из условия сменной эксплуатационной производительности крана.

Процесс укладки бетонной смеси состоит из рабочих операций, связанных с подачей ее в опалубку и уплотнения. До начала укладки бетонной смеси в опалубку необходимо проверить:

- элементы крепления опалубки;

- качество очистки опалубки от мусора и грязи;

- качество очистки арматуры от налета ржавчины;

- тщательность очистки бетонной поверхности стен от цементной пленки;

- смазку внутренних поверхностей опалубки;

- выноску проектной отместки верха бетонирования плиты перекрытия на арматурный каркас.

При укладке бетонной смеси системой «кран – бадья» прием бетонной смеси осуществляется в вертикальный неповоротный бункер непосредственно из автобетоносмесителя.

Бетонная смесь в бункере подается башенным краном к месту укладки, где осуществляется ее укладка в опалубку плиты и послойное уплотнение с помощью глубинных вибраторов. Укладку последующего слоя производить на несхватившийся бетон. Далее осуществляется выравнивание бетонной смеси по отметкам-маякам.

В начальный период твердения бетон необходимо защищать от попадания атмосферных осадков или потерь влаги (укрывать влагоёмким материалом), в последующем поддерживать температурно-влажностный режим с созданием условий, обеспечивающих нарастание его прочности (увлажнение или полив). Потребность в поливе определяется визуально, при осмотре состояния бетона.

Уход за свежеуложенным бетоном следует начинать сразу после окончания укладки бетонной смеси и осуществлять до достижения, как правило, 70 % проектной прочности, а при соответствующем обосновании – 50%.

При достижении бетоном прочности 0,5 МПа последующий уход за ним должен заключаться в обеспечении влажного состояния поверхности путем устройства влагоемкого покрытия и его увлажнения, выдерживания открытых поверхностей бетона под слоем воды, непрерывного распыления влаги над поверхностью конструкций. При этом периодический полив водой открытых поверхностей бетонных и железобетонных конструкций не допускается.

В случае прогрева бетона плиты до начала демонтажных работ в обязательном порядке производится отключение трансформатора, демонтаж питающих кабелей. Эти работы осуществляются силами электротехнического персонала, имеющего соответствующую квалификационную группу по электробезопасности. До демонтажа несущих элементов опалубки производится снятие пологов и их очистки, после чего их сворачивают и складируют на поддоны для дальнейшего транспортирования на новую захватку.

Таблица 3.20 – Операционная карта на устройство монолитной колонны

Наименование операции | Средства технического обеспечения (технологическая оснастка, инструмент, инвентарь, приспособления) машины, механизмы, оборудование. | Исполнители | Описание операции
1 | 2 | 3 | 4
1.Подача бетона | Строп, кран, бункер | машинист 6 разряда бетонщик 3 разряда | Машинист 6 разряда поднимает груз краном, перемещает и устанавливает на место с помощью рабочих
2.Бетонирование и уход за бетоном | Гладилка, вибратор, термометр, ведро, конус | бетонщик 4 разряда 3 разряда | Бетонщики 3 и 4 разрядов принимают бетонную смесь, укладывают, разравнивают с частичной её перекидкой, уплотняют вибраторами, а затем заглаживают

3.6.5 Потребность в материально-технических ресурсах

Ведомость потребности в материалах и изделиях представлена в таблице 3.21

Таблица 3.21 – Ведомость потребности в материалах и изделиях

Наименование материала, изделия | Наименование и обозначение ТНПА | Единица измерения | Количество
1 | 2 | 3 | 4
Бетон | СТБ 1544-2005 | м³ | 195,96

Перечень машин, механизмов, оборудования, технологической оснастки, инструмента, инвентаря и приспособлений представлен в таблице 3.22.

Таблица 3.22 – Перечень машин, механизмов, оборудования, технологической оснастки, инструмента, инвентаря и приспособлений

Наименование | Тип, марка, завод-изготовитель | Назначение | Основные технические характеристики | Количество на звено (бригаду), шт.
1 | 2 | 3 | 4 | 5
Кран башенный | КБ-674А.5 | Монтаж конструкций и перемещение груза | Г/п – 7,3-12,0 т | 1
Строп четырёхветвевой | 4СК-6,3-4000 ГОСТ 25573 | Строповка материалов | Г/п – 6,3 т; Длина – 4 м | 2
Уровень УС5-2-11 | ГОСТ 9416 | Для контроля качества работ | Длина – 300 мм | 2
Рулетка РЖ-2 | ГОСТ 7502 | Для контроля качества работ | Масса – 0,35 кг | 2
Ведро | ГОСТ 20558 | Для производства бетонных работ | Объём – 10 л | 2
Каска пластмассовая | ГОСТ 12.4.087 | Техника безопасности | Первой категории качества | 20
Вибратор ИВ-116 | ГОСТ 12.2.013 | Для уплотнения бетона | Мощность – 1,6 кВт | 2
Термометр | ГОСТ 2823 | Для ухода за бетоном | – | 2
Бадья БН-2,0 | ГОСТ 21807 | Транспортировка и разгрузка бетонной смеси | Объём – 2,0 м3; Масса – 340 кг | 3
Гладилка | ГОСТ 10403 | Разравнивание бетонной смеси | Масса – 0,55 кг | 2
Конус КА | ГОСТ 10181.1 | Для определения подвижности бетонной смеси | – | 2
Штангенциркуль | ГОСТ 166 | Для контроля качества работ | – | 2
Линейка измерительная металлическая | ГОСТ 427 | Для контроля качества работ | – | 2

Окончание таблицы 3.22

1 | 2 | 3 | 4 | 5
Теодолит | ГОСТ 10529 | Для контроля качества работ | – | 2
Отвес строительный ОТ-100 | СТБ 1111-98 | Для контроля качества работ | – | 2

3.6.6 Контроль качества и приемка работ

Карта контроля технологических процессов представлена в таблице 3.23.

Таблица 3.23 – Карта контроля технологических процессов

Объект контроля (тех. процесс) | Контролируемый параметр | | | Место контроля | | Периоди-чность контроля | Исполни-тель | | Метод контроля, обозначение ТНПА | | Тип, марка, средства измерений и испытаний | | Оформление результатов контроля
| Наименование | Номинальное значение | Предельное отклонение
1 | 2 | 3 | 4 | 5 | | 6 | 7 | | 8 | | 9 | | 10

Входной контроль
Приемка изделий и материалов | Наличие документа о качестве | По ТНПА на изготовление | Не допускается | Приобъектный склад Каждая партия | | Сплошной | Прораб | | Визуальный | | - | | Журнал входного контроля
Приемка изделий и материалов | Наличие маркировки на упаковочных единицах или изделиях | По ТНПА на изготовление | Не допускается | Приобъектный склад Каждая партия | | Сплошной | Прораб | | Визуальный | | - | | Журнал входного контроля

Операционный контроль
Подача бетонной смеси | Прочность поверхностей бетонных оснований при очистке, не менее | | 0,3 МПа | | | | | | | | | испытанием образцов-кубов на сжатие по ГОСТ 10180 | | Журнал работ
| Высота свободного сбрасывания бетонной смеси в опалубку конструкций, не более | | 5 м | | Строительная площадка | Выборочный | | Мастер | | Измерительный, визуальный СТБ1958 | | линейка измерительная металлическая по ГОСТ 427 | | Журнал работ

Окончание таблицы 3.23

1 | 2 | | 3 | 4 | | 5 | | 6 | | 7 | | 8 | | 9 | | 10
Укладка бетонной смеси | Толщина укладываемых слоев бетонной смеси при уплотнении глубинными вибраторами | | | Не более 1,25 длины раб. части вибратора | | Строительная площадка | | Сплошной | | Мастер | | Измерительный, визуальный СТБ1958 | | линейка измерительная металлическая по ГОСТ 427 | | Журнал работ

Приемочный контроль
Соответствие законченных бетонных конструкций | | Отклонение линий пересечения плоскостей от вертикали или проектного наклона на всю высоту конструкций | | 15 мм | Строительная площадка | | Сплошной | | Мастер | | Измерительный, СТБ 1958 | | отвес строительный ОТ100 по СТБ 1111 линейка по ГОСТ 427 рулетки по ГОСТ 7502 | | Журнал работ
| | Отклонение размера поперечного сечения элементов | Плита 200 мм | +10 мм; –3 мм | Строительная площадка | | Выборочный | | Мастер | | Измерительный, СТБ1958 | | линейка измерительная по ГОСТ 427 рулетки измерительные по ГОСТ 7502 | | Журнал работ
Соответствие законченных ж/б конструкций | | Перепад в стыке двух смежных поверхностей | | 5 мм | Строительная площадка | | Выборочный | | Мастер | | Измерительный, СТБ1958 | | линейка по ГОСТ 427 уровень УС5-2-11 по ГОСТ 9416 клин (0,5–16) мм | | Журнал работ

3.6.7 Техника безопасности, охрана труда и окружающей среды

К строительно-монтажным работам допускаются лица не моложе 18 лет, имеющие соответствующую квалификацию, прошедшие медицинский осмотр, прошедшие первичный инструктаж на рабочем месте по технике безопасности, стажировку и допущенные к выполнению работ в качестве сварщика, плотника, арматурщика и бетонщика.

Все рабочие должны быть обучены безопасным методам производства работ, а стропальщики и сварщики должны иметь удостоверение.

Размещение на опалубке оборудования и материалов, не предусмотренных технологической картой, а также пребывание людей, непосредственно не участвующих в производстве работ на настиле опалубки, не допускается.

Ежедневно перед началом укладки бетона в опалубку необходимо проверять состояние тары, опалубки и средств подмащивания. Обнаруженные неисправности следует незамедлительно устранять.

При укладке бетона из бадей или бункера расстояние между нижней кромкой бадьи или бункера и ранее уложенным бетоном или поверхностью, на которую укладывается бетон, должно быть не более 1 м.

Бункеры (бадьи) для бетонной смеси должны соответствовать требованиям государственных стандартов. Перемещение загруженного или порожнего бункера разрешается только при закрытом затворе.

При применении бетонных смесей с химическими добавками следует использовать защитные перчатки и очки.

При уплотнении бетонной смеси электровибраторами перемещать вибратор за токоведущие шланга не допускается, а при перерывах в работе и при переходе с одного места на другое электровибраторы необходимо выключать.

Разборка опалубки должна производиться (после достижения бетоном заданной прочности) с разрешения производителя работ, на основании заключения о прочности бетона выданного специалистами строительной лаборатории.

При разборке опалубки необходимо принимать меры против случайного падения элементов опалубки, обрушения поддерживающих лесов и подкосов.

При температуре воздуха на рабочих местах ниже 10 °С работающие на открытом воздухе или в неотапливаемых помещениях должны быть обеспечены помещениями для обогрева.

В зоне прогрева необходимо применять изолированные гибкие кабели или провода в защитном шланге. Не допускается прокладывать провода непосредственно по грунту или по слою опилок, а также провода с нарушениями.

Зона прогрева бетона должна находиться под круглосуточным наблюдением электромонтеров, выполняющих монтаж электросети.

После каждого перемещения электрооборудования, применяемого при прогреве бетона, на новое место следует визуально проверять состояние изоляции проводов, средств защиты ограждений и заземления.

Устройство и техническое обслуживание временных и постоянных электрических сетей на производственной территории следует осуществлять силами электротехнического персонала, имеющего соответствующую квалификационную группу по электробезопасности.

Токоведущие части электроустановок должны быть изолированы, ограждены или размещены в местах, недоступных для случайного прикосновения к ним.

Не допускается использовать не принятые в эксплуатацию в установленном порядке электрические сети, распределительные устройства, щиты, панели и их отдельные ответвления и присоединять их в качестве временных электрических сетей и установок, а также производить электромонтажные работы на смонтированной и переданной под наладку электроустановке без разрешения наладочной организации.

При работе с огнем рабочее место должно быть очищено от горючих и легковоспламеняющихся материалов, обеспечено огнетушителем, ящиком с песком и баком с водой.

После окончания работ необходимо проверить рабочее место, а также нижележащие площадки и этажи с целью ликвидации скрытых очагов возгорания, могущих привести к возникновению пожара.

Не разрешается накапливать на площадках горючие вещества (жирные масляные тряпки, опилки или стружки и отходы пластмасс), их следует хранить в закрытых металлических контейнерах в безопасном месте.

Противопожарное оборудование должно содержаться в исправном, работоспособном состоянии. Проходы к противопожарному оборудованию должны быть всегда свободны и обозначены соответствующими знаками.

Рабочие места, опасные во взрыво- или пожарном отношении, должны быть укомплектованы первичными средствами пожаротушения.

3.6.8 Калькуляция и нормирование затрат труда

Калькуляция затрат труда представлена в таблице 3.24

Таблица 3.24 – Калькуляция затрат труда.

Обоснование | Наименование работ | Единица измерения | Объем | Норма времени на единицу, чел- час (маш-час) | Состав звена | | | | Затраты труда на объем, чел-час (маш-час)
| | | | | Профессия | Разряд | Кол-во
1 | 2 | 3 | 4 | 5 | 6 | 7 | 8 | | 9
НЗТ 1-159 табл. 12 №1 | Подача бетона | 100 м³ | 2.66 | 1 | бетонщик | 3 | 3 | | 2.66
| | | | 12,1 | машинист | 6 | 1 | | 32,2
НЗТ 4-662 табл. 125 №4.1 | Бетонирование и уход за бетоном | 10 м³ | 26.6 | 17.6 | бетонщик | 4 3 | | 12 4 | 468.16
Итого

3.6.9 Технико-экономические показатели

Технико-экономические показатели устройства монолитных колонн представлены в таблице 3.25.

Таблица 3.25 – Технико-экономические показатели устройства монолитных колонн

Наименование показателей | Единицы измерения | Значение
1 | 2 | 3
Нормативные затраты рабочего времени | чел./дн. | 58,85
Нормативные затраты машинного времени | маш./см. | 4,03
Продолжительность выполнения работ | дн. | 2
Коэффициент сменности | - | 2
Среднее количество рабочих | чел. | 20
Выработка на 1 чел. дн. | 100м² | 4,26

4 Организационно-строительный раздел

4.1 Определение нормативной продолжительности строительства

Для определения срока строительства гостиницы был использован ТКП 45-1.03-211-2010[38]

Таблица 4.1 – Нормы продолжительности строительства объектов металлических конструкций

Объект | Строительный объем | Норма продолжительности строительства, мес.
| | общая | в том числе
| | | подготовительный период | монтаж оборудования
1 | 2 | 3 | 4 | 5
Гостиница | 35 | 20 | 3 | -
| 40 | 22 | 3 | -
| 55 | 25 | 3 | -

Нормативная продолжительность строительства определяется методом экстраполяции:

(35000-31395)/35000∙100=10,3%

10,3∙0,3=3,09%

(20∙(100-3,09))/100=19,4 мес.

Принимаем нормативный срок строительства 19,5 месяцев

Начало производства работ октябрь 2021 г.

4.2 Выбор основных методов производства работ и решений по организации поточного возведения объекта

Работы по возведению объекта начинаются с освоения площадки, уборки кустарников, корчевания пней, пересадки деревьев, разбивки геодезических осей.

Срезка растительного слоя и планировка площадки осуществляется бульдозером ДЗ-28. Разработка котлованов производится экскаватором ЭО-4321Б.

Доработка грунта до проектной отметки осуществляется вручную. Обратная засыпка грунта в пазухи котлована производится бульдозером ДЗ-28 слоями, с обязательным послойным трамбованием слоев.

Работы по возведению фундаментов и возведению монолитного каркаса

здания осуществляются с помощью башенного крана КБ-503А.3.

Работы по устройству нулевого цикла и возведению каркаса здания ведутся в две смены.

Работы по устройству кровли и отделочные работы ведут в одну смену.

Все работы специального цикла выполняются в три этапа:

Ввод инженерных коммуникаций (I этап): устройство вводов в здание выполняются до обратной засыпки; II этап: черновые работы выполняются до начала штукатурных работ; III этап: навеска санитарно-технических приборов производится после отделочных работ.

Заключительным этапом являются работы по благоустройству территории, подготовке объекта к сдаче и непосредственно сдача объекта. Благоустройство территории заключается в разбивке газонов, посадке деревьев и кустарников, устройстве пешеходных дорожек, устройство малых форм

Таблица 4.2 – Ведомость объемов строительных, монтажных и специальных работ

№ | Наименование работ | Ед. изм. | Объем работ
1 | 3 | 4 | 6
1 | Разработка грунта бульдозером мощностью 79 (108) кВт (л.с.) при перемещении грунта до 10 м, грунт 1 группы | 1000 м3 | 0,24
2 | Разработка грунта бульдозерами мощностью 79 (108) кВт (л.с.) добавлять на каждые последующие 10 м, грунт 1 группы | 1000 м3 | 0,5808
3 | Планировка площадей бульдозерами мощностью 79 (108) кВт (л.с.) | 1000 м3 | 0,820
4 | Разработка грунта в отвал экскаватором "ОБРАТНАЯ ЛОПАТА" с ковшом вместимостью 0,5 м3, грунт 1 группы | 1000 м3 | 0,4983
5 | Разработка грунта с погрузкой на автомобили-самосвалы экскаваторами с ковшом вместимостью 0,5 м3, грунт 1 группы | 1000 м3 | 2,434
6 | Разработка грунта вручную в траншеях шириной более 2 м и котлованах площадью сечения до 5 м2 с креплениями, глубиной траншей и котлованов до 3 м, грунт 1 группы | 100 м3 | 0,17
7 | Погружение дизель-молотом копровой установки на базе трактора железобетонных свай длиной до 10 м, в грунты 1 группы | м3 | 243,2
8 | Установка арматуры | Т | 267,4
9 | Устройство фундаментных плит бетонных плоских из бетона класса В7,5 | 100 м3 | 2,7
10 | Устройство монолитных железобетонных наружных стен высотой до 4 м, толщиной 400 мм в опалубке импортного производства типа "модостр" | 100м3 | 1,75
11 | Гидроизоляция стен, фундаментов горизонтальная оклеечная в 2 слоя из рубероида | 100 м2 | 4,03
12 | Установка арматуры | Т | 16,6
13 | Устройство колонн в деревянной опалубке со стальными сердечниками (жесткой арматурой) из бетона класса с12/15, периметром до 4 м, при отношении объема сердечника или жесткой арматуры к об ему колонн до 25 процентов | 100м3 | 0,14
14 | Установка арматуры | Т | 159,64
15 | Устройство перекрытий безбалочных из бетона класса С12/15, толщиной более 200 мм на высоте от опорной площади до 6 м | 100 м3 | 1.369
16 | Засыпка траншей и котлованов бульдозерами мощностью 79 (108) кВт (л.с.) при перемещении грунта до 5 м, грунт 1 группы | 1000 м3 | 0,4983

Продолжение таблицы 4.2

1 | 2 | 3 | 4
17 | Засыпка вручную траншей, пазух котлованов и ям, грунт 1 группы | 100 м3 | 0,171
18 | Уплотнение грунта пневматическими трамбовками, грунт 1 группы | 100 м3 | 5,3
19 | Установка арматуры | Т | 165,1
20 | Устройство колонн в деревянной опалубке со стальными сердечниками (жесткой арматурой) из бетона класса с12/15, периметром до 4 м, при отношении об ема сердечника или жесткой арматуры к об ему колонн до 25 процентов | 100м3 | 1,72
21 | Установка арматуры | Т | 1325,6
22 | Устройство перекрытий безбалочных из бетона класса С12/15, толщиной более 200 мм на высоте от опорной площади до 6 м | 100 м3 | 13,70
23 | Установка арматуры | Т | 40,34
24 | Устройство монолитных железобетонных лестничных площадок и маршей в опалубке импортного производства типа "модостр" | 100м3 | 0,36
25 | Возведение трехслойных стен из газосиликатных блоков на клею толщиной 300 мм | м3 | 998,13
26 | Изоляция поверхностей плоских изделиями минераловатными с гофрированной структурой | 10м2 | 296,92
27 | Декоративная штукатурка типа "байрамикс" наружных поверхностей стен мелкой фракции 0,5 мм с люлек | 100м2 | 29,69
28 | Кладка перегородок неармированных толщиной в 1 2 кирпича при высоте этажа до 4 м из кирпича силикатного утолщенного | 100м2 | 28,033
29 | Устройство перемычек железобетонных из бетона класса с12/15 | 100м3 | 0,75
30 | Устройство монолитного железобетонного лифтового блока в опалубке импортного производства типа "модостр" | 100м3 | 0,716
31 | Устройство выравнивающих стяжек под кровлю без армирования толщиной 30 мм | 100м² | 8,55
32 | Утепление покрытий плитами из минеральной ваты или перлита на битумной мастике | 100м² | 8,55
33 | Огрунтовка оснований кровли механизированным способом | 100 м² | 8,55
34 | Устройство пароизоляции оклеечной в один слой | 100м³ | 8,55
35 | Устройство двухслойных кровель из наплавляемых рулонных материалов при механическом закреплении нижнего слоя водоизоляционного ковра | 100 м² | 8,55
36 | Установка воронок водосточных | Шт | 10
37 | Устройство примыканий кровли из наплавляемых рулонных материалов к воронке внутреннего водостока | 100шт | 0,1
38 | Устройство желобов настенных | 100мжел. | 8,55
39 | Устройство примыканий к парапетам и другим выступающим частям здания при устройстве покрытия кровли из рулонных материалов | 100м | 0,764

Продолжение таблицы 4.2

1 | 2 | 3 | 4
40 | Облицовка парапета фасадными панелями | 100м пара | 0,764
41 | Установка окон из ПВХ со стеклопакетами в проемы кирпичных стен с креплением поворотными анкерами при площади изделия до 2 м2 | 100 м2 | 0,0965
42 | Установка окон из ПВХ со стеклопакетами в проемы кирпичных стен с креплением поворотными анкерами при площади изделия до 3 м2 | 100 м2 | 1,94
43 | Установка окон из пвх со стеклопакетами в проемы кирпичных стен с креплением поворотными анкерами при площади изделия свыше 3 м2 | 100 м2 | 4,9608
44 | Установка блоков окно-балконная дверь из ПВХ со стеклопакетами в проемы кирпичных стен при площади изделия свыше 3 м2 | 100 м2 | 11,09
45 | Соединение окна и балконной рамы при помощи подставочного профиля | 100 м | 0,75
46 | Установка подоконных досок из ДСП | 100 м | 0,75
47 | Герметизация мест примыкания оконных и балконных блоков из пвх к стенам толщиной зазора 0,03 м | 100 м2 | 2,33
48 | Установка блоков в наружных и внутренних дверных проемах в каменных стенах, площадь проема до 3 м2 | 100 м2 | 0,06
49 | Установка блоков в наружных и внутренних дверных проемах в перегородках и деревянных нерубленых стенах, площадь проема до 3 м2 | 100 м2 | 1,66
50 | Установка блоков для люков в перекрытиях | 100 м2 | 0,0162
51 | Отделка поверхностей стен и перегородок из блоков и плит под окраску или оклейку обоями | 100М2 | 122,51
52 | Улучшенная окраска потолков акриловыми составами по сборным конструкциям, подготовленным под окраску | 100 м2 | 86.59
53 | Декоративная штукатурка типа "байрамикс" внутренних поверхностей стен средней фракции 1,0 мм | 100м2 пов | 32,40
54 | Штукатурка плоских поверхностей оконных и дверных откосов по камню | 100 м2 | 2,34
55 | Облицовка белыми керамическими глазурованными плитками поверхностей стен в жилых зданиях по кирпичу | 100 м2 | 26,95
56 | Высококачественная окраска стен внутри помещений акриловыми составами с полной подготовкой поверхности по штукатурке | 100 м2 | 2,34
57 | Оклейка стен и перегородок обоями со сплошным шпатлеванием простыми и средней плотности с подбором рисунка | 100 м2 | 122,51
58 | Утепление покрытий из плит пенополистирольных на битумной мастике в один слой толщиной 10 см | 100 м2 | 1,448
59 | Утепление покрытий из плит пенополистирольных на битумной мастике на каждый последующий слой добавлять к норме 12-13-1 | 100 м2 | 1,8
60 | Устройство пароизоляции прокладочной в один слой | 100 м2 | 1,448

Окончание таблицы 4.2

1 | 2 | 3 | 4
61 | Устройство гидроизоляции обмазочной в один слой толщиной 2 мм | 100 м2 | 1,448
62 | Устройство гидроизоляции обмазочной на каждый последующий слой толщиной 1 мм добавлять по норме 5 | 100 м2 | 1,448
63 | Устройство стяжек цементных толщиной 20 мм | 100 м2 | 1,448
64 | Устройство стяжек бетонных на каждые 5 мм изменения толщины стяжки | 100 м2 | 5,792
65 | Устройство покрытий пола плиткой "грес" на клею по цементной стяжке | 100 м2 | 1,448
66 | Утепление покрытий плитами из легких (ячеистых) бетонов, фибролита или пеностекла насухо | 100 м2 | 5,314
67 | Устройство стяжек бетонных толщиной 20 мм | 100 м2 | 5,314
68 | Устройство гидроизоляции обмазочной в один слой толщиной 2 мм | 100 м2 | 5,314
69 | Устройство гидроизоляции обмазочной на каждый последующий слой толщиной 1 мм добавлять по норме 5 | 100 м2 | 5,314
70 | Устройство стяжек легкобетонных толщиной 20 мм | 100 м2 | 5,314
71 | Устройство стяжек легкобетонных на каждые 5 мм изменения толщины стяжки | 100 м2 | 15,942
72 | Устройство покрытий пола плиткой "грес" на клею по цементной стяжке | 100 м2 | 5,314
73 | Укладка плинтуса из плитки "грес" на клею | 100 м | 3,2
74 | Устройство стяжек бетонных толщиной 20 мм | 100 м2 | 51,66
75 | Устройство тепло- и звукоизоляции сплошной из плит древесноволокнистых | 100 м2 | 51,66
76 | Устройство покрытий из досок паркетных | 100 м2 | 51,66
77 | Устройство плинтусов деревянных | 100 м | 51,66
78 | Устройство стяжек бетонных толщиной 20 мм | 100 м2 | 364,22
79 | Устройство покрытий из линолеума поливинилхлоридного на теплоизолирующей подоснове на клее бустилат | 100 м2 | 364,22
80 | Устройство плинтусов поливинилхлоридных с креплением шурупами | 100 м | 78,1
81 | Разработка грунта вручную в траншеях глубиной до 2 м без креплений с откосами, грунт 1 группы | 100 м3 | 1,12
82 | Устройство уплотняемых трамбовками подстилающих слоев гравийных | м3 | 26,5
83 | Устройство уплотняемых трамбовками подстилающих слоев щебеночных | м3 | 23,2
84 | Устройство покрытий асфальтобетонных жестких толщиной 25 мм | 100 м2 | 0,16
85 | Устройство крылец с входной площадкой | м2 | 66,33
86 | Устройство пароизоляции оклеечной в один слой рубероида | 100 м2 | 0,16
87 | Устройство примыканий из рубероида к стенам высотой до 600 мм без фартуков | 100 м | 0,30

4.3 Календарный план производства работ по объекту

4.3.1 Определение нормативной трудоемкости и затрат машинного времени на производство работ по объекту

По каждому строительному процессу на основании действующих нормативных источников рассчитывают его трудоемкость и требуемое количество машиносмен. Данные трудоемкости и количество машиносмен приводятся в таблице 4.3

Доработка грунта до проектной отметки осуществляется вручную. Обратная засыпка грунта в пазухи котлована производится бульдозером ДЗ-28 слоями, с обязательным послойным трамбованием слоев.

Работы по возведению фундаментов и возведению монолитного каркаса

здания осуществляются с помощью башенного крана КБ-503А.3.

Работы по устройству нулевого цикла и возведению каркаса здания ведутся в две смены.

Работы по устройству кровли и отделочные работы ведут в одну смену.

Все работы специального цикла выполняются в три этапа:

Ввод инженерных коммуникаций (I этап): устройство вводов в здание выполняются до обратной засыпки; II этап: черновые работы выполняются до начала штукатурных работ; III этап: навеска санитарно-технических приборов производится после отделочных работ.

Кровельные работы и заполнение оконных и наружных дверных проемов выполняются до начала отделочных работ.

Заключительным этапом являются работы по благоустройству территории, подготовке объекта к сдаче и непосредственно сдача объекта. Благоустройство территории заключается в разбивке газонов, посадке деревьев и кустарников, устройстве пешеходных дорожек, устройство малых форм.

Объемы работ определяются на основании принятых в проекте объемно-планировочных решений и конструктивных особенностей здания.

Таблица 4.3 – Ведомость трудоемкости

№ | Обоснование | Наименование видов работ | Ед.изм. | Количество | Затраты труда, чел-ч / маш-ч | | Состав звена
| | | | | на ед. | на весь объем
1 | 2 | 3 | 4 | 5 | 6 | 7 | 8

Подземная часть
1 | Е1-24-5 | Разработка грунта бульдозером мощностью 79 (108) кВт (л.с.) при перемещении грунта до 10 м, грунт 1 группы | 1000 м3 | 0,24 | 0 10,23 | 0 2,46 | Машинист
2 | Е1-24-13 | Разработка грунта бульдозерами мощностью 79 (108) кВт (л.с.) добавлять на каждые последующие 10 м, грунт 1 группы | 1000 м3 | 0,58 | 0 8,61 | 0 5,0 | Машинист
3 | Е1-30-2 | Планировка площадей бульдозерами мощностью 79 (108) кВт (л.с.) | 1000 м3 | 0,82 | 0 0,27 | 0 0,22 | Машинист

Продолжение таблицы 4.3

1 | 2 | 3 | 4 | 5 | 6 | 7 | 8
4 | Е1-12-13 | Разработка грунта в отвал экскаватором "ОБРАТНАЯ ЛОПАТА" с ковшом вместимостью 0,5 м3, грунт 1 группы | 1000 м3 | 0,498 | 10,75 23,36 | 5.36 11.64 | Машинист
5 | Е1-17-13 | Разработка грунта с погрузкой на автомобили-самосвалы экскаваторами с ковшом вместимостью 0,5 м3, грунт 1 группы | 1000 м3 | 2,434 | 12,3 35,73 | 29.94 86.97 | Машинист
6 | Е1-163-7 | Разработка грунта вручную в траншеях шириной более 2 м и котлованах площадью сечения до 5 м2 с креплениями, глубиной траншей и котлованов до 3 м, грунт 1 группы | 100 м3 | 0,171 | 259,3 0 | 44,35 0 | Землекоп – 2ч

Фундаменты
7 | Е5-1-4 | Погружение дизель-молотом копровой установки на базе трактора железобетонных свай длиной до 10 м, в грунты 1 группы | м3 | 243,2 | 4,35 2,95 | 1057,92 717,44 | Машинист -2ч Монтажник – 4ч
8 | Е6-57-1 | Установка арматуры | Т | 267,4 | 29,78 0,5 | 8565,03 143,81 | Арматурщик – 19ч Машинист – 1ч
9 | Е6-1-15 | Устройство фундаментных плит бетонных плоских из бетона класса В7,5 | 100 м3 | 2,7 | 116,82 15,258 | 399.52 52.18 | Бетонщик – 19ч Машинист – 1ч
10 | Е6-100-1 | Устройство монолитных железобетонных наружных стен высотой до 4 м, толщиной 400 мм в опалубке импортного производства типа "модостр" | 100м3 | 1,75 | 388,8 83,94 | 680,42 146,90 | Бетонщик – 19ч Машинист – 1ч
11 | Е8-4-3 | Гидроизоляция стен, фундаментов горизонтальная оклеечная в 2 слоя из рубероида | 100 м2 | 4,03 | 21,91 2,17 | 88,30 8,75 | Изолировщик – 6ч.
12 | Е6-57-1 | Установка арматуры | Т | 16,6 | 29,78 0,5 | 494.348 8,3 | Арматурщик – 19ч Машинист – 1ч

Продолжение таблицы 4.3

1 | 2 | 3 | 4 | 5 | 6 | 7 | 8
13 | Е6-14-16 | Устройство колонн в деревянной опалубке со стальными сердечниками (жесткой арматурой) из бетона класса с12/15, периметром до 4 м, при отношении объема сердечника или жесткой арматуры к об ему колонн до 25 процентов | 100м3 | 0,143 | 1899,8 47,55 | 271.29 6.79 | Бетонщик – 19ч Машинист – 1ч
14 | Е6-57-1 | Установка арматуры | Т | 110,8 | 29,78 0,5 | 4754.08 79.82 | Арматурщик – 19ч Машинист – 1ч
15 | Е6-22-3 | Устройство перекрытий безбалочных из бетона класса С12/15, толщиной более 200 мм на высоте от опорной площади до 6 м | 100 м3 | 1.37 | 678,5 31,93 | 928.86 43.71 | Бетонщик – 19ч Машинист – 1ч
16 | Е1-27-4 | Засыпка траншей и котлованов бульдозерами мощностью 79 (108) кВт (л.с.) при перемещении грунта до 5 м, грунт 1 группы | 1000 м3 | 0,498 | 0 5,91 | 0 2,94 | Машинист – 1ч
17 | Е1-166-1 | Засыпка вручную траншей, пазух котлованов и ям, грунт 1 группы | 100 м3 | 0,171 | 102,91 0 | 17.60 0 | Землекоп – 2ч
18 | Е1-134-1 | Уплотнение грунта пневматическими трамбовками, грунт 1 группы | 100 м3 | 5,3 | 12,53 12,18 | 66.41 64.55 | Землекоп – 2ч

Надземная часть

Несущие конструкции
19 | Е6-57-1 | Установка арматуры | Т | 165,1 | 29,78 0,5 | 5980.89 100.25 | Арматурщик – 19ч Машинист – 1ч

Продолжение таблицы 4.3

1 | 2 | 3 | 4 | 5 | 6 | 7 | 8
20 | Е6-14-16 | Устройство колонн в деревянной опалубке со стальными сердечниками (жесткой арматурой) из бетона класса с12/15, периметром до 4 м, при отношении об ема сердечника или жесткой арматуры к об ему колонн до 25 процентов | 100м3 | 1,719 | 1899,8 47,55 | 3265.75 81.74 | Бетонщик – 19ч Машинист – 1ч
21 | Е6-57-1 | Установка арматуры | Т | 1325,6 | 29,78 0,5 | 47525.9 797.95 | Арматурщик – 19ч Машинист – 1ч
22 | Е6-22-3 | Устройство перекрытий безбалочных из бетона класса С12/15, толщиной более 200 мм на высоте от опорной площади до 6 м | 100 м3 | 13,70 | 208,25 49,47 | 2852.4 677.59 | Бетонщик – 19ч Машинист – 1ч
23 | Е6-57-1 | Установка арматуры | Т | 40,34 | 29,78 0,5 | 1231.1 20.67 | Арматурщик – 19ч Машинист – 1ч
24 | Е6-105-1 | Устройство монолитных железобетонных лестничных площадок и маршей в опалубке импортного производства типа "модостр" | 100м3 | 0,355 | 637,21 133,72 | 226.209 47,47 | Бетонщик – 19ч Машинист – 1ч

Наружная отделка фасадов
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

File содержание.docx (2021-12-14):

923/21 - ПЗ Лист 10 Изм. Кол. Подп. №док.кк. Дата Лист

923/21 - ПЗ Подп. №док. Кол. Лист Разраб. Григорьев 15 Стадия Листов Лист Р Михальков Пояснительная записка Гомелюк Н.контр Макаревич Утв. БРУ ПГС-171 153 Пров. Дата Лист Изм.

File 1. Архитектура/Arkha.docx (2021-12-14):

1 Архитектурно-строительный раздел

## 1.1 Исходные данные

Площадка строительства располагается на ул. Грушевской в г. Минск, на свободной от застройки территории.

Климатический район строительства II-В по СНБ 2.04.02-2000[1]

В соответствии с ТКП 45-2.04-43-2000[2] расчетная температура наружного воздуха составляет минус 24°С (температура наиболее холодных суток обеспеченностью 0,92).
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

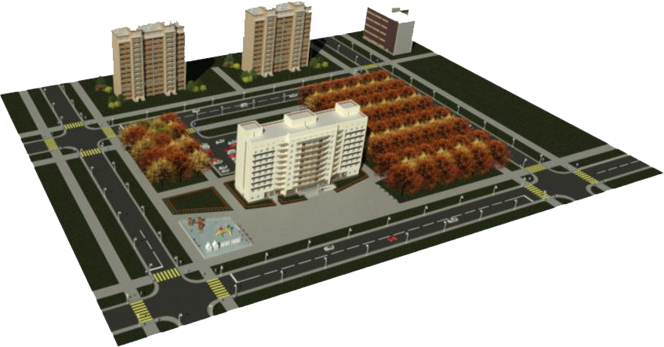
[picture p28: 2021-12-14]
Защита диплома/немного картинок/ген план.png

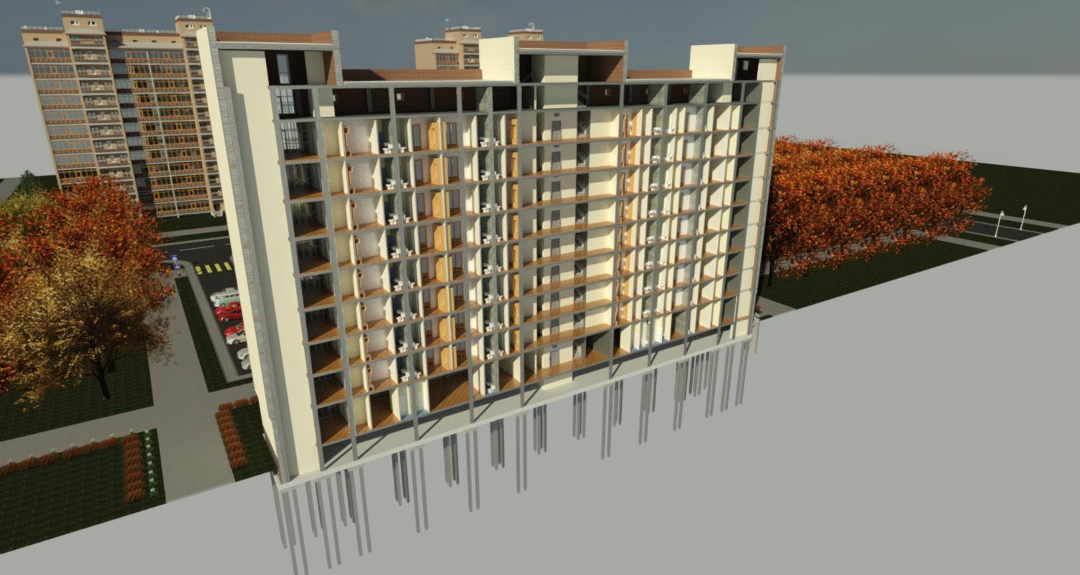
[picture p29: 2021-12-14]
Защита диплома/немного картинок/3d разрез Copy 1.jpg

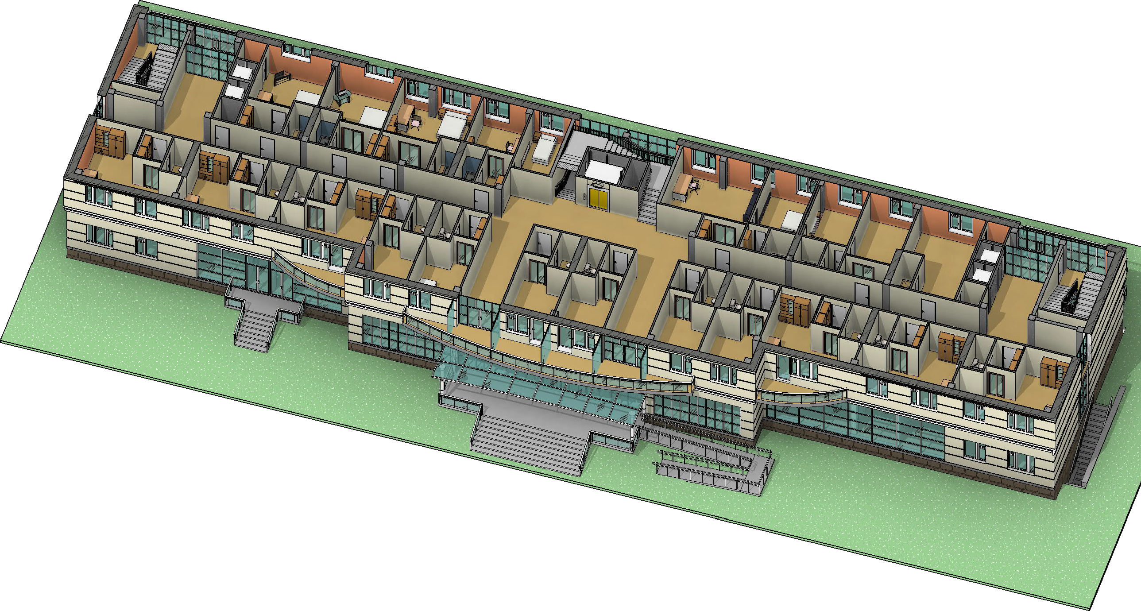
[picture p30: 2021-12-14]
Листы А1/3D разрезыпфыппфыфпыпф.png

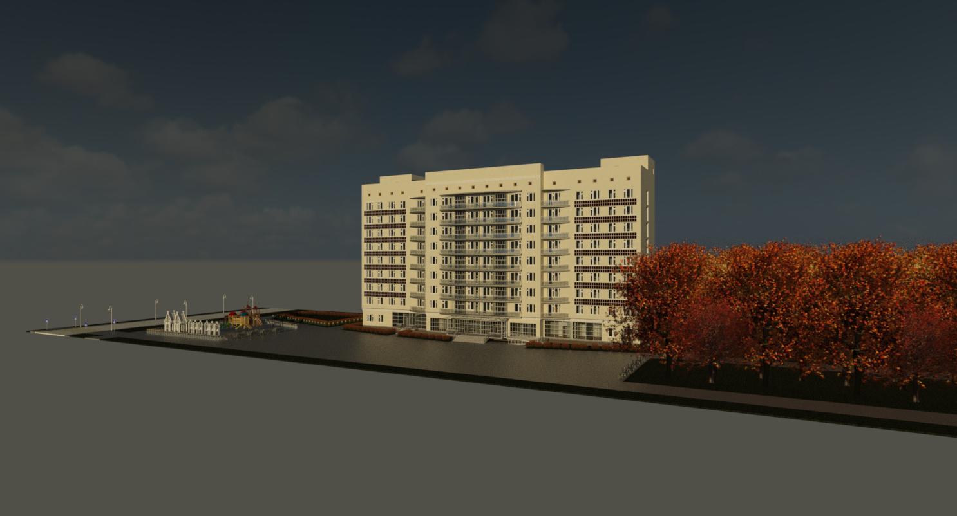
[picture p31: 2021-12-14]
Защита диплома/немного картинок/фвпфыппы.jpg

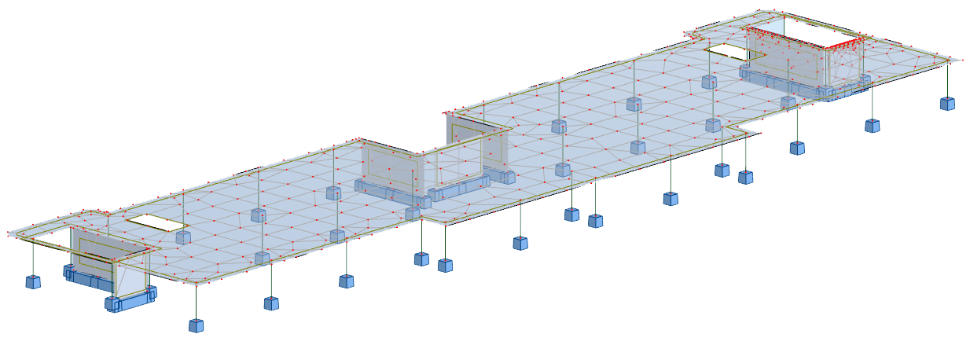
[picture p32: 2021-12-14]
Листы А1/Аналитическая модель.png

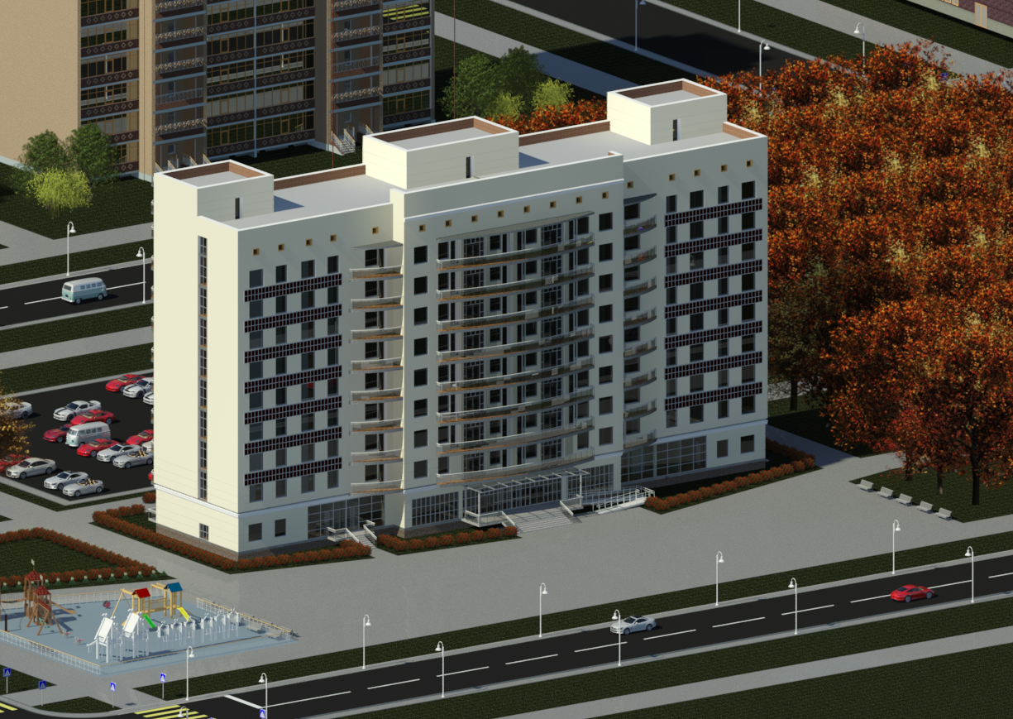
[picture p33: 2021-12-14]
Листы А1/A1_1.png

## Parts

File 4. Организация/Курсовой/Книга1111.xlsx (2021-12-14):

№ | Обоснование | Наименование видов работ | Ед.изм. | Количество | Затраты труда. чел-ч / маш-ч |  | Состав звена
 |  |  |  |  | на ед. | на весь объем |  |  |  | всего
1 | 2 | 3 | 4.00 | 5.00 | 6.00 | 7.00 | 8.00 |  |  | чел часы | 283043.10
Подземная часть |  |  |  |  |  |  |  |  |  | маш часы | 38196.62
1 | Е1-24-5 | Разработка грунта бульдозером мощностью 79 (108) кВт (л.с.) при перемещении грунта до 10 м. грунт 1 группы | 1000 м3 | 0.24 | 0.00 | 0.00 | Машинист |  |  | сантехника (10%)
 |  |  |  |  | 10.23 | 2.46 |  |  |  | электромонтаж (8%)
2 | Е1-24-13 | Разработка грунта бульдозерами мощностью 79 (108) кВт (л.с.) добавлять на каждые последующие 10 м. грунт 1 группы | 1000 м3 | 0.58 | 0.00 | 0.00 | Машинист |  |  | слаботочечные (2%)
 |  |  |  |  | 8.61 | 5.00 |  |  |  | итого
3 | Е1-30-2 | Планировка площадей бульдозерами мощностью 79 (108) кВт (л.с.) | 1000 м3 | 0.82 | 0.00 | 0.00 | Машинист |  |  | монтаж оборуд (20%)
 |  |  |  |  | 0.27 | 0.22 |  |  |  | пусконалад (5%)
4 | Е1-12-13 | Разработка грунта в отвал экскаватором "ОБРАТНАЯ ЛОПАТА" с ковшом вместимостью 0.5 м3. грунт 1 группы | 1000 м3 | 0.50 | 10.75 | 5.36 | Машинист |  |  | благоустройство (3%)
 |  |  |  |  | 23.36 | 11.64 |  |  |  | итого
5 | Е1-17-13 | Разработка грунта с погрузкой на автомобили-самосвалы экскаваторами с ковшом вместимостью 0.5 м3. грунт 1 группы | 1000 м3 | 2.43 | 12.30 | 29.94 | Машинист |  |  | Неучтенные работы (12%)
 |  |  |  |  | 35.73 | 86.97 |  |  |  | итого
6 | Е1-163-7 | Разработка грунта вручную в траншеях шириной более 2 м и котлованах площадью сечения до 5 м2 с креплениями. глубиной траншей и котлованов до 3 м. грунт 1 группы | 100 м3 | 0.17 | 259.33 | 44.35 | Землекоп – 2ч |  |  | подготовительный период (6%)
 |  |  |  |  | 0.00 | 0.00 |  |  |  | Сдача объекта (1%)
Фундаменты |  |  |  |  |  |  |  |  |  | итого
7 | Е5-1-4 | Погружение дизель-молотом копровой установки на базе трактора железобетонных свай длиной до 10 м. в грунты 1 группы | м3 | 243.20 | 4.35 | 1057.92 | Машинист -2ч
 |  |  |  |  | 2.95 | 717.44 | Монтажник – 4ч
8 | Е6-57-1 | Установка арматуры | Т | 398.50 | 29.78 | 11867.33 | Арматурщик – 6ч
 |  |  |  |  | 0.50 | 199.25
9 | Е6-1-15 | Устройство фундаментных плит бетонных плоских из бетона класса В7.5 | 100 м3 | 3.42 | 116.82 | 399.52 | Бетонщик – 4ч
 |  |  |  |  | 15.26 | 52.18
10 | Е6-100-1 | Устройство монолитных железобетонных наружных стен высотой до 4 м. толщиной 400 мм в опалубке импортного производства типа "модостр" | 100м3 | 1.75 | 388.81 | 680.42 | Каменщик – 4ч
 |  |  |  |  | 83.94 | 146.89
11 | Е8-4-3 | Гидроизоляция стен. фундаментов горизонтальная оклеечная в 2 слоя из рубероида | 100 м2 | 4.03 | 21.91 | 88.30 | Каменщик – 4ч
 |  |  |  |  | 2.17 | 8.75
12 | Е6-57-1 | Установка арматуры | Т | 16.60 | 29.78 | 494.35 | Арматурщик – 6ч
 |  |  |  |  | 0.50 | 8.30
13 | Е6-14-16 | Устройство колонн в деревянной опалубке со стальными сердечниками (жесткой арматурой) из бетона класса с12/15. периметром до 4 м. при отношении объема сердечника или жесткой арматуры к об ему колонн до 25 процентов | 100м3 | 0.14 | 1899.80 | 271.29 | Бетонщик – 6ч
 |  |  |  |  | 47.55 | 6.79
14 | Е6-57-1 | Установка арматуры | Т | 159.64 | 29.78 | 4754.08 | Арматурщик – 6ч
 |  |  |  |  | 0.50 | 79.82
15 | Е6-22-3 | Устройство перекрытий безбалочных из бетона класса С12/15. толщиной более 200 мм на высоте от опорной площади до 6 м | 100 м3 | 1.37 | 678.50 | 928.87 | Бетонщик – 6ч
 |  |  |  |  | 31.93 | 43.71
16 | Е1-27-4 | Засыпка траншей и котлованов бульдозерами мощностью 79 (108) кВт (л.с.) при перемещении грунта до 5 м. грунт 1 группы | 1000 м3 | 0.50 | 0.00 | 0.00 | Машинист – 1ч
 |  |  |  |  | 5.91 | 2.94
17 | Е1-166-1 | Засыпка вручную траншей. пазух котлованов и ям. грунт 1 группы | 100 м3 | 0.17 | 102.91 | 17.60 | Землекоп – 2ч
 |  |  |  |  | 0.00 | 0.00
18 | Е1-134-1 | Уплотнение грунта пневматическими трамбовками. грунт 1 группы | 100 м3 | 5.30 | 12.53 | 66.41 | Землекоп – 2ч
 |  |  |  |  | 12.18 | 64.55
Надземная часть
Несущие конструкции
19 | Е6-57-1 | Установка арматуры | Т | 200.50 | 29.78 | 5970.89 | Арматурщик – 6ч
 |  |  |  |  | 0.50 | 100.25
20 | Е6-14-16 | Устройство колонн в деревянной опалубке со стальными сердечниками (жесткой арматурой) из бетона класса с12/15. периметром до 4 м. при отношении об ема сердечника или жесткой арматуры к об ему колонн до 25 процентов | 100м3 | 1.72 | 1899.80 | 3265.76 | Бетонщик 6ч
 |  |  |  |  | 47.55 | 81.74
21 | Е6-57-1 | Установка арматуры | Т | 1595.90 | 29.78 | 47525.90 | Арматурщик – 6ч
 |  |  |  |  | 0.50 | 797.95
22 | Е6-22-3 | Устройство перекрытий безбалочных из бетона класса С12/15. толщиной более 200 мм на высоте от опорной площади до 6 м | 100 м3 | 13.70 | 208.25 | 2852.40 | Бетонщик 6ч
 |  |  |  |  | 49.47 | 677.59
23 | Е6-57-1 | Установка арматуры | Т | 41.34 | 29.78 | 1231.11 | Арматурщик – 6ч
 |  |  |  |  | 0.50 | 20.67
24 | Е6-105-1 | Устройство монолитных железобетонных лестничных площадок и маршей в опалубке импортного производства типа "модостр" | 100м3 | 0.35 | 637.21 | 226.21 | Бетонщик 6ч
 |  |  |  |  | 133.72 | 47.47
Наружная отделка фасадов
25 | Е8-52-1 | Возведение трехслойных стен из газосиликатных блоков на клею толщиной 500 мм | м3 | 998.13 | 5.47 | 5459.77 | Каменщик – 8ч
 |  |  |  |  | 0.16 | 159.70
26 | Е26-12-3 | Изоляция поверхностей плоских изделиями минераловатными с гофрированной структурой | 10м2 | 296.92 | 7.41 | 2200.18 | Монтажник - 4ч
 |  |  |  |  | 0.98 | 290.98
27 | Е15-380-1 | Устройство навесных вентилируемых фасадов из алюминиевого профиля с облицовкой керамогранитными плитами размером 600х1200 мм со скрытым креплением на аграфах на междуэтажную систему | 100м2 | 29.69 | 385.68 | 11450.84 | Монтажник - 4ч
 |  |  |  |  | 35.99 | 1068.54
Стены и перегородки
28 | Е8-7-502 | Кладка перегородок неармированных толщиной в 1 2 кирпича при высоте этажа до 4 м из кирпича силикатного утолщенного | 100м2 | 28.03 | 143.99 | 4036.47 | Каменщик – 8ч
 |  |  |  |  | 5.72 | 160.35
29 | Е6-18-9 | Устройство перемычек железобетонных из бетона класса с12/15 | 100м3 | 0.75 | 1593.00 | 1194.75 | Бетонщик - 2ч
 |  |  |  |  | 55.70 | 41.78 | Арматурщик - 2ч
30 | Е6-103-1 | Устройство монолитного железобетонного лифтового блока в опалубке импортного производства типа "модостр" | 100м3 | 0.72 | 456.44 | 326.81 | Бетонщик 4ч
 |  |  |  |  | 151.81 | 108.70 | Арматурщик – 2ч
Кровля
31 | Е 12-91-1 | Устройство выравнивающих стяжек под кровлю без армирования толщиной 30 мм | 100м2 | 8.55 | 49.27 | 421.26 | Бетонщик - 4ч
 |  |  |  |  | 1.92 | 16.42
32 | Е12-13-3 | Утепление покрытий плитами из минеральной ваты или перлита на битумной мастике | 100м2 | 8.55 | 45.54 | 389.37 | Кровельщик – 4ч
 |  |  |  |  | 1.68 | 14.36
33 | Е12-115-1 | Огрунтовка оснований кровли механизированным способом |  | 8.55 | 1.17 | 10.00 | Кровельщик – 4ч
 |  |  | 100 м2 |  | 0.52 | 4.45
34 | Е12-15-1 | Устройство пароизоляции оклеечной в один слой | 100м3 | 8.55 | 17.51 | 149.71 | Кровельщик – 4ч
 |  |  |  |  | 1.30 | 11.12
35 | Е12-104-1 | Устройство двухслойных кровель из наплавляемых рулонных материалов при механическом закреплении нижнего слоя водоизоляционного ковра |  | 8.55 | 31.96 | 273.26 | Кровельщик – 4ч
 |  |  | 100 м2 |  | 0.30 | 2.56
36 | Е16-21-1 | Установка воронок водосточных | Шт | 4.00 | 2.94 | 11.76 | Кровельщик – 4ч
 |  |  |  |  | 0.02 | 0.08
37 | Е12-112-1 | Устройство примыканий кровли из наплавляемых рулонных материалов к воронке внутреннего водостока | 100шт | 0.04 | 152.07 | 6.08 | Кровельщик – 4ч
 |  |  |  |  | 0.22 | 0.01
38 | Е12-9-1 | Устройство желобов настенных | 100мжел. | 8.55 | 84.75 | 724.61 | Кровельщик – 4ч
 |  |  |  |  | 2.57 | 21.97
39 | Е12-22-1 | Устройство примыканий к парапетам и другим выступающим частям здания при устройстве покрытия кровли из рулонных материалов | 100м | 0.76 | 81.70 | 62.42 | Кровельщик – 4ч
 |  |  |  |  | 0.96 | 0.73
40 | Е15-379-1 | Облицовка парапета фасадными панелями | 100м пара | 0.76 | 61.28 | 46.57 | Кровельщик – 4ч
 |  |  |  |  | 0.04 | 0.03
Окна
41 | Е10-101-2 | Установка окон из ПВХ со стеклопакетами в проемы кирпичных стен с креплением поворотными анкерами при площади изделия до 2 м2 | 100 м2 | 0.10 | 134.42 | 12.97 | Монтажник – 4ч
 |  |  |  |  | 0.00 | 0.00
42 | Е10-101-3 | Установка окон из ПВХ со стеклопакетами в проемы кирпичных стен с креплением | 100 м2 | 1.94 | 125.62 | 243.70 | Монтажник – 4ч
 |  | поворотными анкерами при площади изделия до 3 м2 |  |  | 0.00 | 0.00
43 | Е10-101-4 | Установка окон из пвх со стеклопакетами в проемы кирпичных стен с креплением поворотными анкерами при площади изделия свыше 3 м2 | 100 м2 | 4.96 | 116.12 | 576.05 | Монтажник – 4ч
 |  |  |  |  | 0.00 | 0.00
44 | Е10-102-2 | Установка блоков окно-балконная дверь из ПВХ со стеклопакетами в проемы кирпичных стен при площади изделия свыше 3 м2 | 100 м2 | 11.09 | 106.32 | 1179.09 | Монтажник – 4ч
 |  |  |  |  | 0.00 | 0.00
45 | Е10-107-1 | Соединение окна и балконной рамы при помощи подставочного профиля | 100 м | 0.75 | 19.60 | 14.70 | Монтажник – 4ч
 |  |  |  |  | 0.00 | 0.00
46 | Е10-104-1 | Установка подоконных досок из ДСП | 100 м | 0.75 | 74.37 | 55.78 | Монтажник – 4ч
 |  |  |  |  | 0.00 | 0.00
47 | Е10-103-1 | Герметизация мест примыкания оконных и балконных блоков из пвх к стенам толщиной зазора 0.03 м | 100 м2 | 2.33 | 13.03 | 30.36 | Монтажник – 4ч
 |  |  |  |  | 0.00 | 0.00
Двери
48 | Е10-23-1 | Установка блоков в наружных и внутренних дверных проемах в каменных стенах. площадь | 100 м2 | 0.06 | 91.40 | 5.48 | Монтажник – 4ч
 |  | проема до 3 м2 |  |  | 13.67 | 0.82
49 | Е10-23-3 | Установка блоков в наружных и внутренних дверных проемах в перегородках и деревянных нерубленых стенах. площадь проема до 3 м2 | 100 м2 | 1.66 | 116.00 | 192.56 | Монтажник – 4ч
 |  |  |  |  | 5.98 | 9.93
50 | Е10-23-5 | Установка блоков для люков в перекрытиях | 100 м2 | 0.02 | 129.00 | 2.09 | Монтажник – 4ч
 |  |  |  |  | 5.82 | 0.09
Внутренние отделочные работы
51 | Е15-69-2 | Отделка поверхностей стен и перегородок из блоков и плит под окраску или оклейку обоями | 100М2 | 122.51 | 11.06 | 1354.96 | Монтажник – 4ч
 |  |  |  |  | 0.10 | 12.25
52 | Е15-315-1 | Улучшенная окраска потолков акриловыми составами по монолитным конструкциям. подготовленным под окраску | 100 м2 | 86.59 | 59.22 | 5127.86 | Монтажник – 4ч
 |  |  |  |  | 0.03 | 2.60
53 | Е15-326-2 | Декоративная штукатурка типа "байрамикс" внутренних поверхностей стен средней фракции 1.0 мм | 100м2 | 32.40 | 78.11 | 2530.76 | Монтажник – 4ч
 |  |  | пов |  | 0.00 | 0.00
54 | Е15-65-1 | Штукатурка плоских поверхностей оконных и дверных откосов по камню | 100 м2 | 2.34 | 204.06 | 477.50 | Штукатурщик – 4ч
 |  |  |  |  | 1.49 | 3.49
55 | Е15-18-1 | Облицовка белыми керамическими глазурованными плитками поверхностей стен в жилых зданиях по кирпичу | 100 м2 | 26.95 | 226.25 | 6097.44 | Плиточник – 8ч
 |  |  |  |  | 0.32 | 8.62
56 | Е15-314-1 | Высококачественная окраска стен внутри помещений акриловыми составами с полной подготовкой поверхности по штукатурке | 100 м2 | 2.34 | 69.42 | 162.44 | Маляр – 4ч
 |  |  |  |  | 0.05 | 0.12
57 | Е15-267-1 | Оклейка стен и перегородок обоями со сплошным шпатлеванием простыми и средней плотности с подбором рисунка | 100 м2 | 122.51 | 38.25 | 4686.01 | Маляр – 4ч
 |  |  |  |  | 0.00 | 0.00
Полы
Тип 1(пол подвала)
58 | Е11-11-3 | Устройство стяжек цементных толщиной 20 мм | 100 м2 | 1.45 | 40.65 | 58.86 | Бетонщик – 4ч
 |  |  |  |  | 1.90 | 2.75
Тип 2(пол 1го этажа коридоры)
59 | Е12-13-5 | Утепление покрытий плитами из легких бетонов | 100 м2 | 2.58 | 33.90 | 87.46 | Бетонщик – 4ч
 |  |  |  |  | 3.20 | 8.26
60 | Е11-11-3 | Устройство стяжек цементных толщиной 20 мм | 100 м2 | 2.58 | 40.65 | 104.88 | Бетонщик – 4ч
 |  |  |  |  | 1.90 | 4.90
61 | Е11-9-2 | Устройство звукоизоляции сплошной из плит древесноволокнистых | 100 м2 | 2.58 | 8.06 | 20.79 | Плотник – 4ч
 |  |  |  |  | 0.97 | 2.50
62 | Е11-34-1 | Устройство покрытий из досок паркетных | 100 м2 | 2.58 | 35.19 | 90.79 | Плотник – 4ч
 |  |  |  |  | 1.09 | 2.81
63 | Е11-39-1 | Устройство плинтусов деревянных | 100 м | 0.15 | 7.65 | 1.15 | Плотник – 4ч
 |  |  |  |  | 0.08 | 0.01
Тип 3(пол 1го этажа сан. помещения)
64 | Е12-13-5 | Утепление покрытий плитами из легких бетонов | 100 м2 | 0.35 | 33.90 | 12.00 | Бетонщик – 4ч
 |  |  |  |  | 3.20 | 1.13
65 | Е11-11-3 | Устройство стяжек цементных толщиной 20 мм | 100 м2 | 0.35 | 26.97 | 9.55 | Бетонщик – 4ч
 |  |  |  |  | 1.33 | 0.47
66 | Е11-4-5 | Устройство гидроизоляции обмазочной в один слой толщиной 2 мм | 100 м2 | 0.35 | 50.23 | 17.78 | Бетонщик – 4ч
 |  |  |  |  | 1.90 | 0.67
67 | Е11-11-5 | Устройство стяжек легкобетонных толщиной 20 мм | 100 м2 | 0.35 | 40.65 | 14.39 | Бетонщик – 4ч
 |  |  |  |  | 1.90 | 0.67
68 | Е11-47-3 | Устройство покрытий пола плиткой "ГРЕС" на клею по цементной стяжке | 100 м2 | 0.35 | 163.16 | 57.76 | Плиточник – 4ч
 |  |  |  |  | 0.19 | 0.07
69 | Е11-49-1 | Укладка плинтуса из плитки "ГРЕС" на клею | 100 м | 0.12 | 36.47 | 4.38 | Плиточник – 4ч
 |  |  |  |  | 0.03 | 0.00336
Тип 4(пол 1го этажа в комнатах)
70 | Е12-13-5 | Утепление покрытий плитами из легких бетонов | 100 м2 | 8.96 | 33.90 | 303.74 | Бетонщик – 4ч
 |  |  |  |  | 3.20 | 28.67
71 | Е11-11-3 | Устройство стяжек цементных толщиной 20 мм | 100 м2 | 8.96 | 40.65 | 364.22 | Бетонщик – 4ч
 |  |  |  |  | 1.90 | 17.02
72 | Е11-36-3 | Устройство покрытий из линолеума на клее БУСТИЛАТ | 100 м2 | 8.96 | 47.06 | 421.66 | Плотник – 4ч
 |  |  |  |  | 0.70 | 6.27
Тип 5(пол типового этажа коридоры)
73 | Е11-11-3 | Устройство стяжек цементных толщиной 20 мм | 100 м2 | 20.66 | 40.65 | 839.83 | Бетонщик – 4ч
 |  |  |  |  | 1.90 | 39.25
74 | Е11-9-2 | Устройство звукоизоляции сплошной из плит древесноволокнистых | 100 м2 | 20.66 | 8.06 | 166.52 | Плотник – 4ч
 |  |  |  |  | 0.97 | 20.04
75 | Е11-34-1 | Устройство покрытий из досок паркетных | 100 м2 | 20.66 | 35.19 | 727.03 | Плотник – 4ч
 |  |  |  |  | 1.09 | 22.52
76 | Е11-39-1 | Устройство плинтусов деревянных | 100 м | 1.20 | 7.65 | 9.18 | Плотник – 4ч
 |  |  |  |  | 0.08 | 0.10
Тип 6(пол типового этажа сан. помещения)
77 | Е11-11-3 | Устройство стяжек цементных толщиной 20 мм | 100 м2 | 4.96 | 40.65 | 201.62 | Бетонщик – 4ч
 |  |  |  |  | 1.90 | 9.42
78 | Е11-4-5 | Устройство гидроизоляции обмазочной в один слой толщиной 2 мм | 100 м2 | 4.96 | 26.97 | 133.77 | Бетонщик – 4ч
 |  |  |  |  | 1.33 | 6.60
79 | Е11-11-5 | Устройство стяжек легкобетонных толщиной 20 мм | 100 м2 | 4.96 | 50.23 | 249.14 | Бетонщик – 4ч
 |  |  |  |  | 1.90 | 9.42
80 | Е11-47-3 | Устройство покрытий пола плиткой "ГРЕС" на клею по цементной стяжке | 100 м2 | 4.96 | 163.16 | 809.27 | Плиточник – 4ч
 |  |  |  |  | 0.19 | 0.94
81 | Е11-49-1 | Укладка плинтуса из плитки "ГРЕС" на клею | 100 м | 4.00 | 36.47 | 145.88 | Плиточник – 4ч
 |  |  |  |  | 0.03 | 0.11
Тип 7(пол типового этажа в помещениях)
82 | Е11-11-3 | Устройство стяжек цементных толщиной 20 мм | 100 м2 | 71.68 | 40.65 | 2913.79 | Бетонщик – 4ч
 |  |  |  |  | 1.90 | 136.19
83 | Е11-36-3 | Устройство покрытий из линолеума на клее БУСТИЛАТ | 100 м2 | 71.68 | 47.06 | 3373.26 | Плотник – 4ч
 |  |  |  |  | 0.70 | 50.18
Отмостка и крыльца
84 | Е1-164-1 | Разработка грунта вручную в траншеях глубиной до 2 м без креплений с откосами. грунт 1 группы | 100 м3 | 1.12 | 137.23 | 153.70 | Землекоп – 4ч
 |  |  |  |  | 0.00 | 0.00
85 | Е11-2-1 | Устройство уплотняемых трамбовками подстилающих слоев гравийных | м3 | 26.50 | 3.41 | 90.37 | Землекоп – 4ч
 |  |  |  |  | 0.22 | 5.83
86 | Е11-2-4 | Устройство уплотняемых трамбовками подстилающих слоев щебеночных | м3 | 23.20 | 3.73 | 86.54 | Землекоп – 4ч
 |  |  |  |  | 0.46 | 10.67
87 | Е11-19-3 | Устройство покрытий асфальтобетонных жестких толщиной 25 мм | 100 м2 | 0.16 | 16.16 | 2.59 | Бетонщик – 4ч
 |  |  |  |  | 3.27 | 0.52
88 | Е8-27-1 | Устройство крылец с входной площадкой | м2 | 66.33 | 1.67 | 110.77 | Бетонщик – 4ч
 |  |  |  |  | 0.11 | 7.30
89 | Е12-15-1 | Устройство пароизоляции оклеечной в один слой рубероида | 100 м2 | 0.16 | 17.51 | 2.80 | Монтажник – 4ч
 |  |  |  |  | 1.30 | 0.21
90 | Е12-4-1 | Устройство примыканий из рубероида к стенам высотой до 600 мм без фартуков | 100 м | 0.30 | 26.10 | 7.96 | Монтажник – 4ч
 |  |  |  |  | 1.16 | 0.35
Итого |  |  |  |  |  | 142885.03
 |  |  |  |  |  | 5498.17
Сантехнические работы (10%) |  |  |  |  |  | 14288.50
Электромонтажные работы (8%) |  |  |  |  |  | 11430.80
Слаботочные работы (2%) |  |  |  |  |  | 2857.70
ИТОГО |  |  |  |  |  | 171462.04
Монтаж оборудования (20%) |  |  |  |  |  | -
Пусконаладочные работы (5%) |  |  |  |  |  | -
Благоустройство территории (3%) |  |  |  |  |  | 5143.86
ИТОГО |  |  |  |  |  | 176605.90
Неучтенные работы (12%) |  |  |  |  |  | 21192.71
ИТОГО |  |  |  |  |  | 197798.61
Подготовительный период (6%) |  |  |  |  |  | 11867.92
Сдача объекта (1%) |  |  |  |  |  | 1977.99
ИТОГО |  |  |  |  |  | 211644.51
№ | Шифр | Наименование работ | Трудоем-кость | Трудоем-кость | Кол. рабочих в смену | Кол-во | Продол-житель-ность
п/п | работы |  | работ | работ |  | смен
 |  |  | чел-ч | чел-дн
1 | 2 | 3 | 4.00 | 5.00 | 6.00 | 7.00 | 8.00
 | - | Подготовительный период | 11867.92 | 1483.49 | 22.00 | 2.00 | 33.72 | 32
 | 2020-01-03 | Срезка растительного слоя и планировка площадки | 7.68 | 0.96 | 1.00 | 2.00 | 0.40 | 1
 | - | Неучтенные работы | 21192.71 | 2649.09 | 3.00 | 2.00 | 441.51 | 416
 | 2020-04-05 | Разработка грунта экскаватором | 98.61 | 12.33 | 2.00 | 2.00 | 2.57 | 3
 | 7 | Забивка свай | 717.44 | 89.68 | 4.00 | 1.00 | 18.68 | 20
 | 6,8,9 | Устройство монолитной фундаментной плиты | 12311.20 | 1538.90 | 14.00 | 2.00 | 45.80 | 46 | 102
 | 2020-10-18 | Устройство подвала+ГИ, обратная засыпка и уплотнение грунта | 7301.31 | 912.66 | 14.00 | 2.00 | 27.16 | 28 | 130
 | - | Ввод инженерных сетей | 1399.68 | 174.96 | 3.00 | 2.00 | 24.30 | 25 |  | 264
 | 19-24, 30 | Устройство монолитного каркаса здания | 61399.07 | 7674.88 | 17.00 | 2.00 | 188.11 | 190 | 320 | 176
 | 25,28-29 | Кладка перегородок и стен 10-9 этаж | 4336.00 | 542.00 | 17.00 | 2.00 | 15.94 | 16
 |  | Кладка перегородок и стен 8-7 этаж | 4336.00 | 542.00 | 17.00 | 2.00 | 15.94 | 16 |  | 440
 |  | Кладка перегородок и стен 6-5 этаж | 4336.00 | 542.00 | 17.00 | 2.00 | 15.94 | 16
 |  | Кладка перегородок и стен 4-3 этаж | 4336.00 | 542.00 | 17.00 | 2.00 | 15.94 | 16
 |  | Кладка перегородок и стен 2-1 этаж+подвал | 4336.00 | 542.00 | 17.00 | 2.00 | 13.28 | 16
 | 31-40 | Устройство кровли | 2095.04 | 261.88 | 16.00 | 1.00 | 13.64 | 14
 | 26-27 | Отделка фасада | 13651.02 | 1706.38 | 20.00 | 2.00 | 35.55 | 36
 | 84-90 | Устройство отмостки и крылец | 454.72 | 56.84 | 16.00 | 1.00 | 3.55
 | 41-50 | Заполнение проемов 10-9 этаж | 462.56 | 57.82 | 7.00 | 1.00 | 8.26 | 8
 |  | Заполнение проемов 8-7 этаж | 462.56 | 57.82 | 7.00 | 1.00 | 6.88 | 8
 |  | Заполнение проемов 6-5 этаж | 462.56 | 57.82 | 7.00 | 1.00 | 6.88 | 8
 |  | Заполнение проемов 4-3 этаж | 462.56 | 57.82 | 7.00 | 1.00 | 6.88 | 8
 |  | Заполнение проемов 2-1этаж +подвал | 462.56 | 57.82 | 7.00 | 1.00 | 6.88 | 8
 | 58,59-60,64-67,70-71,73, 77-79, 82 | Подготовка под полы 10-9 этаж | 1062.21 | 132.78 | 10.00 | 2.00 | 6.64 | 8
 |  | Подготовка под полы 8-7 этаж | 1062.21 | 132.78 | 10.00 | 2.00 | 5.53 | 8
 |  | Подготовка под полы 6-5 этаж | 1062.21 | 132.78 | 10.00 | 2.00 | 5.53 | 8
 |  | Подготовка под полы 4-3 этаж | 1062.21 | 132.78 | 10.00 | 2.00 | 5.53 | 8
 |  | Подготовка под полы 2-1 этаж +подвал | 1062.21 | 132.78 | 7.00 | 2.00 | 7.90 | 8
 | 53-55 | Штукатурка и плитка(стены) 10-9 этаж | 1821.14 | 227.64 | 12.00 | 2.00 | 7.90 | 8
 | 53,54, 55 | Штукатурка и плитка(стены) 8-7 этаж | 1821.14 | 227.64 | 12.00 | 2.00 | 7.90 | 8
 |  | Штукатурка и плитка(стены) 6-5 этаж | 1821.14 | 227.64 | 12.00 | 2.00 | 7.90 | 8
 |  | Штукатурка и плитка(стены) 4-3 этаж | 1821.14 | 227.64 | 12.00 | 2.00 | 7.90 | 8
 |  | Штукатурка и плитка(стены) 2-1 этаж+подвал | 1821.14 | 227.64 | 12.00 | 2.00 | 7.90 | 8
 | 52,56 | Подготовка под окраску и окраска водными составами 10-9 этаж | 1058.06 | 132.26 | 8.00 | 2.00 | 6.89 | 8
 |  | Подготовка под окраску и окраска водными составами 8-7 этаж | 1058.06 | 132.26 | 8.00 | 2.00 | 6.89 | 8
 |  | Подготовка под окраску и окраска водными составами 6-5 этаж | 1058.06 | 132.26 | 8.00 | 2.00 | 6.89 | 8
 |  | Подготовка под окраску и окраска водными составами 4-3 этаж | 1058.06 | 132.26 | 8.00 | 2.00 | 6.89 | 8 | 600
 |  | Подготовка под окраску и окраска водными составами 2-1 этаж+подвал | 1058.06 | 132.26 | 8.00 | 2.00 | 6.89 | 8
 | 61-63, 68-69, 72, 74-76, 80-81, 83 | Чистые полы 10-9 этаж | 1205.07 | 150.63 | 8.00 | 2.00 | 7.85 | 8
 |  | Чистые полы 8-7 этаж | 1205.07 | 150.63 | 8.00 | 2.00 | 7.85 | 8
 |  | Чистые полы 6-5 этаж | 1205.07 | 150.63 | 8.00 | 2.00 | 7.85 | 8 |  |  |  | 72
 |  | Чистые полы 4-3 этаж | 1205.07 | 150.63 | 8.00 | 2.00 | 7.85 | 8
 |  | Чистые полы 2-1 этаж+подвал | 1205.07 | 150.63 | 8.00 | 2.00 | 7.85 | 8
 | 51,57 | Оклейка обоями 10-9 этаж | 1208.19 | 151.02 | 8.00 | 2.00 | 7.87 | 8
 |  | Оклейка обоями 8-7 этаж | 1208.19 | 151.02 | 8.00 | 2.00 | 7.87 | 8
 |  | Оклейка обоями 6-5 этаж | 1208.19 | 151.02 | 8.00 | 2.00 | 7.87 | 8
 |  | Оклейка обоями 4-3 этаж | 1208.19 | 151.02 | 8.00 | 2.00 | 7.87 | 8 |  |  | 16
 |  | Оклейка обоями 2-1 этаж | 1208.19 | 151.02 | 8.00 | 2.00 | 7.87 | 8
 | - | Электротехнические работы 1 этап (60%) | 6858.48 | 857.31 | 6.00 | 2.00 | 59.54 | 72
 | - | Сантехнические работы 1 этап (60%) | 8573.10 | 1071.64 | 8.00 | 2.00 | 55.81 | 72
 | - | Устройство слаботочных сетей 1 этап (60%) | 1714.62 | 214.33 | 3.00 | 1.00 | 71.44 | 72
 | - | Электротехнические работы 2 этап (40%) | 4572.32 | 571.54 | 6.00 | 2.00 | 39.69 | 38
 | - | Сантехнические работы 2 этап (40%) | 5715.40 | 714.43 | 8.00 | 2.00 | 37.21 | 38
 | - | Устройство слаботочных сетей 2 этап (40%) | 1143.08 | 142.89 | 3.00 | 1.00 | 39.69 | 38
 | - | Благоустройство территории | 5143.86 | 642.98 | 12.00 | 1.00 | 44.65 | 40
 | - | Сдача объекта | 1977.99 | 247.25 | 12.00 | 1.00 | 20.60 | 20
 |  |  |  | 27995.18
 |  |  | Буквен- ное обо- значение |  |  |  | Вели- чина |  |  |  |  | Расчетная числен- ность работающих
 |  | Наименование катего- рии работающих |  | Расчет |  |  | пока- зателя |  |  | Наименование временных зданий и сооружений | Категория работающих | N1 , чел.
 |  | 1 | 2.00 | 3.00 |  |  | 4.00 |  |  | 1 | 2 | 3
 |  | Максимальная рас- четная численность рабочих в сутки | Nраб | Принимается по графику движения рабочих кадров по объекту |  |  | 157 |  |  | Административные здания
 |  | Общая численность ежедневно работа- ющих | N | N = (Nраб · 100) / Краб = 134 ·100 / 83,9, где Краб = 83,9 (см. таблицу А.1) |  |  | 187.1275328 |  |  | Контора начальника участка | Nлин.см | 12.05101311
 |  | Максимальная рас- четная численность ИТР в сутки | NИТР | NИТР = (N · КИТР) / 100 = (160 · 11) / 100, |  |  | 20.58402861 |  |  | Помещения для проведения занятий по технике безопасности | На максимальную численность рабочих одной специальности | 34
 |  |  |  | где КИТР = 11 % (см. таблицу А.1) |  |  |  |  |  | Диспетчерская | Диспетчеры – 1 % от Nлин.см | 1.00
 |  | Максимальная рас- четная численность МОП в сутки | NМОП | NМОП = (N · КМОП) / 100 = (160· 1,5) / 100, |  |  | 2.806912992 |  |  | Красный уголок | Nр | 127.4460131
 |  |  |  | где КМОП = 1,5 % (см. таблицу А.1) |  |  |  |  |  |  | max
 |  | Максимальная рас- четная численность служащих в сутки | Nслуж | Nслуж = (N · Кслуж) / 100 = (160 · 3,6) / 100, где Кслуж = 3,6 % (см. таблицу А.1) |  |  | 6.73659118 |  |  | Санитарно-бытовые помещения
 |  | Максимальный списочный состав | Nраб.сут | Nраб.сут = Nраб · k = 134 ·1,05 |  |  | 164.85 |  |  | Гардероб мужской | Nм | 109.9
 |  | рабочих в сутки |  |  |  |  |  |  |  |  | раб.сут
 |  | Списочный состав рабочих-мужчин в сутки | Nм | Nм = 0,7 ·N = 0,7 · 141 |  |  | 109.9 |  |  | Гардероб женский | Nж | 47.1
 |  |  | раб.сут | раб.сут раб.сут |  |  |  |  |  |  | раб.сут
 |  | Списочный состав рабочих-женщин в | Nж | Nж = 0,3 ·N = 0,3 · 141 |  |  | 47.1 |  |  | Помещение для отдыха | Nр | 127.4460131
 |  | сутки | раб.сут | раб.сут раб.сут |  |  |  |  |  |  | max
 |  | Максимальная рас- четная списочная численность рабо- чих в наиболее многочисленную смену | Nраб.см | Nраб.см = 0,7 ·Nраб.сут = 0,7 · 141 |  |  | 115.395 |  |  | Душевая с преддушевой мужская | Nм | 109.9
 |  |  |  |  |  |  |  |  |  |  | раб.см
 |  |  |  |  |  |  |  |  |  | Душевая с преддушевой женская | Nж | 47.1
 |  |  |  |  |  |  |  |  |  |  | раб.см
 |  |  |  |  |  |  |  |  |  | Умывальная мужская | N м | 109.9
 |  |  |  |  |  |  |  |  |  |  | см
 |  | Максимальная спи- сочная численность ИТР, служащих, МОП в наиболее многочисленную | Nлин.см | Nлин.см= k · [(NИТР + Nслуж +NМОП ) · 0,8 ·0,5] = |  |  | 12.05101311 |  |  | Умывальная женская | N ж | 47.1
 |  | смену |  | = 1,05 [(18 +6 + 3) · 0,8 · 0,5] |  |  |  |  |  |  | см
 |  | Общая расчетная | Nр | Nр = Nраб | .см + Nлин.см = 99 + 12 |  | 127.4460131 |  |  | Туалет мужской | N м | 109.9
 |  | численность рабо- | max |  |  |  |  |  |  |  | см
 |  | тающих в наиболее |  |  |  |  |  |  |  | Туалет женский | N ж | 47.1
 |  | многочисленную |  |  |  |  |  |  |  |  | см
 |  | смену |  |  |  |  |  |  |  | Помещение для личной гигиены женщин | N ж | 47.1
 |  | Максимальная рас- четная численность рабочих-мужчин в наиболее много- численную смену | Nм раб.см | Nм | = 0,7 · Nм | = 0,7 · 99 | 76.93 |  |  |  | см
 |  | Максимальная рас- четная численность рабочих-женщин в наиболее много- численную смену | Nж раб.см | Nж | = 0,7 · Nж | = 0,7 · 42 | 32.97 |  |  | Помещение для обогрева | Nраб.см | 115.395
 |  | Максимальная рас- четная численность работающих муж- чин в наиболее многочисленную смену | N м см | Nм = 0,7 · Nр | = 0,7 · 111 |  | 89.21220918 |  |  | Помещение для сушилки одежды и обуви | Nраб.см | 115.395
 |  | Максимальная рас- четная численность работающих жен- щин в наиболее многочисленную | N ж см | Nж = 0,3 · Nр | = 0,3 ·111 |  | 38.23380393 |  |  | Места для переодевания | Nраб.см | 115.395
 |  | смену |  |  |  |  |  |  |  | Столовая-раздаточная | 0,25 · Nрmax | 31.86150328
 |  |  |  |  |  |  |  |  |  | Медпункт | При Nраб.сут более 150 чел. 18м2 | 164.85
 |  | Наименование временных зданий | Расчет- ная чис- лен- ность работа- ющих N1 , чел. | Норма- тивный показа- тель площади зданий Sн, м2/чел. | Расчет- ная по- требная площадь Smp, м2 | Приня- тая по- лезная площадь здания S , м2 | Тип здания, его шифр | Габаритные размеры, м | Количество зданий n, шт.
 |  | 1 | 2 | 3 | 4 | 5 | 6 | 7 | 8
 |  | Контора начальника участка | 12.05101311 | 4 | 48.20405244 | 24.4 | 420-04-10 к | 6.04x3.0x2.65 | 2 | 48.8
 |  | Помещения для проведения занятий по технике безопасности | 34 | 0.3 | 10.2 | 17 | ИКТБ | 7,7х2,8х3,4 | 1 | 17
 |  | Диспетчерская | 1 | 7 | 7 | 9,2 | 494-4-9 | 3,7х3,5х3,1 | 1
 |  | Красный уголок | 127.4460131 | 0.75 | 95.58450983 | 24.4 | 494-4-08 | 8.5x3.1x2.7 | 4 | 97.6
 |  | Гардеробные | 109.9 | 0.7 | 76.93 | 20.7 | 5055 | 7,4х3,1х3,1 | 4 | 82.8
 |  | мужские
 |  | Умывальные | 109.9 | 0.065 | 7.1435
 |  | мужские
 |  | Гардеробные | 47.1 | 0.7 | 32.97 | 20.7 | 5055 | 6,0x3,0x2,54 | 2 | 41.4
 |  | женские
 |  | Умывальные | 47.1 | 0.065 | 3.0615
 |  | женские
 |  | Помещение для сушки | 115.395 | 0.15 | 17.30925 | 22 | 420-01-13 п | 9,0x2,7x2,6 | 1
 |  | одежды и обуви
 |  | Место для | 115.395 | 0.1 | 11.5395
 |  | переодевания
 |  | Душевые | 109.9 | 0.287 | 31.5413 | 24,4 | СЦЦ-М к | 9,0x3,0x2,6 | 2
 |  | Мужские с преддушевой
 |  | Душевые с преддушевой | 47.1 | 0.287 | 13.5177 | 14,5 | 420-04-22 к | 6,0´2,7х3 | 1
 |  | Женские
 |  | Помещения для личной гигиены | 47.1 | 0.133 | 6.2643 | 4,3 | 494-4-13к | 2,7х2х2,8 | 2
 |  | женщин
 |  | Уборные | 47.1 | 0.14 | 6.594
 |  | для женщин
 |  | Уборные | 109.9 | 0.07 | 7.693 | 14,3 | 420-04-2к | 6,0x2,7x2,68 | 1
 |  | для мужчин
 |  | Комната от- | 127.4460131 | 0.2 | 25.48920262 | 20,7 | 5055-18 | 7,4х3,1х3,1 | 2
 |  | дыха
 |  | Столовая-раздаточная | 31.86150328 | 0.25 | 7.965375819 | 17,9 | ИС-303 | 7,9х2,8х2,5 | 1
 |  | Помещение | 115.395 | 0.1 | 11.5395 | 14,45 | 420-04-9 к | 6,0x2,7x2,68 | 1
 |  | для обогрева рабочих
 |  | Медпункт | Не менее 18 м2 |  | – | 24,3 | 420-01-13к | 9,0x2,7x2,6 | 1
 |  | 0Конструкции, изделия, материалы | Единица измерения | Общая потребность | Продолжител. укл. мат. констр., дни | Наибол. сут. расход | Число дней запаса | Коэффициент |  | Запас на складе | Норма хранения на 1 м2 пл. склада | Полезная площадь склада, м2 | Коэффициент использования площади склада | Общая площадь склада, м2 | Размер склада, м | Характеристика склада
 |  |  |  |  |  |  |  | пост.мат. | потребления материалов
 |  | 1 | 2 | 3 | 4 | 5 | 6 | 7 | 8 | 9 | 10 | 11 | 12 | 13 | 14 | 15
 |  | Кирпич силикатный | 1000шт | 107.90 | 85 | 1.82 | 6.00 | 1.10 | 1.30 | 10.89 | 0.70 | 15.56 | 0.60 | 25.93 |  | открытый
 |  | Итого
 |  | Арматура | т | 2013.98 | 265 | 10.87 | 12.00 | 1.10 | 1.30 | 130.41 | 4.20 | 31.05 | 0.60 | 51.75 |  | Навес
 |  | Итого
 |  | Штукатурка | т | 55.58 | 40 | 1.99 | 8.00 | 1.10 | 1.30 | 15.90 | 3.60 | 4.42 | 0.60 | 7.36 |  | Закрытый неотапливаемый
 |  | Минеральная вата | м2 | 2969.20 | 40 | 106.15 | 5.00 | 1.10 | 1.30 | 530.74 | 35.00 | 15.16 | 0.60 | 25.27 |  |  | м3
 |  | Линолеум | 100м2 | 80.64 | 40 | 2.88 | 5.00 | 1.10 | 1.30 | 14.41 | 3.50 | 4.12 | 0.60 | 6.86 |  |  | м2
 |  | Итого
 |  | Краска водоэмульсионная | т | 15.51 | 40 | 0.55 | 12.00 | 1.10 | 1.30 | 6.65 | 1.00 | 6.65 | 0.60 | 11.09 |  | Закрытый отапливаемый
 |  | Оконные блоки | т | 376.17 | 40 | 13.45 | 8.00 | 1.10 | 1.30 | 107.59 | 2.50 | 43.03 | 0.60 | 71.72 |  |  | т
 |  | Дверные блоки | м2 | 5.21 | 40 | 0.19 | 8.00 | 1.10 | 1.30 | 1.49 | 2.50 | 0.60 | 0.60 | 0.99 |  |  | т
 |  | Обои | м2 | 140.88 | 40 | 5.04 | 12.00 | 1.10 | 1.30 | 60.44 | 42.00 | 1.44 | 0.60 | 2.40 |  |  | м2
 |  | Итого

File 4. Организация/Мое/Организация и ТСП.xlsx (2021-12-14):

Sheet: Организация
№ | Обоснование | Наименование видов работ | Ед.изм. | Количество | Затраты труда. чел-ч / маш-ч |  | Состав звена
 |  |  |  |  | на ед. | на весь объем |  |  |  | всего
1 | 2 | 3 | 4.00 | 5.00 | 6.00 | 7.00 | 8.00 |  |  | чел часы | #REF!
Подземная часть |  |  |  |  |  |  |  |  |  | маш часы | #REF!
1 | Е1-24-5 | Разработка грунта бульдозером мощностью 79 (108) кВт (л.с.) при перемещении грунта до 10 м. грунт 1 группы | 1000 м3 | 0.24 | 0.00 | 0.00 | Машинист |  |  | сантехника (10%)
 |  |  |  |  | 10.23 | 2.46 |  |  |  | электромонтаж (8%)
2 | Е1-24-13 | Разработка грунта бульдозерами мощностью 79 (108) кВт (л.с.) добавлять на каждые последующие 10 м. грунт 1 группы | 1000 м3 | 0.58 | 0.00 | 0.00 | Машинист |  |  | слаботочечные (2%)
 |  |  |  |  | 8.61 | 5.00 |  |  |  | итого
3 | Е1-30-2 | Планировка площадей бульдозерами мощностью 79 (108) кВт (л.с.) | 1000 м3 | 0.82 | 0.00 | 0.00 | Машинист |  |  | монтаж оборуд (20%)
 |  |  |  |  | 0.27 | 0.22 |  |  |  | пусконалад (5%)
4 | Е1-12-13 | Разработка грунта в отвал экскаватором "ОБРАТНАЯ ЛОПАТА" с ковшом вместимостью 0.5 м3. грунт 1 группы | 1000 м3 | 0.50 | 10.75 | 5.36 | Машинист |  |  | благоустройство (3%)
 |  |  |  |  | 23.36 | 11.64 |  |  |  | итого
5 | Е1-17-13 | Разработка грунта с погрузкой на автомобили-самосвалы экскаваторами с ковшом вместимостью 0.5 м3. грунт 1 группы | 1000 м3 | 2.43 | 12.30 | 29.94 | Машинист |  |  | Неучтенные работы (12%)
 |  |  |  |  | 35.73 | 86.97 |  |  |  | итого
6 | Е1-163-7 | Разработка грунта вручную в траншеях шириной более 2 м и котлованах площадью сечения до 5 м2 с креплениями. глубиной траншей и котлованов до 3 м. грунт 1 группы | 100 м3 | 0.17 | 259.33 | 44.35 | Землекоп – 2ч |  |  | подготовительный период (6%)
 |  |  |  |  | 0.00 | 0.00 |  |  |  | Сдача объекта (1%)
Фундаменты |  |  |  |  |  |  |  |  |  | итого
7 | Е5-1-4 | Погружение дизель-молотом копровой установки на базе трактора железобетонных свай длиной до 10 м. в грунты 1 группы | м3 | 243.20 | 4.35 | 1057.92 | Машинист -2ч
 |  |  |  |  | 2.95 | 717.44 | Монтажник – 4ч
8 | Е6-57-1 | Установка арматуры | Т | 267.40 | 29.78 | 7963.17 | Арматурщик – 6ч
 |  |  |  |  | 0.50 | 133.70
9 | Е6-1-15 | Устройство фундаментных плит бетонных плоских из бетона класса В7.5 | 100 м3 | 2.70 | 116.82 | 315.41 | Бетонщик – 4ч
 |  |  |  |  | 15.26 | 41.20
10 | Е6-100-1 | Устройство монолитных железобетонных наружных стен высотой до 4 м. толщиной 400 мм в опалубке импортного производства типа "модостр" | 100м3 | 1.75 | 388.81 | 680.42 | Каменщик – 4ч
 |  |  |  |  | 83.94 | 146.89
11 | Е8-4-3 | Гидроизоляция стен. фундаментов горизонтальная оклеечная в 2 слоя из рубероида | 100 м2 | 4.03 | 21.91 | 88.30 | Каменщик – 4ч
 |  |  |  |  | 2.17 | 8.75
12 | Е6-57-1 | Установка арматуры | Т | 16.60 | 29.78 | 494.35 | Арматурщик – 6ч
 |  |  |  |  | 0.50 | 8.30
13 | Е6-14-16 | Устройство колонн в деревянной опалубке со стальными сердечниками (жесткой арматурой) из бетона класса с12/15. периметром до 4 м. при отношении объема сердечника или жесткой арматуры к об ему колонн до 25 процентов | 100м3 | 0.14 | 1899.80 | 271.29 | Бетонщик – 6ч
 |  |  |  |  | 47.55 | 6.79
14 | Е6-57-1 | Установка арматуры | Т | 110.80 | 29.78 | 3299.62 | Арматурщик – 6ч
 |  |  |  |  | 0.50 | 55.40
15 | Е6-22-3 | Устройство перекрытий безбалочных из бетона класса С12/15. толщиной более 200 мм на высоте от опорной площади до 6 м | 100 м3 | 1.37 | 678.50 | 928.87 | Бетонщик – 6ч
 |  |  |  |  | 31.93 | 43.71
16 | Е1-27-4 | Засыпка траншей и котлованов бульдозерами мощностью 79 (108) кВт (л.с.) при перемещении грунта до 5 м. грунт 1 группы | 1000 м3 | 0.50 | 0.00 | 0.00 | Машинист – 1ч
 |  |  |  |  | 5.91 | 2.94
17 | Е1-166-1 | Засыпка вручную траншей. пазух котлованов и ям. грунт 1 группы | 100 м3 | 0.17 | 102.91 | 17.60 | Землекоп – 2ч
 |  |  |  |  | 0.00 | 0.00
18 | Е1-134-1 | Уплотнение грунта пневматическими трамбовками. грунт 1 группы | 100 м3 | 5.30 | 12.53 | 66.41 | Землекоп – 2ч
 |  |  |  |  | 12.18 | 64.55
Надземная часть
Несущие конструкции
19 | Е6-57-1 | Установка арматуры | Т | 165.10 | 29.78 | 4916.68 | Арматурщик – 6ч
 |  |  |  |  | 0.50 | 82.55
20 | Е6-14-16 | Устройство колонн в деревянной опалубке со стальными сердечниками (жесткой арматурой) из бетона класса с12/15. периметром до 4 м. при отношении об ема сердечника или жесткой арматуры к об ему колонн до 25 процентов | 100м3 | 1.72 | 1899.80 | 3265.76 | Бетонщик 6ч
 |  |  |  |  | 47.55 | 81.74
21 | Е6-57-1 | Установка арматуры | Т | 1325.60 | 29.78 | 39476.37 | Арматурщик – 6ч
 |  |  |  |  | 0.50 | 662.80
22 | Е6-22-3 | Устройство перекрытий безбалочных из бетона класса С12/15. толщиной более 200 мм на высоте от опорной площади до 6 м | 100 м3 | 13.70 | 208.25 | 2852.40 | Бетонщик 6ч
 |  |  |  |  | 49.47 | 677.59
23 | Е6-57-1 | Установка арматуры | Т | 40.34 | 29.78 | 1201.33 | Арматурщик – 6ч
 |  |  |  |  | 0.50 | 20.17
24 | Е6-105-1 | Устройство монолитных железобетонных лестничных площадок и маршей в опалубке импортного производства типа "модостр" | 100м3 | 0.35 | 637.21 | 226.21 | Бетонщик 6ч
 |  |  |  |  | 133.72 | 47.47
Наружная отделка фасадов
25 | Е8-52-1 | Возведение трехслойных стен из газосиликатных блоков на клею толщиной 300 мм | м3 | 998.13 | 4.70 | 4691.21 | Каменщик – 8ч
 |  |  |  |  | 0.16 | 159.70
26 | Е26-12-3 | Изоляция поверхностей плоских изделиями минераловатными с гофрированной структурой | 10м2 | 296.92 | 7.41 | 2200.18 | Монтажник - 4ч
 |  |  |  |  | 0.98 | 290.98
27 | Е15-327-2 | Декоративная штукатурка типа "байрамикс" наружных поверхностей стен мелкой фракции 0,5 мм с люлек | 100м2 | 29.69 | 89.73 | 2664.08 | Монтажник - 4ч
 |  |  |  |  | 35.99 | 1068.54
Стены и перегородки
28 | Е8-7-502 | Кладка перегородок неармированных толщиной в 1 2 кирпича при высоте этажа до 4 м из кирпича силикатного утолщенного | 100м2 | 28.03 | 143.99 | 4036.47 | Каменщик – 8ч
 |  |  |  |  | 5.72 | 160.35
29 | Е6-18-9 | Устройство перемычек железобетонных из бетона класса с12/15 | 100м3 | 0.75 | 1593.00 | 1194.75 | Бетонщик - 2ч
 |  |  |  |  | 55.70 | 41.78 | Арматурщик - 2ч
30 | Е6-103-1 | Устройство монолитного железобетонного лифтового блока в опалубке импортного производства типа "модостр" | 100м3 | 0.72 | 456.44 | 326.81 | Бетонщик 4ч
 |  |  |  |  | 151.81 | 108.70 | Арматурщик – 2ч
Кровля
31 | Е 12-91-1 | Устройство выравнивающих стяжек под кровлю без армирования толщиной 30 мм | 100м2 | 8.55 | 49.27 | 421.26 | Бетонщик - 4ч
 |  |  |  |  | 1.92 | 16.42
32 | Е12-13-3 | Утепление покрытий плитами из минеральной ваты или перлита на битумной мастике | 100м2 | 8.55 | 45.54 | 389.37 | Кровельщик – 4ч
 |  |  |  |  | 1.68 | 14.36
33 | Е12-115-1 | Огрунтовка оснований кровли механизированным способом |  | 8.55 | 1.17 | 10.00 | Кровельщик – 4ч
 |  |  | 100 м2 |  | 0.52 | 4.45
34 | Е12-15-1 | Устройство пароизоляции оклеечной в один слой | 100м3 | 8.55 | 17.51 | 149.71 | Кровельщик – 4ч
 |  |  |  |  | 1.30 | 11.12
35 | Е12-104-1 | Устройство двухслойных кровель из наплавляемых рулонных материалов при механическом закреплении нижнего слоя водоизоляционного ковра |  | 8.55 | 31.96 | 273.26 | Кровельщик – 4ч
 |  |  | 100 м2 |  | 0.30 | 2.56
36 | Е16-21-1 | Установка воронок водосточных | Шт | 10.00 | 2.94 | 29.40 | Кровельщик – 4ч
 |  |  |  |  | 0.02 | 0.20
37 | Е12-112-1 | Устройство примыканий кровли из наплавляемых рулонных материалов к воронке внутреннего водостока | 100шт | 0.10 | 152.07 | 15.21 | Кровельщик – 4ч
 |  |  |  |  | 0.22 | 0.02
38 | Е12-9-1 | Устройство желобов настенных | 100мжел. | 8.55 | 84.75 | 724.61 | Кровельщик – 4ч
 |  |  |  |  | 2.57 | 21.97
39 | Е12-22-1 | Устройство примыканий к парапетам и другим выступающим частям здания при устройстве покрытия кровли из рулонных материалов | 100м | 0.76 | 81.70 | 62.42 | Кровельщик – 4ч
 |  |  |  |  | 0.96 | 0.73
40 | Е15-379-1 | Облицовка парапета фасадными панелями | 100м пара | 0.76 | 61.28 | 46.57 | Кровельщик – 4ч
 |  |  |  |  | 0.04 | 0.03
Окна
41 | Е10-101-2 | Установка окон из ПВХ со стеклопакетами в проемы кирпичных стен с креплением поворотными анкерами при площади изделия до 2 м2 | 100 м2 | 0.10 | 134.42 | 12.97 | Монтажник – 4ч
 |  |  |  |  | 0.00 | 0.00
42 | Е10-101-3 | Установка окон из ПВХ со стеклопакетами в проемы кирпичных стен с креплением | 100 м2 | 1.94 | 125.62 | 243.70 | Монтажник – 4ч
 |  | поворотными анкерами при площади изделия до 3 м2 |  |  | 0.00 | 0.00
43 | Е10-101-4 | Установка окон из пвх со стеклопакетами в проемы кирпичных стен с креплением поворотными анкерами при площади изделия свыше 3 м2 | 100 м2 | 4.96 | 116.12 | 576.05 | Монтажник – 4ч
 |  |  |  |  | 0.00 | 0.00
44 | Е10-102-2 | Установка блоков окно-балконная дверь из ПВХ со стеклопакетами в проемы кирпичных стен при площади изделия свыше 3 м2 | 100 м2 | 11.09 | 106.32 | 1179.09 | Монтажник – 4ч
 |  |  |  |  | 0.00 | 0.00
45 | Е10-107-1 | Соединение окна и балконной рамы при помощи подставочного профиля | 100 м | 0.75 | 19.60 | 14.70 | Монтажник – 4ч
 |  |  |  |  | 0.00 | 0.00
46 | Е10-104-1 | Установка подоконных досок из ДСП | 100 м | 0.75 | 74.37 | 55.78 | Монтажник – 4ч
 |  |  |  |  | 0.00 | 0.00
47 | Е10-103-1 | Герметизация мест примыкания оконных и балконных блоков из пвх к стенам толщиной зазора 0.03 м | 100 м2 | 2.33 | 13.03 | 30.36 | Монтажник – 4ч
 |  |  |  |  | 0.00 | 0.00
Двери
48 | Е10-23-1 | Установка блоков в наружных и внутренних дверных проемах в каменных стенах. площадь | 100 м2 | 0.06 | 91.40 | 5.48 | Монтажник – 4ч
 |  | проема до 3 м2 |  |  | 13.67 | 0.82
49 | Е10-23-3 | Установка блоков в наружных и внутренних дверных проемах в перегородках и деревянных нерубленых стенах. площадь проема до 3 м2 | 100 м2 | 1.66 | 116.00 | 192.56 | Монтажник – 4ч
 |  |  |  |  | 5.98 | 9.93
50 | Е10-23-5 | Установка блоков для люков в перекрытиях | 100 м2 | 0.02 | 129.00 | 2.09 | Монтажник – 4ч
 |  |  |  |  | 5.82 | 0.09
Внутренние отделочные работы
51 | Е15-69-2 | Отделка поверхностей стен и перегородок из блоков и плит под окраску или оклейку обоями | 100М2 | 122.51 | 11.06 | 1354.96 | Монтажник – 4ч
 |  |  |  |  | 0.10 | 12.25
52 | Е15-315-1 | Улучшенная окраска потолков акриловыми составами по монолитным конструкциям. подготовленным под окраску | 100 м2 | 86.59 | 59.22 | 5127.86 | Монтажник – 4ч
 |  |  |  |  | 0.03 | 2.60
53 | Е15-326-2 | Декоративная штукатурка типа "байрамикс" внутренних поверхностей стен средней фракции 1.0 мм | 100м2 | 32.40 | 78.11 | 2530.76 | Монтажник – 4ч
 |  |  | пов |  | 0.00 | 0.00
54 | Е15-65-1 | Штукатурка плоских поверхностей оконных и дверных откосов по камню | 100 м2 | 2.34 | 204.06 | 477.50 | Штукатурщик – 4ч
 |  |  |  |  | 1.49 | 3.49
55 | Е15-18-1 | Облицовка белыми керамическими глазурованными плитками поверхностей стен в жилых зданиях по кирпичу | 100 м2 | 26.95 | 226.25 | 6097.44 | Плиточник – 8ч
 |  |  |  |  | 0.32 | 8.62
56 | Е15-314-1 | Высококачественная окраска стен внутри помещений акриловыми составами с полной подготовкой поверхности по штукатурке | 100 м2 | 2.34 | 69.42 | 162.44 | Маляр – 4ч
 |  |  |  |  | 0.05 | 0.12
57 | Е15-267-1 | Оклейка стен и перегородок обоями со сплошным шпатлеванием простыми и средней плотности с подбором рисунка | 100 м2 | 122.51 | 38.25 | 4686.01 | Маляр – 4ч
 |  |  |  |  | 0.00 | 0.00
Полы
Тип 1
58 | Е12-13-1 | Утепление покрытий из плит пенополистирольных на битумной мастике в один слой толщиной 10 см | 100 м2 | 1.448 | 21.02 | 30.44
 |  |  |  |  | 1.71 | 2.48
59 | Е12-13-2 | Утепление покрытий из плит пенополистирольных на битумной мастике на каждый последующий слой добавлять к норме 12-13-1 | 100 м2 | 1.8 | 15.03 | 27.05
 |  |  |  |  | 1.71 | 3.08
60 | Е12-15-3 | Устройство пароизоляции прокладочной в один слой | 100 м2 | 1.448 | 7.84 | 11.35
 |  |  |  |  | 1.02 | 1.48
61 | Е11-4-5 | Устройство гидроизоляции обмазочной в один слой толщиной 2 мм | 100 м2 | 1.448 | 26.97 | 39.05
 |  |  |  |  | 1.33 | 1.93
62 | Е11-4-6 | Устройство гидроизоляции обмазочной на каждый последующий слой толщиной 1 мм добавлять по норме 5 | 100 м2 | 1.448 | 9.10 | 13.18
 |  |  |  |  | 0.69 | 1.00
63 | Е11-11-3 | Устройство стяжек цементных толщиной 20 мм | 100 м2 | 1.448 | 32.10 | 46.48
 |  |  |  |  | 1.90 | 2.75
64 | Е11-11-4 | Устройство стяжек бетонных на каждые 5 мм изменения толщины стяжки | 100 м2 | 5.792 | 0.50 | 2.90
 |  |  |  |  | 0.09 | 0.52
65 | Е11-47-3 | Устройство покрытий пола плиткой "грес" на клею по цементной стяжке | 100 м2 | 1.448 | 163.16 | 236.26
 |  |  |  |  | 0.19 | 0.28
Тип 2
66 | Е12-13-5 | Утепление покрытий плитами из легких (ячеистых) бетонов, фибролита или пеностекла насухо | 100 м2 | 5.314 | 33.9 | 180.14
 |  |  |  |  | 3.2 | 17.00
67 | Е11-11-3 | Устройство стяжек бетонных толщиной 20 мм | 100 м2 | 5.314 | 32.1 | 170.58
 |  |  |  |  | 1.9 | 10.10
68 | Е11-4-5 | Устройство гидроизоляции обмазочной в один слой толщиной 2 мм | 100 м2 | 5.314 | 26.97 | 143.32
 |  |  |  |  | 1.33 | 7.07
69 | Е11-4-6 | Устройство гидроизоляции обмазочной на каждый последующий слой толщиной 1 мм добавлять по норме 5 | 100 м2 | 5.314 | 9.1 | 48.36
 |  |  |  |  | 0.69 | 3.67
70 | Е11-11-5 | Устройство стяжек легкобетонных толщиной 20 мм | 100 м2 | 5.314 | 50.23 | 266.92
 |  |  |  |  | 1.9 | 10.10
71 | Е11-11-6 | Устройство стяжек легкобетонных на каждые 5 мм изменения толщины стяжки | 100 м2 | 15.942 | 0.5 | 7.97
 |  |  |  |  | 0.09 | 1.43
72 | Е11-47-3 | Устройство покрытий пола плиткой "грес" на клею по цементной стяжке | 100 м2 | 5.314 | 163.16 | 867.03
 |  |  |  |  | 0.19 | 1.01
73 | Е11-49-1 | Укладка плинтуса из плитки "грес" на клею | 100 м | 3.2 | 36.47 | 116.70
 |  |  |  |  | 0.028 | 0.09
Тип 3
74 | Е11-11-3 | Устройство стяжек бетонных толщиной 20 мм | 100 м2 | 43.2 | 32.1 | 1386.72
 |  |  |  |  | 1.9 | 82.08
75 | Е11-9-2 | Устройство тепло- и звукоизоляции сплошной из плит древесноволокнистых | 100 м2 | 44.2 | 8.06 | 356.25
 |  |  |  |  | 0.97 | 42.87
76 | Е11-34-1 | Устройство покрытий из досок паркетных | 100 м2 | 45.2 | 35.19 | 1590.59
 |  |  |  |  | 1.09 | 49.27
77 | Е11-39-1 | Устройство плинтусов деревянных | 100 м | 10.1 | 7.65 | 77.27
 |  |  |  |  | 0.08 | 0.81
Тип 4
78 | Е11-11-3 | Устройство стяжек бетонных толщиной 20 мм | 100 м2 | 247.1 | 32.1 | 7931.91
 |  |  |  |  | 1.9 | 469.49
79 | Е11-36-1 | Устройство покрытий из линолеума поливинилхлоридного на теплоизолирующей подоснове на клее бустилат | 100 м2 | 247.1 | 27.1 | 6696.41
 |  |  |  |  | 0.7 | 172.97
80 | Е11-40-3 | Устройство плинтусов поливинилхлоридных с креплением шурупами | 100 м | 78.1 | 6.71 | 524.05
 |  |  |  |  | 0 | 0.00
Отмостка и крыльца
84 | Е1-164-1 | Разработка грунта вручную в траншеях глубиной до 2 м без креплений с откосами. грунт 1 группы | 100 м3 | 1.12 | 137.23 | 153.70 | Землекоп – 4ч
 |  |  |  |  | 0.00 | 0.00
85 | Е11-2-1 | Устройство уплотняемых трамбовками подстилающих слоев гравийных | м3 | 26.50 | 3.41 | 90.37 | Землекоп – 4ч
 |  |  |  |  | 0.22 | 5.83
86 | Е11-2-4 | Устройство уплотняемых трамбовками подстилающих слоев щебеночных | м3 | 23.20 | 3.73 | 86.54 | Землекоп – 4ч
 |  |  |  |  | 0.46 | 10.67
87 | Е11-19-3 | Устройство покрытий асфальтобетонных жестких толщиной 25 мм | 100 м2 | 0.16 | 16.16 | 2.59 | Бетонщик – 4ч
 |  |  |  |  | 3.27 | 0.52
88 | Е8-27-1 | Устройство крылец с входной площадкой | м2 | 66.33 | 1.67 | 110.77 | Бетонщик – 4ч
 |  |  |  |  | 0.11 | 7.30
89 | Е12-15-1 | Устройство пароизоляции оклеечной в один слой рубероида | 100 м2 | 0.16 | 17.51 | 2.80 | Монтажник – 4ч
 |  |  |  |  | 1.30 | 0.21
90 | Е12-4-1 | Устройство примыканий из рубероида к стенам высотой до 600 мм без фартуков | 100 м | 0.30 | 26.10 | 7.96 | Монтажник – 4ч
 |  |  |  |  | 1.16 | 0.35
Итого |  |  |  |  |  | 128412.45
 |  |  |  |  |  | 6620.48
Сантехнические работы (10%) |  |  |  |  |  | 12841.25
Электромонтажные работы (8%) |  |  |  |  |  | 10273.00
Слаботочные работы (2%) |  |  |  |  |  | 2568.25
ИТОГО |  |  |  |  |  | 154094.94
Монтаж оборудования (20%) |  |  |  |  |  | -
Пусконаладочные работы (5%) |  |  |  |  |  | -
Благоустройство территории (3%) |  |  |  |  |  | 4622.85
ИТОГО |  |  |  |  |  | 158717.79
Неучтенные работы (12%) |  |  |  |  |  | 19046.13
ИТОГО |  |  |  |  |  | 177763.92
Подготовительный период (6%) |  |  |  |  |  | 10665.84
Сдача объекта (1%) |  |  |  |  |  | 1777.64
ИТОГО |  |  |  |  |  | 190207.40
 |  |  |  |  |  |  |  |  | 23775.92488
№ | Шифр | Наименование работ | Трудоем-кость | Трудоем-кость | Кол. рабочих в смену | Кол-во | Продол-житель-ность
п/п | работы |  | работ | работ |  | смен
 |  |  | чел-ч | чел-дн
1 | 2 | 3 | 4.00 | 5.00 | 6.00 | 7.00 | 8.00
 | - | Подготовительный период | 10665.84 | 1333.23 | 22.00 | 2.00 | 25.25 | 26
 | 2020-01-03 | Срезка растительного слоя и планировка площадки | 7.68 | 0.96 | 1.00 | 2.00 | 0.40 | 1
 | - | Неучтенные работы | 19046.13 | 2380.77 | 3.00 | 2.00 | 396.79 | 349 | сколько нужно будет
 | 2020-04-05 | Разработка грунта экскаватором | 98.61 | 12.33 | 2.00 | 2.00 | 2.57 | 3
 | 7 | Забивка свай | 717.44 | 89.68 | 4.00 | 1.00 | 18.68 | 20
 | 6,8,9 | Устройство монолитной фундаментной плиты | 8322.93 | 1040.37 | 16.00 | 2.00 | 27.09 | 28 | 84
 | 2020-10-18 | Устройство подвала+ГИ, обратная засыпка и уплотнение грунта | 5846.85 | 730.86 | 16.00 | 2.00 | 19.03 | 20 | 104
 | - | Ввод инженерных сетей | 1207.60 | 150.95 | 4.00 | 2.00 | 15.72 | 16 |  | 198
 | 19-24, 30 | Устройство монолитного каркаса здания | 52265.55 | 6533.19 | 20.00 | 2.00 | 136.11 | 150 | 254 | 176
 | 25,28-29 | Кладка перегородок и стен 10-9 этаж | 4336.00 | 542.00 | 20.00 | 2.00 | 13.55 | 16
 |  | Кладка перегородок и стен 8-7 этаж | 4336.00 | 542.00 | 20.00 | 2.00 | 13.55 | 16 |  | 374
 |  | Кладка перегородок и стен 6-5 этаж | 4336.00 | 542.00 | 20.00 | 2.00 | 13.55 | 16
 |  | Кладка перегородок и стен 4-3 этаж | 4336.00 | 542.00 | 20.00 | 2.00 | 13.55 | 16
 |  | Кладка перегородок и стен 2-1 этаж+подвал | 4336.00 | 542.00 | 17.00 | 2.00 | 13.28 | 16
 | 31-40 | Устройство кровли | 2121.81 | 265.23 | 16.00 | 1.00 | 13.81 | 14
 | 26-27 | Отделка фасада | 4864.26 | 608.03 | 12.00 | 1.00 | 42.22 | 46
 | 84-90 | Устройство отмостки и крылец | 454.72 | 56.84 | 16.00 | 1.00 | 3.55 | 4
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

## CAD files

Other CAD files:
3. ТСП/Мое/ТСП.dwg
3. ТСП/Пример/1 монолит каркас, рулонная кровля/ТСП Лапехо.dwg
3. ТСП/Пример/2 кладка стен из газосиликата/steny_kladka.dwg
3. ТСП/Пример/3 сб фунд и плиты перекрытия/TK (1).dxf
3. ТСП/Пример/4 кирпич кладка/tk_kirp_kl.dwg
4. Организация/Курсовой/графика исправленная.dwg
4. Организация/Мое/Организация.dwg
4. Организация/Пример диплома/2/ОСП.dwg
4. Организация/Пример диплома/ОСП стройгенпланатас.dwg
4. Организация/Курсовой/графика исправленная_recover.dwg
4. Организация/Пример диплома/ОСП показать.dwg

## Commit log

2021-12-14 push project
    [TK (1).dxf, ekonomika объектный.xlsx, ekonomika сводный сметный.xlsx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]
2021-12-14 Create Листы А1 autocad.rar
